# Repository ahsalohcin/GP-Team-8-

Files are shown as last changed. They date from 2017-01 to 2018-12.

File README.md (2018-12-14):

# Grand PrIEEE (senior year of undergrad, 2016-2017)

Led a team of 5 for IEEE-sponsored competition for designing a line-following RC car from scratch.

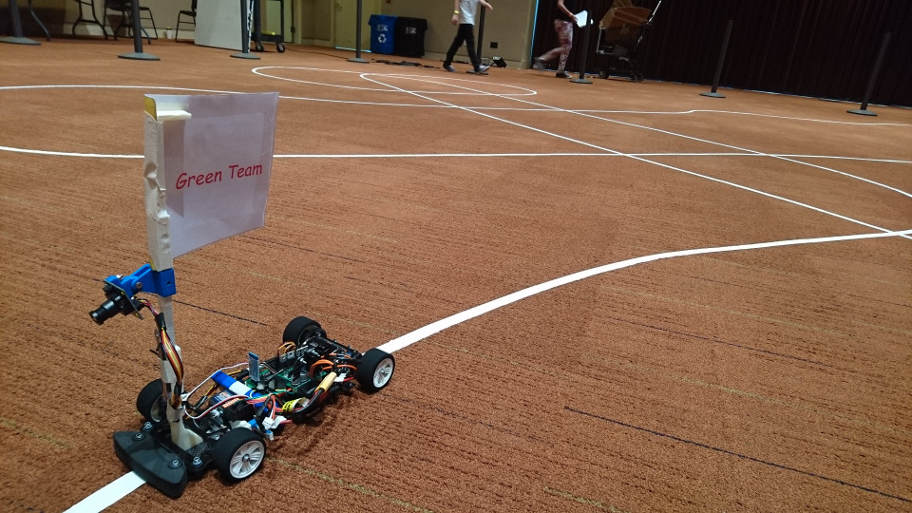
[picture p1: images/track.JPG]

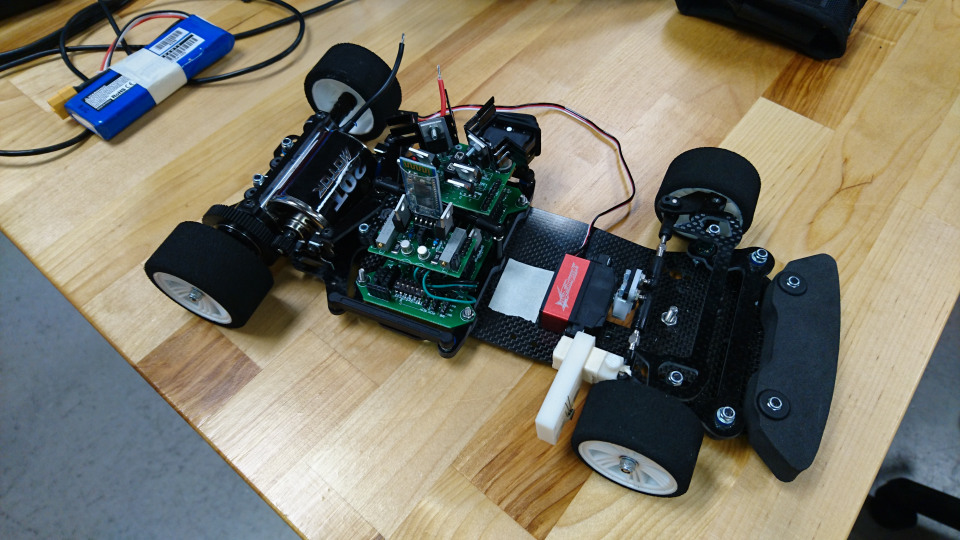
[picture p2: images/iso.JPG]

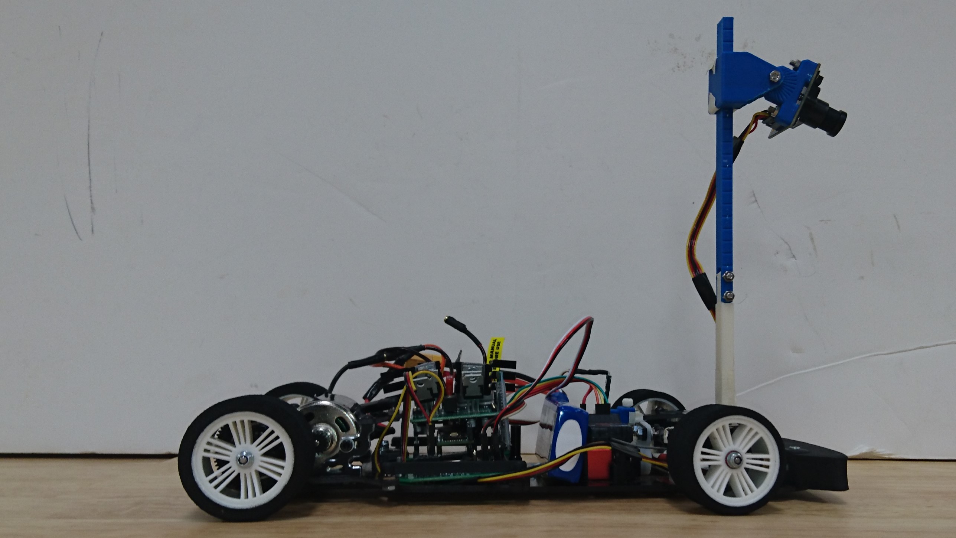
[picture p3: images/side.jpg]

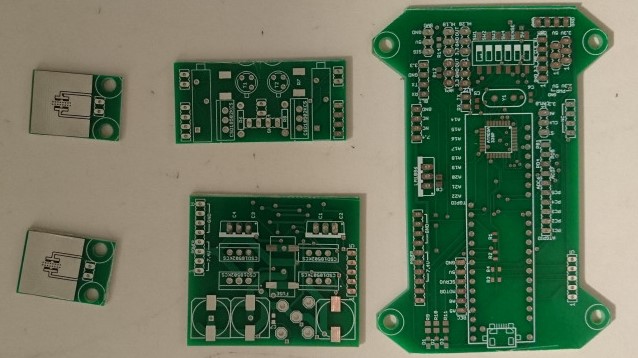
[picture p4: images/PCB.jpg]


## Competition videos: 
* UC San Diego (3rd place): https://www.youtube.com/watch?v=oybaJ443wYY 
* UC Davis (4th place):  https://www.youtube.com/watch?v=VBZ95nvLsOQ& 

## Overview: 
* 1/12 scale RC car + custom PCB
* __Microcontroller__: Teensy (Arduino based)
* __Sensors__: line camera and hall effect speed sensor
* __Actuators__: servo and brushed DC motor (with custom designed motor driver circuit)
* __Controllers__: PD for steering, PI for speed

## Skills learned: 
* Project management
* Design and integration (mechanical, electrical, and software)
* PCB layout
* Control design and tuning

## Main code: 
https://github.com/ahsalohcin/GP-Team-8-/blob/master/Code_5_7/GP_teensy/GP_teensy.ino

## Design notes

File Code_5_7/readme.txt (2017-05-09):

GrandPrIEEECode: the code used for Grand PrIEEE competition that got 36 sec and 3rd place.

vRef: 9.5 ft/sec. adding phone camera with same vRef got a 33 to 34 sec runtime. 

Batt voltage: ~ 8.1 V
Camera setting: 5th notch down
Looptime: 
Line detection: median filter using 5 elements. 
Line widths: 1 - 15 pixels.
Slightly faulty line loss handling. Always goes left. Not using time averaging. 

Steering Kp: 9.84 
Speed Kp: 3.0 Ki: .05
Slow down on turns: speed drop is proportional to curvature, with a slope of 2.5, and maximum drop of 2 ft/sec

Operation:

Turn on Teensy switch. Turn on transmitter. Right joystick max up. Turn on big switch. Expect slight rev, then pause. Release right joystick to start. Adjust vRef using Dip switches

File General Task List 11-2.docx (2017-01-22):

ems level diagram. Hardware showing voltages/currents/signals, and software showing communication General Task List

11/2

- Good, detailed syst and calculations/functions. As much detail as possible.
- Evaluate whether motor driver design is good enough.
  - Establish nominal and extreme load cases
    - Conduct simulation in SPICE
    - Hand calculations to prove that overcurrent, overheating, or other malfunctions won’t happen to FETs.
    - Prepare for motor driver circuit testing: test plan with objective, parts, tools, procedure.
      - Learn how to use gate drivers
      - Write code to control motor speed
      - Obtain test load that simulates motor ( R, L, V_induced (if possible))
      - Assemble circuit
      - Find breaking point
- Choose speed feedback method
  - Optical or magnetic encoder
  - Hall effect sensor
  - Back-EMF from motor
- Track down connector for camera
- Optimize code for light input for speed and robustness
  - Look at output from O-Scope
- Determine what/how to store line data
- Determine what/how to store track data
  - Goals:
    - Take very little time between memory and performance modes.
    - Remember track after power down.
    - Allow it to speed up coming out of turns and slow down before turns.
- Determine what raspberry pi zero accessories we need to use it. For testing (our own use) or for implementation on the actual car.
  - Adjust steering coefficients wirelessly from camera without needing to turn off code
    - Kp/ Ki/ Kd, for steering and speed.
  - Have a remote kill switch that
    - Cuts power to motor driver and remembers track
    - Cuts power to everything
  - Make sure it powers down safely
- Look for a better chassis: braking options, lower weight or lower center of gravity
- Find cheaper place to buy motor
- Find battery

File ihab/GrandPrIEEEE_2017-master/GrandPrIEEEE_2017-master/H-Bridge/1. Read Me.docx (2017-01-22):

Motor Driver:

- Switches:

The first step to designing the motor driver is selecting the type of switches to use. You should start online by looking up H-Bridge basics (try modularcircuits). You don’t have to dive too deep into MOSFETS. Get a solid understanding of the basic concepts that will allow you to look at a datasheet and have an idea of what the different parameters mean, and why you should select certain specs to improve the performance of your motor driver (H-Bridge).

When you are done reading about MOSFETS, you should know what PWM, VGS, VDS, ID, RDS-ON, input capacitance mean, and how they can influence the switching characteristics of the MOSFET. You should also get a basic understanding of the heat dissipation characteristics such as Thermal Resistance Junction to Case (RθJC) and Thermal Resistance Junction to Ambient (RθJA). This will help you select the proper heatsinks to make sure you don’t see magic smoke

You should also be familiar with BJTs but in a much more basic way. Just know how to bias them to turn on and off, for both NPNs and PNPs. You may need to bias your MOSFETS using BJTs if you decide to not go with a gate driver.

Moreover, read up a bit on Schottky diodes. In particular, their use in H-Bridges to prevent “fly-back” current. MOSFETS typically have built in diode-like behavior (see datasheets). However, depending on your design, it may be important to use external ones.

A quick google search can get you going. I have also included a summary of some useful info that I found online, but it is incomplete. You should not go over that until AFTER you have done your research.

I have included some datasheets for NMOS and PMOS by Fairchild, as well as other components for you to look at. Keep in mind, those might be good for testing but if you decide to make a PCB, you will need to spec out some surface mount ones. But at that point, you should know what you are doing.

Your next step will be to look into gate drivers (more to be added).

Grand PrIEEE 2017 Salameh UC San Diego Updated 10/26/2016

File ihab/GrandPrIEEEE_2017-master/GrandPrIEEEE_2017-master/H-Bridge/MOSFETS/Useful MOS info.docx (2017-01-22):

  - H-Bridge Components:
    - MOSFET:
      - Why choose NMOS?
        - NMOS has lower Rds-on than PMOS; therefore lower power dissipation
        - NMOS are faster than PMOS; because electrons travel faster than holes
        - PMOS are more immune to noise; but that is not an issue for this application
      - Which NMOS to choose?
        - Must handle enough current (conservative estimate Id>20A)
        - Must tolerate enough voltage (conservative estimate Vds>30V)
        - Heat dissipation & Switching Frequency:
        - Low Rds-on means lower power dissipation in form of heat
        - BUT, the lower rdson gets, the bigger the MOSFET becomes. The bigger the physical device is, the bigger it’s gate will be. The gate forms a capacitor towards the source and the drain. Since MOSFETs are voltage driven devices, their gate-source voltage has to be in a certain range (usually above 5-10V) to be fully turned on, and in another range (less than a volt or so) to be turned off. So, the on and off transient has to charge and discharge these parasitic capacitors. If you have only limited current available to drive the gate (and you always do), the higher the gate-capacitance is, the longer it takes to charge or discharge it
        - ALSO, MOSFETs have a low rdson when they are fully on, and they conduct almost no current when they’re are completely off. In both cases the dissipated power is relatively low. However when they transition between these two states, there will be a short period where rdson is relatively high, but not high enough to stop significant current from flowing through the device. In these transitional periods both the voltage drop on the device (due to rdson) and the current through it are significant, resulting in high power-dissipation. Naturally you would like to keep this transition time as low as possible from this perspective (we’ll talk later about reasons why you don’t want it to be too fast either), so a higher gate-capacitance will not be desirable. With a given gate-drive strength the gate capacitance limits the speed by which the element can be turned on and off, and thus poses an operating frequency limit

http://modularcircuits.tantosonline.com/blog/articles/h-bridge-secrets/mosfets-and-catch-diodes/

        - For an N-channel device however the picture is more complicated. If you connect the gate to ground or to source, the device is opened (gate-source voltage is below or equal to 0). But where to connect it to close the device? The power supply is not enough, since, when the device is closed (conducts current), it’s source and drain are roughly at the same potential. Since the drain is connected to power, the source will be at that potential as well, but than gate should be higher than that to keep the device closed. In fact at minimum 5V higher for so-called logic-level MOSFETs and 10-15V higher for normal MOSFETs. This is a significant problem, that voltage somehow has to be generated. In most cases some kind of a charge-pump is used for that, either in a stand-alone or a boot-strapped configuration. The latter however is only useful if the bridge is driven in the ‘locked anti-phase’ mode (see later). In any case, these high-side drivers usually cannot deliver as much current as a regular low-side driver can, which means longer turn-on and -off times for the high-side (lower current takes longer to charge-discharge the gate-capacitance). In high-frequency operation, where switching loss is a significant factor, a P-channel MOSFET might be a better solution because of this. In low-frequency, high-current operation, where switching loss is not a problem, but channel-resistance is, N-channel transistors are usually a better compromise.
          - http://modularcircuits.tantosonline.com/blog/articles/old-h-bridge-secrets/part-1/
        - The junction-to-ambient thermal resistance, that tells you how much hotter the chip is than the air that surrounds the package
        - The junction-to-case thermal resistance, that tells you how much hotter the chip inside the package is than the outside of the case at a certain power dissipation
        - the maximum allowed junction temperature
        - When working with surface-mount packages, it is important to note that thermal characteristics are highly dependent on the actual PCB layout. Take the traditional SO-8 package as an example (one typical FET datasheet is here for the FDS8447 (http://www.fairchildsemi.com/ds/FD/FDS8447.pdf)) You’ll see that with just the minimum amount of copper on the board the package has ~125oC/W thermal resistance. With a 6.5cm² (1in²) copper area, the same number is less then half of this, ~50oC/W. Let’s say now that the device itself can operate up to 150oC (this is called the maximum allowed junction temperature). If you can keep the surrounding temperature (called ambient temperature) below 50oC, you can can dissipate somewhere between 0.8W ((150-50)/125) and 2W ((150-50)/50) of power on the FET depending on your PCB layout.

Power MOSFET Basics: Understanding Gate Charge and Using it to Assess Switching Performance

Application note 608 – Vishay Siliconix

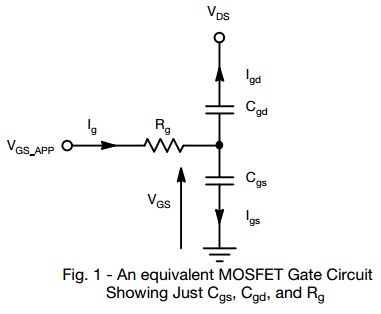
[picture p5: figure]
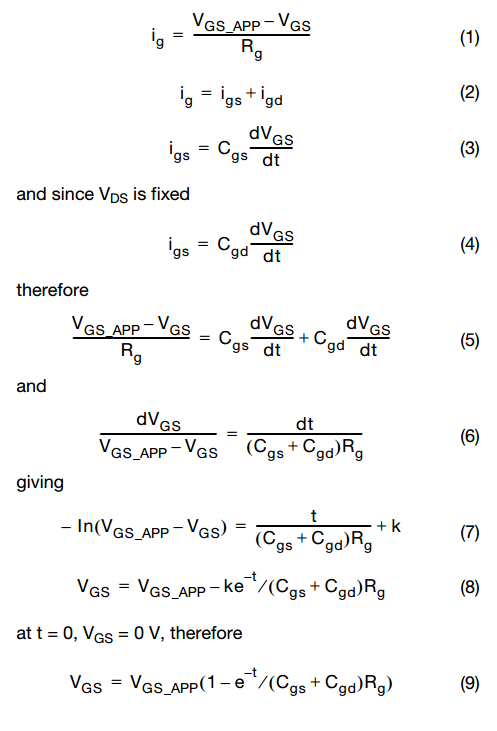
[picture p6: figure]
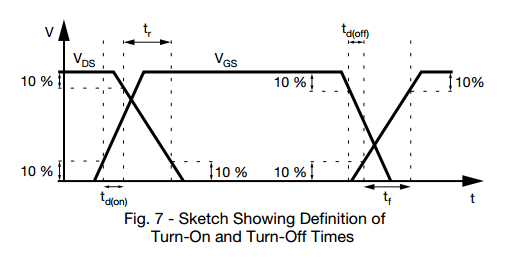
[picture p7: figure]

the switching times of the MOSFET are affected not only by the parasitic elements, but also by the driving circuit.

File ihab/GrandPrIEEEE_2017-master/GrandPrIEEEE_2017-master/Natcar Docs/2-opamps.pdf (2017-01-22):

### NATCAR – Background Information Lecture #1 – Operational Amplifiers

Prof. Richard Spencer

### Op Amp Circuits

- Review of basic op amp operation
- Negative feedback & virtual short circuit
- Gain circuits
- Frequency-dependent circuits
- Offsets
- Slew rate and full-power bandwidth

### Basic Op Amp Review

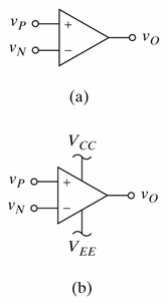
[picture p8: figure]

The power supply connections are not usually shown (but should be when you build and debug your circuits).

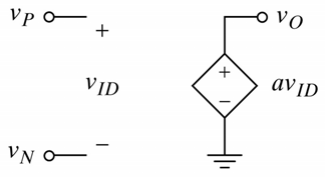
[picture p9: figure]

O | P | N ( | )
O | ID
v | av | v
v | av
= | −
=

The simplest circuit model is shown above and the output voltage is given by:

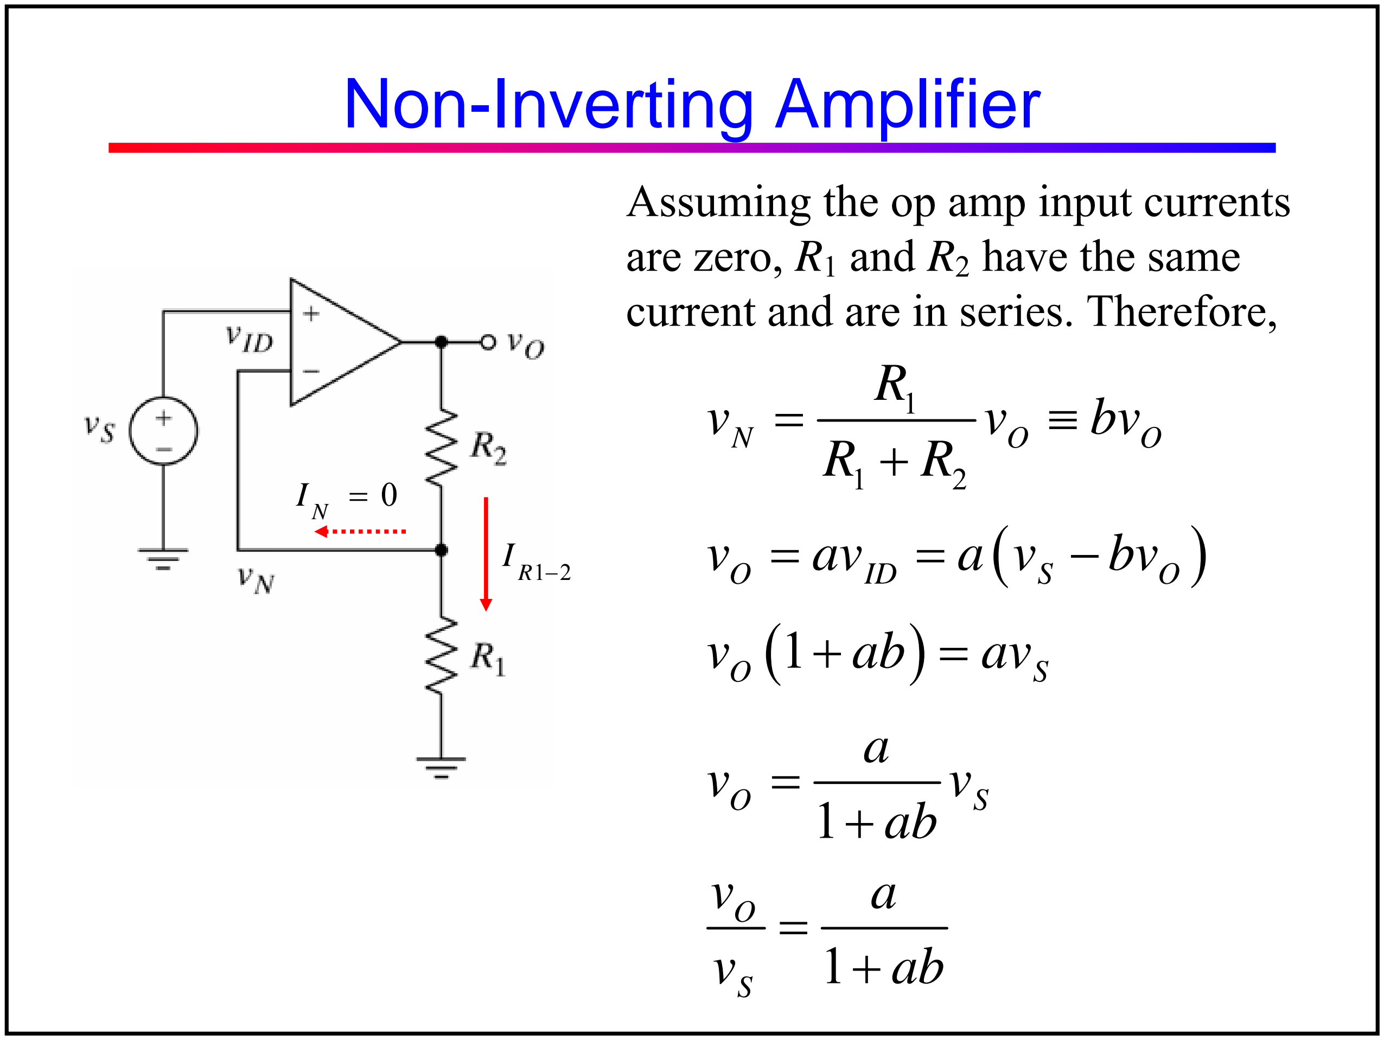
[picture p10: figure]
Non-Inverting Amplifier; Assuming the op amp input currents are zero, R1 and R2 have the same current and are in series. Therefore,

### Non-Inverting Amplifier

1

O

S

v | a
v | ab = +
1 | 2 | 2
1 | 1
1 lim | 1
a | 1
a | RR | R
→∞ | ab | b | R | R
⎛ | ⎞ | + ⎜ | ⎟ = = | =+ ⎝ | ⎠ +

Note negative feedback - key element

1

1 | 2
N | O | O
R v | v | bv
RR
= | ≡
+
v | a v | bv O | S | O = ( − | )

Assuming the op amp input currents are zero;

feedback factor

closed-loop gain

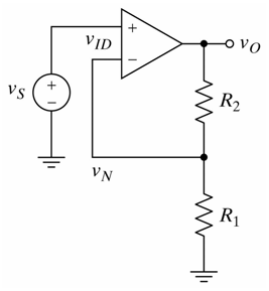
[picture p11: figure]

With an ideal op amp, the
gain is infinite, so

ab = loop gain

### Virtual Short Circuit

1

1 | 2
1) N | O | O
R v | v | bv
RR
= | ≡
+
2) v | av | a v | bv O | ID | S | O = | = | − ( | )
3) | 1 O | S

a
v | | v | | ab = +

We had;

Therefore;
1 1
1 | 1 ID | S | N | S | O | S | S
ab v | v | v | v | bv | v | v
ab | ab
⎛ | ⎞ | ⎛ | ⎞ =− =− | = | − | = ⎜ | ⎟ | ⎜ | ⎟ ⎝ | ⎠ | ⎝ + | + ⎠ NOTE:
as | , | 0 | VIRTUAL SHORT CIRCUIT ID a | v →∞ | → | ⇒

A virtual short requires negative feedback and large loop gain.

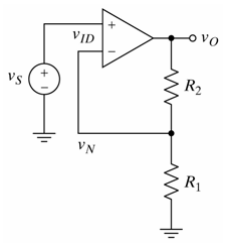
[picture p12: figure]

It is a “virtual” short because no current can flow through it.

### Virtual Short Circuit

We had;

Therefore;
1 1
1 | 1 ID | S | N | S | O | S | S
ab v | v | v | v | bv | v | v
ab | ab
⎛ | ⎞ | ⎛ | ⎞ =− =− | = | − | = ⎜ | ⎟ | ⎜ | ⎟ ⎝ | ⎠ | ⎝ + | + ⎠ NOTE:
as | , | 0 | VIRTUAL SHORT CIRCUIT ID a | v →∞ | → | ⇒

1

1 | 2
1) N | O | O
R v | v | bv
RR
= | ≡
+
2) v | av | a v | bv O | ID | S | O = | = | − ( | )
3) | 1 O | S

a
v | | v | | ab = +

### Virtual Short Circuit

The justification often given for the virtual short circuit (or virtual ground) is:
1) | O | ID v | av =
2) a →∞
3) must be finite Ov
4) | , | 0 ID ∴ v →

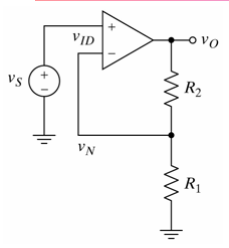
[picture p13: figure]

This syllogism is not valid! Note that reversing the signs on the opamp inputs would not affect the syllogism, but the result is clearly wrong in that case.
The problem is equivocation; | | | assumes that the opamp
operates in its normal region, while saying vo is finite requires that the output be saturated, and a approaches zero there!
| a →∞

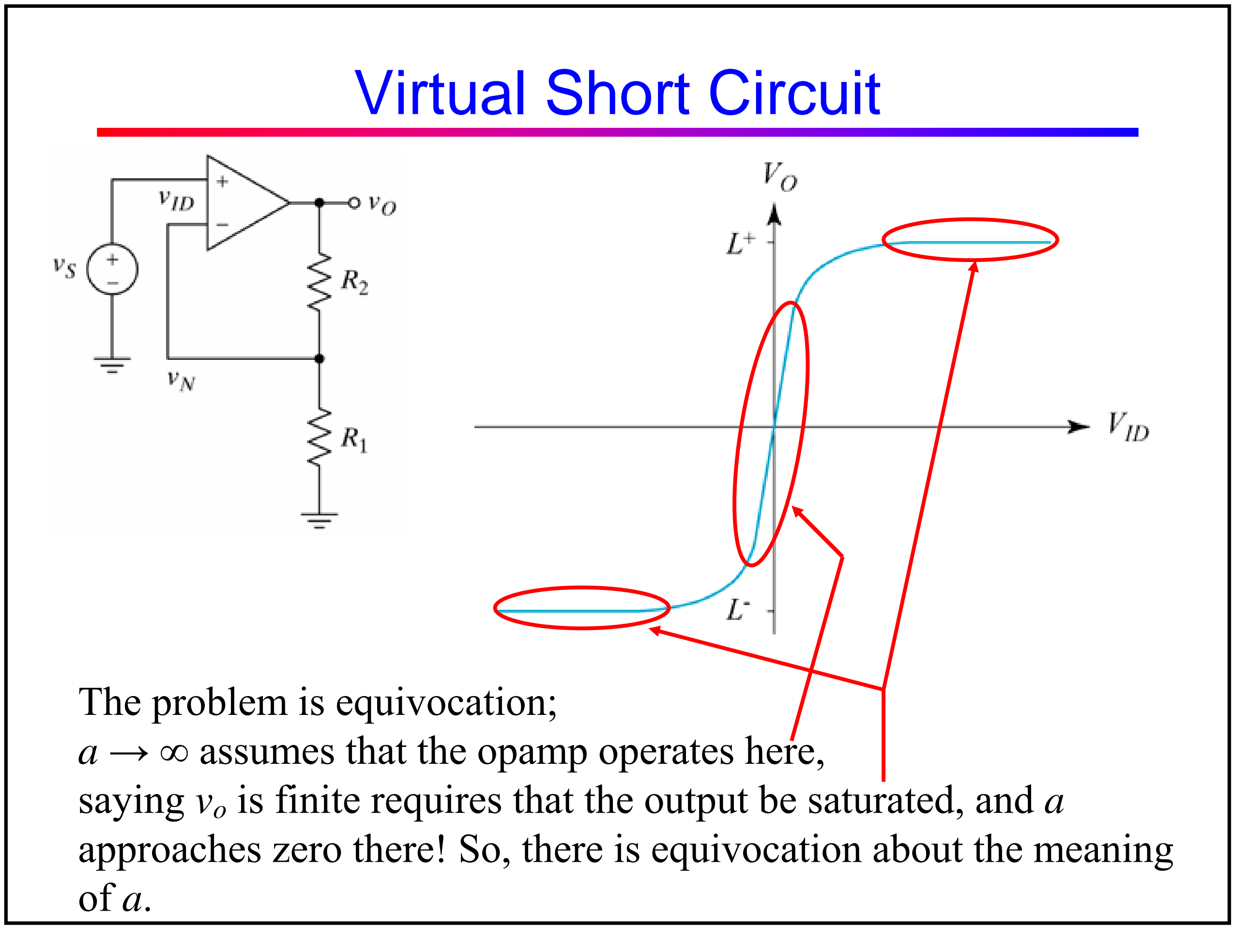
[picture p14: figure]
Virtual Short Circuit; The problem is equivocation;

a →∞ assumes that the opamp operates here,
saying vo is finite requires that the output be saturated, and a approaches zero there! So, there is equivocation about the meaning

### Inverting Amplifier

Negative feedback and large loop gain imply a virtual short (or virtual ground here), so

1
1
0 and | S
N | P | R
v v | v | i
R = = | =

No input current implies that

R1 | 2 R i | i =

so we obtain,

2

2
2
1
O | N | R | S
R v | v | iR | v
R

− =− =

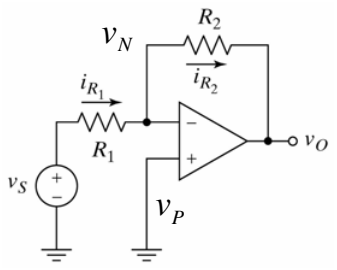
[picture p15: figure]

Note that the virtual ground allows us to think of the
operation as a V-to-I
conversion followed by an
I-to-V conversion.

### A Summing Amplifier

- Using this alternate view of the operation allows us to see how to make summing amplifiers:

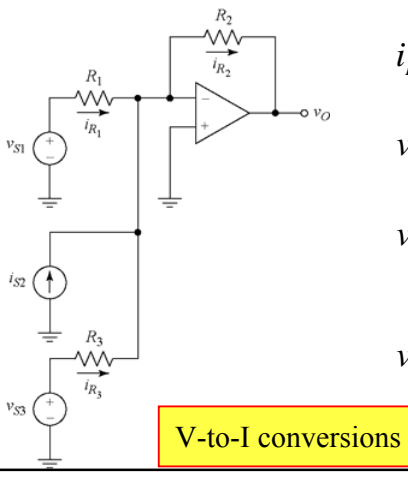
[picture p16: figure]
V-to-I conversions

R2 | 1 | 2 | 3 R | S | R i | i | i | i = ++
O | R22 v | iR = −
( | ) O | R | S | R 1 | 2 | 3 | 2 v | i | i | iR = − | ++
1 | 3
2 | 2
1 | 3
S | S
O | S
v | v v | i | R
R | R
⎛ | ⎞
=− | + + ⎜ | ⎟ ⎝ | ⎠
- I-to-V conversion

### A Low-Pass Filter (Integrator)

- The alternate view of the operation also allows us to see how to make low-pass filters (integrators):
O | FF | F 1 v | i Z | iZ = − | =−

1
1

S v i
R =

Therefore,

1

F
O | S

Z
v | v
R

− =

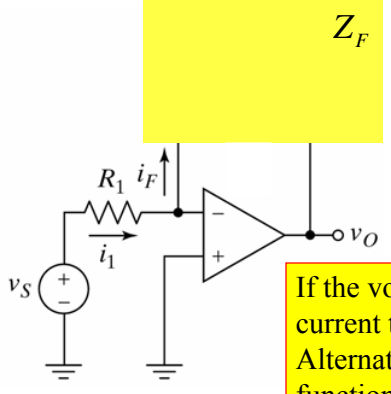
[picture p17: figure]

If the voltage across Zf is the integral of the current through it, we get an integrator. Alternatively, if we make Zf have a LP xfer function, we get a LPF. So, what do we use?

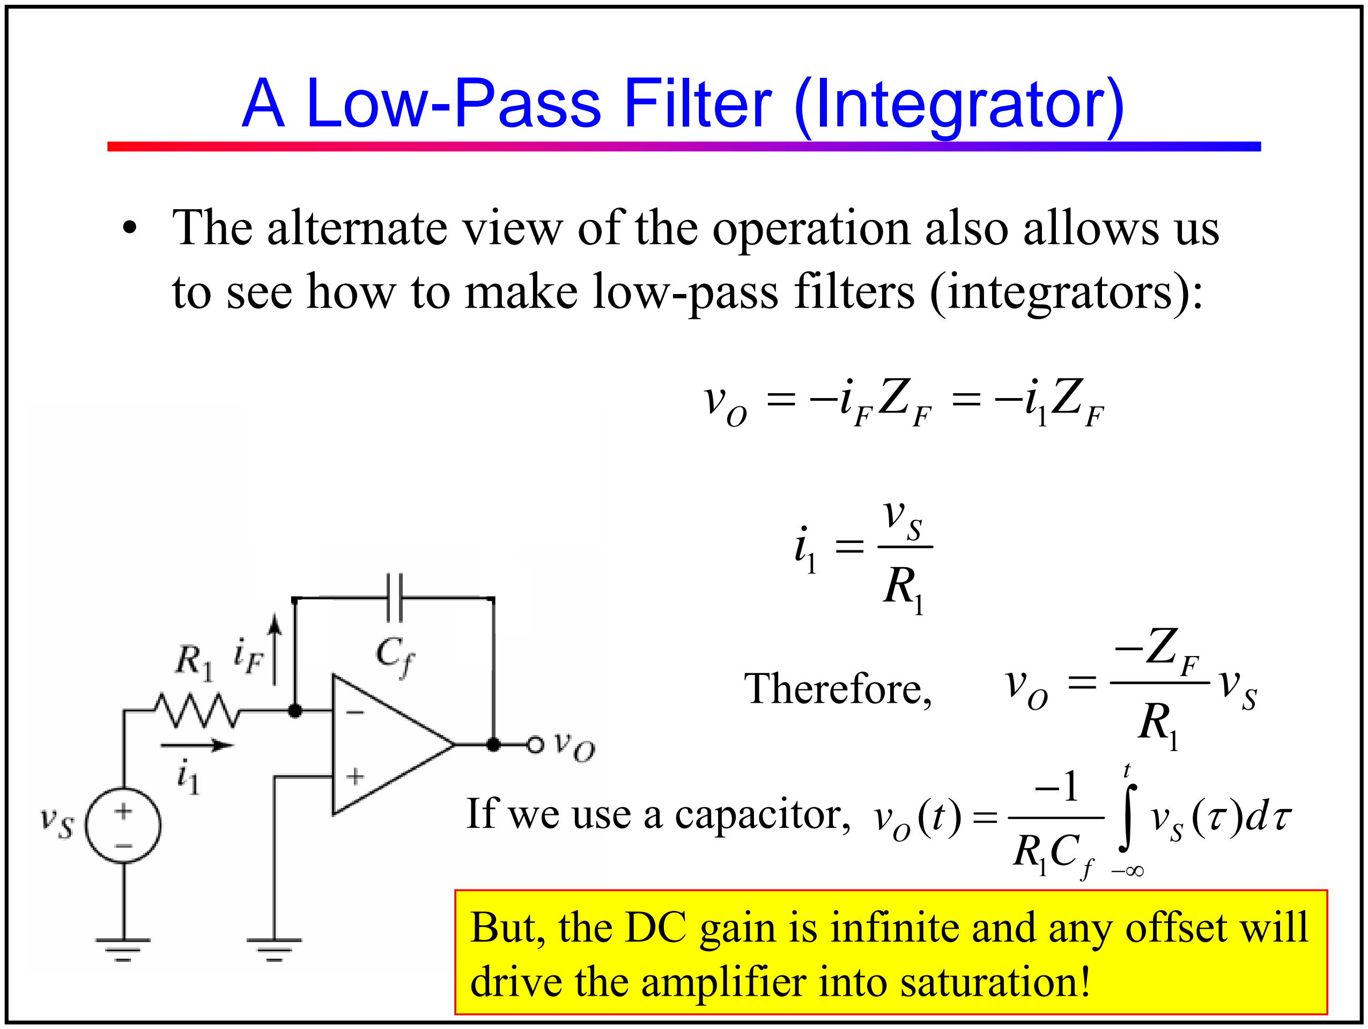
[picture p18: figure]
A Low-Pass Filter (Integrator); Therefore,; If we use a capacitor,; drive the amplifier into saturation!

- The alternate view of the operation also allows us to see how to make low-pass filters (integrators):

But, the DC gain is infinite and any offset will

### A Low-Pass Filter (Integrator)

- Therefore, we use a resistor in parallel with the capacitor to bring the DC gain down:
( | )
( | )
1 | 1
1 | 0

1

1 | 1
O | F | f
S | ff

f

ff
p
v | Z | | R
v | R | R | j RC
| | RR | A
| | j RC | j ω
| | ω | ω
ω
− | − = | = | +
− = | = + | +

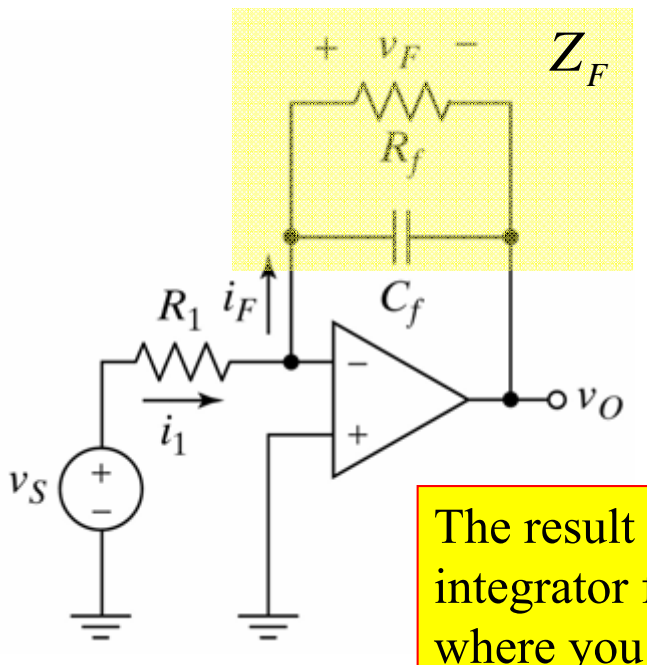
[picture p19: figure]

The result is a LPF, but a LPF looks like an integrator for frequencies well above the pole where you can ignore the ‘1’ in the denominator.

0
1
1 where | and f

p
f f
R A | R | R C =− | = ω

### A High-Pass Filter (Differentiator)

- Similarly, we see how to make high-pass filters (differentiators):
O | Ff | f 1 v | i R | iR = − | =−

1
1

1

1

S | S

S

v | v i
Z | R
jωC

= =
+

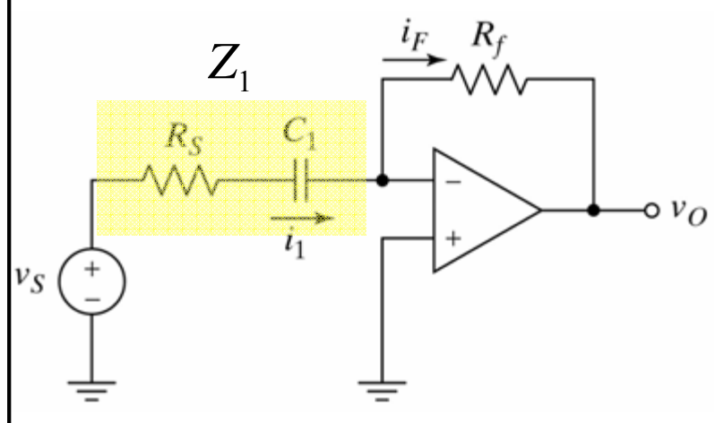
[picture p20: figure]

Therefore,
1
1 1
O | f
S | S
v | j RC
v | j RC ω
| ω

− = +

1
1
1 1 | S
S
j C i | v
j RC

ω
ω = +

### The HPF as a Differentiator

- We can see how this circuit functions as a differentiator (approximately) by assuming that RS is negligible (i.e., we can ignore the voltage drop across it):
Then | 1 | 1

S dv iC
dt

≈

and

1 | 1

S
O | f | f
dv v | iR | R C
dt

=− ≈−

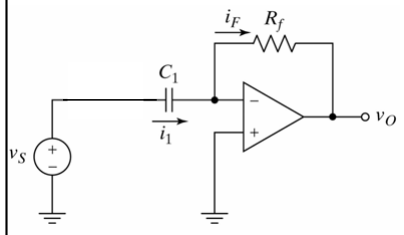
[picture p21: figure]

Note that a perfect differentiator does not have any poles, but we can’t avoid having one since RS = 0 is impossible.

### The HPF as a Differentiator

- We can see how this circuit functions as a differentiator (approximately) by assuming that RS is negligible (i.e., we can ignore the voltage drop across it):
Then | 1 | 1

S dv iC
dt

≈

and

1 | 1

S
O | f | f
dv v | iR | R C
dt

=− ≈−

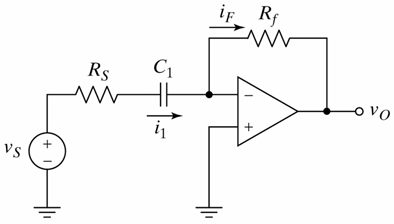
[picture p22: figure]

In addition, we want the pole to be there – increasing gain at high frequencies without limit is not desirable; we would just be amplifying noise.

### The HPF as a Differentiator

- We can see how this circuit functions as a differentiator (approximately) by assuming that RS is negligible (i.e., we can ignore the voltage drop across it):
Then | 1 | 1

S dv iC
dt

≈

and

1 | 1

S
O | f | f
dv v | iR | R C
dt

=− ≈−

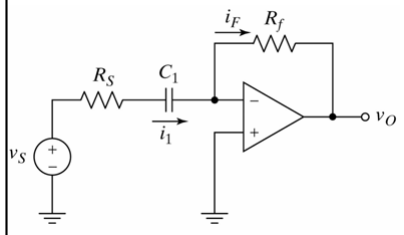
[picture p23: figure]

With the pole, the gain of this circuit asymptotically approaches –Rf /RS as the frequency approaches infinity. With small RS, you probably want to roll that off again at higher frequencies!

### Real Integrators & Differentiators

- To summarize about integrators & differentiators:
- We cannot build a real integrator, it would have infinite DC gain and would saturate. But, a single-pole low-pass filter (LPF) is indistinguishable from an integrator when used at frequencies well above the pole.
- Similarly, a single-pole high-pass filter (HPF) is indistinguishable from a differentiator when used at frequencies well below the pole frequency. Real differentiation is undesirable because the continually increasing gain at high frequencies amplifies noise.

### Input Bias Currents

- All real op amps have non-zero input bias currents
- We model these as current sources as shown in part (b) of the figure below

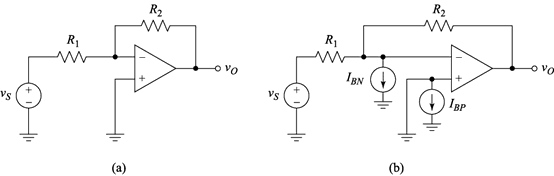
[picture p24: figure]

- Note that if vS = vO = 0, IBN “sees” R1 in parallel with R2 to ground. Therefore, the bias currents will generate an input offset voltage.

### Input Bias Current Correction

- We can cancel the offset voltage produced by the input bias currents by adding a resistor, R3, set equal to R1 in parallel with R2 as shown below.
- In practice, the two bias
currents will not be equal,
nor will vS = vO = 0,
so there will still be
some error (this is the
input offset current),
but we can only correct

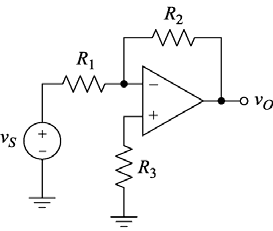
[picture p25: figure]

for the random difference in
the bias currents by individually trimming our circuits.

### Finite Bandwidth

All real op amps have a finite bandwidth. This limitation is a small-signal, linear phenomenon and is not at all likely to affect the operation of any circuits you build for this project.

### Finite Bandwidth

A simple way to model this limitation is to let the controlled source in the op amp circuit model have a single-pole low-pass transfer function. Note that all op amps have low-pass transfer functions and internally compensated op amps can be well modeled by single-pole low-pass transfer functions:

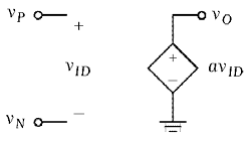
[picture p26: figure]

0

0

() 1

a aj | j
ω

ω ω = +

### Slew Rate & Full-Power Bandwidth

All real op amps also have a large-signal, nonlinear, limitation on how fast the output voltage can change. This is called the slew rate.

### Slew Rate & Full-Power Bandwidth

The slew rate is the maximum rate of change of the output voltage and is caused by having a limited amount of current available to charge some capacitor inside the op amp. When the output is too large at a given frequency, the desired output slope exceeds the slew rate and causes distortion. The frequency can be well below the small-signal bandwidth. If the output signal is a sine wave with the maximum possible peak-to-peak value, the frequency at which the slew rate limit first causes distortion is called the full-power bandwidth.

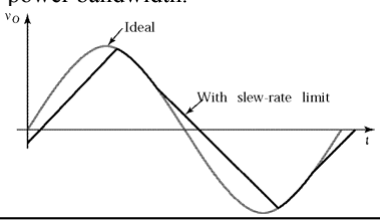
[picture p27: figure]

### When is Slew Rate Important?

- Whenever you require the output of an op amp to swing over a large range quickly you should check the slew rate – it is common to have a slew rate limitation affect the operation of a circuit at frequencies well below the small-signal bandwidth if the circuit has large signals.

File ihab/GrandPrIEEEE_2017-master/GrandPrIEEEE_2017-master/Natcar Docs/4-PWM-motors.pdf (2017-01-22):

### NATCAR – Background Information

### Pulsewidth Modulation (PWM) and DC Motors

Prof. Richard Spencer

### Outline

- Pulse-Width Modulation (PWM)
- Comparator with Hysteresis
- Relaxation Oscillator
- The 555 Timer
- Review of basic electromagnetics
- DC motor operation & modeling

### Pulsewidth Modulation (PWM)

- A PWM signal is frequently used for transmitting information and for motor speed control.
- PWM signals are characterized by their period, T, which may or may not vary, their pulsewidth, PW, which does vary, and their voltage levels.

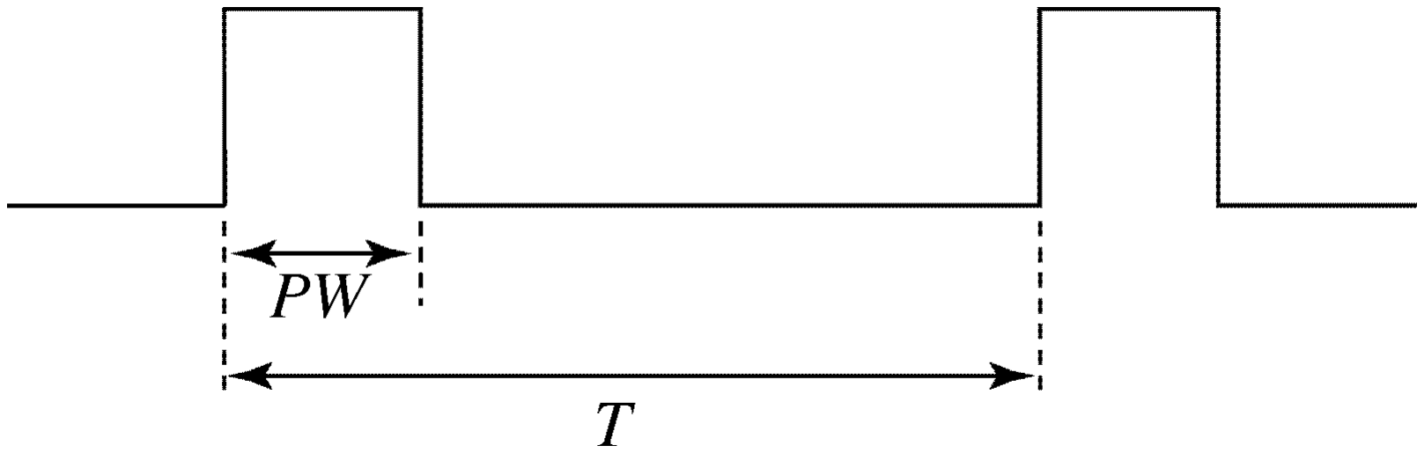
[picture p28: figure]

### Comparator with Hysteresis - Circuit

To make a relaxation oscillator we need a comparator with hysteresis, as shown below. This circuit can be made with an opamp:


Comparator with hysteresis | Positive feedback produces hysteresis

2

1 | 2
P | O

O

R
v | v
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
P | N
Vv | v
v
Vv v

+

−

⎧⎪ | > = ⎨
⎪⎩ | <

Comparator with Hysteresis - Operation; To see the hysteresis in this circuit, start with vO high (so VP = bvO=VTH) and vI low, then increase vI. When vI reaches VTH, the output goes low and VP changes to VTL. Further increasing vI doesn’t change vO. Now reduce vI; this time, the threshold is at VTL, and vO goes

high when vI drops below VTL. Comparator with hysteresis

Relaxation Oscillator; Comparator with hysteresis; Relaxation oscillator; discharged between two levels. Start at t = 0- with vO low:

The basic principle of a relaxation oscillator is shown here. A capacitor is alternately charged and

### The 555 Timer

The 555 IC can be used to make an astable multivibrator (oscillator), a monostable (one-shot), a PW modulator and many other useful circuits.


### Astable Oscillator with a 555

2VCC/3; VCC/3

### Astable Oscillator with a 555

starts at t = 0, you get:

( | )
( | )

2

1 | 2
1 | 2

0.7
0.7
1 | 1
0.7 | 2

L

H

t | RC
t | R RC
f T | R | RC

=
= | +
== | +

2

2

2

2
3 | 3
1 ln
2
| 0.7

Lt
CC | CC RC

L

L

V | V
e
t | RC
t | RC

−
=

=−
=

Assuming discharge

You find tH in the
same way, so we get:

### One-Shot with 555

You can use a 555 astable to trigger the one shot.

### PWM with 555 Timer

- You can use the 555 one-shot circuit and vary the control voltage, the resistor, or the capacitor to change the pulse width.
- You can also build your own PWM circuit with a linear ramp and a variable threshold comparator. Custom PWM circuits may be more linear and have larger ranges.

### PWM for the Steering Servo

- Standard radio-control (RC) car servos use a
PWM control signal.
- You can drive them with a fixed or variable period PWM signal, all that matters is the pulse width and the voltage levels.
- Your servos can be supplied by a 5 or 6 volt supply (6 volts makes the servo faster, but > 6 volts will damage it).
- The PWM input signal is 0 to 5 volts. Typically, varying the PW from 0.5 ms to 2.5 ms causes the servo to turn lock-to-lock.

### Basic Electromagnetics

- We will be dealing with motors and magnetic sensing. Therefore, we need to go over very basic electromagnetics.
- An electric current, I, produces a circular magnetic field with a magnetic field intensity, H, given by the law of Biot-Savart and the right-hand rule:


2 4

## R IdL a dH

π R

×
=

## G G G

### Electromagnetics Continued

- The magnetic field intensity is analogous to the electric field intensity, E. The magnetic flux, Φ, is analogous to the electric current, I, and the flux density, B, is analogous to current density, J. The flux density is B = μH, where μ is the permeability (similar to conductivity). The flux is Φ = B·area
- The electromotive force, emf, is given by Faraday’s law and opposes the change that produced it: emf = − dΦ/dt
- The Lorentz force on a charge is
F qE v B = ( +× ) G | G | G G

### DC Motor Operation

F qv B = × G G G

- DC motors use the Lorentz force on a moving charge in a magnetic field. Assume no electric field.


- Multiple wires mounted on a rotor will produce torque.


### DC Motor Construction

- The magnetic field can be produced by an electromagnet called the field winding, or by a permanent magnet. Our motors are permanent-magnet DC motors.
- Brushes are used to switch the current direction in the armature windings (see picture on next slide). This operation is called commutation.
- The torque produced is proportional to the current in the armature windings, , and the magnetic flux, Φ:

IA
T | kI m | A = Φ

### DC Motor Construction Continued


The brushes make contact with the slip ring and change the current direction as needed

### Permanent Magnet DC Motor

- As the armature rotates, a back emf is produced that is proportional to the flux and the angular velocity.
- The armature winding has resistance, inductance and the back emf, which leads to the electrical model shown:
B | m v | k = ′Φω


A
A | B | A | AA
di v | v | L | iR
dt

=+ +

Permanent Magnet DC Motor Continued

- Newton’s second law in rotational form says that the product of the moment of inertia, Jm, and the rotational acceleration, equals the net torque;

where Tm is the motor torque, TL is the load torque and b is the equivalent damping constant.
- In steady-state operation, the time derivatives are zero and we get

and

m
m | m | L | m
d J | TTb
dt
ω⋅ | = −− ω
V V | IR A =+ B | AA | T | Tb m | L | m = + ω
Remember we had: T | kI m | A = Φ | B | m and v | k = ′Φω

Substitute for the current from the torque equation and use the equation we have for the back emf to get

which can be rewritten as

where the no load speed is

and the stall torque is

Permanent Magnet DC Motor Continued

A
O

V
k

Ω= ′Φ

1 M | M
O | S

T
T

Ω
+ = Ω

A
S
A

Vk T
R

Φ =

A m
A | B | AA | M
R T V V | IR | k
k
= + | = ΦΩ + ′ | Φ

### Motor Torque versus Speed

Note:
– That the current is largest when the speed and, therefore, the back emf are zero.
– That large stall torque is achieved with small armature resistance ⇒ high stall current.
– That both ΩO and TS are proportional to VA.


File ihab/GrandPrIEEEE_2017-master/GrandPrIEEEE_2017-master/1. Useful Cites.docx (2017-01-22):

UC Berkeley EE192 – one of the most useful!

http://www-inst.eecs.berkeley.edu/~ee192/sp14/schedule.html

FEEL FREE TO ADD MORE!

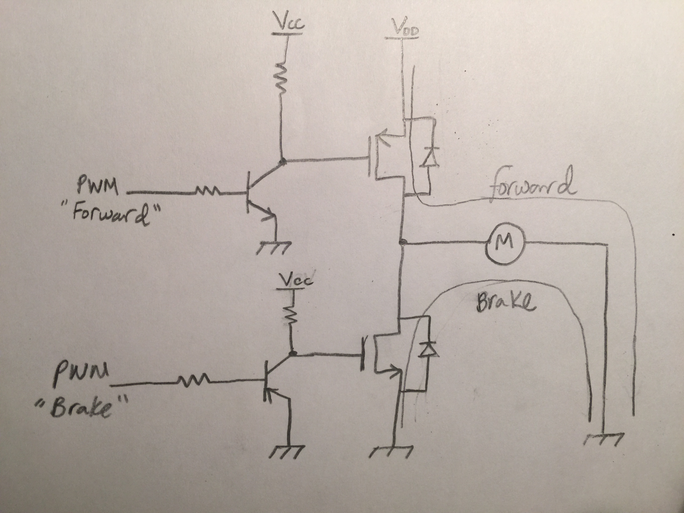
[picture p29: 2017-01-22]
ihab/GrandPrIEEEE_2017-master/GrandPrIEEEE_2017-master/H-Bridge/Half-Bridge.JPG

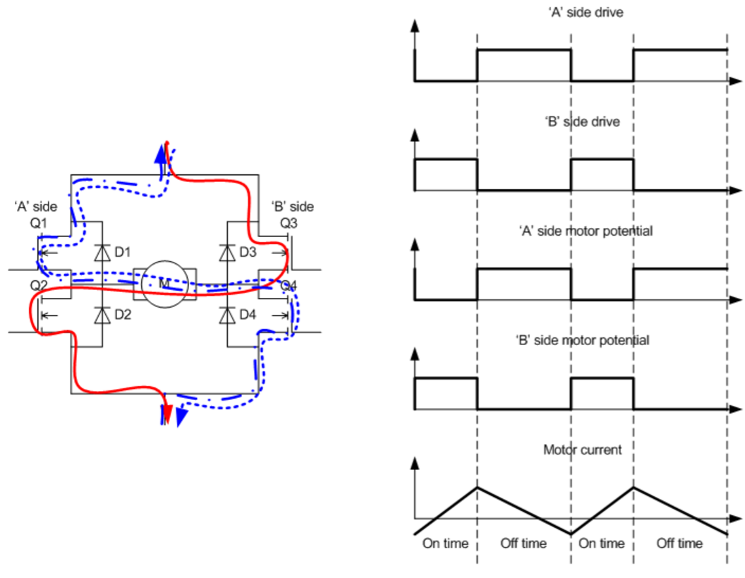
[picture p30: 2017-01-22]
ihab/GrandPrIEEEE_2017-master/GrandPrIEEEE_2017-master/H-Bridge/Drive Modes/Lock Anti-Phase.PNG

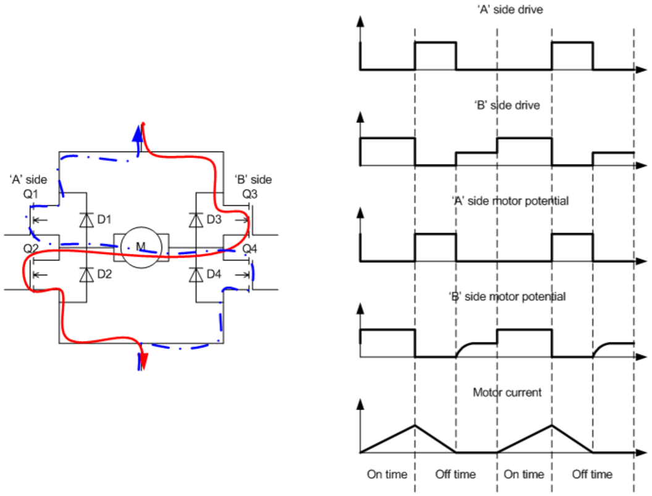
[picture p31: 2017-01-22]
ihab/GrandPrIEEEE_2017-master/GrandPrIEEEE_2017-master/H-Bridge/Drive Modes/Synchron Collapse.PNG

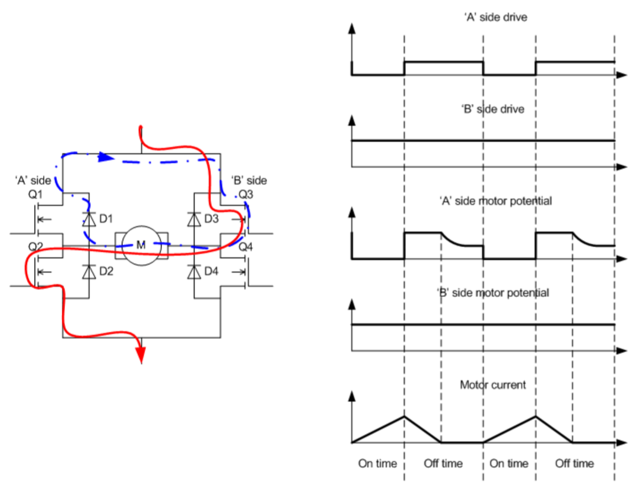
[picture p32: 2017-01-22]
ihab/GrandPrIEEEE_2017-master/GrandPrIEEEE_2017-master/H-Bridge/Drive Modes/Sign-Magnitude High-side.jpg

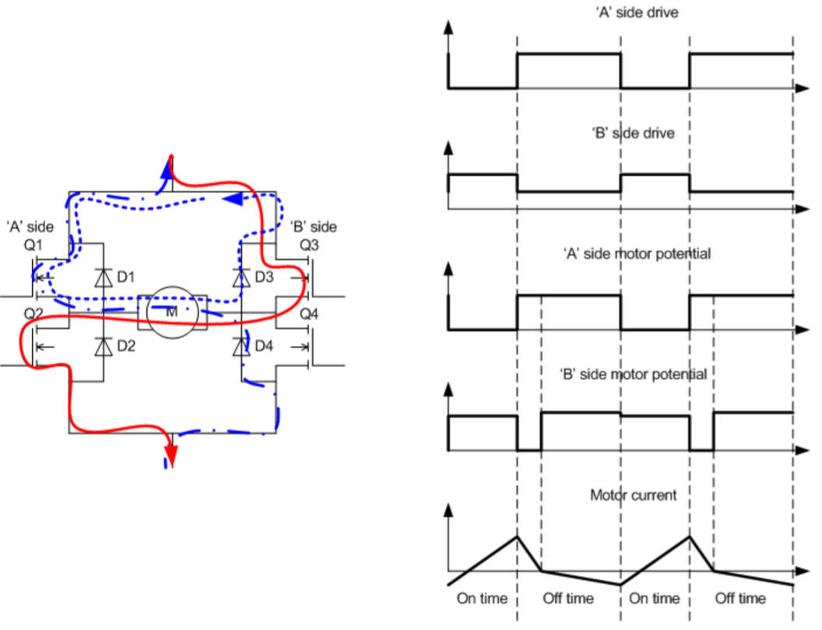
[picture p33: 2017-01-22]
ihab/GrandPrIEEEE_2017-master/GrandPrIEEEE_2017-master/H-Bridge/Drive Modes/Active Field-Collapse.PNG

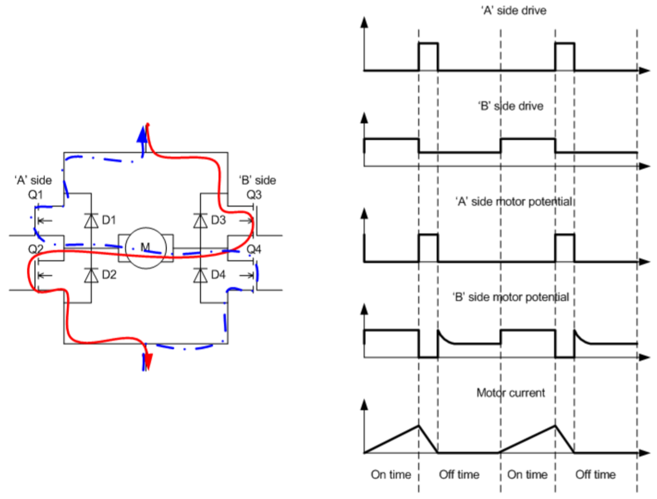
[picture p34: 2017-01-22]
ihab/GrandPrIEEEE_2017-master/GrandPrIEEEE_2017-master/H-Bridge/Drive Modes/Modified Active Field-Collapse.PNG

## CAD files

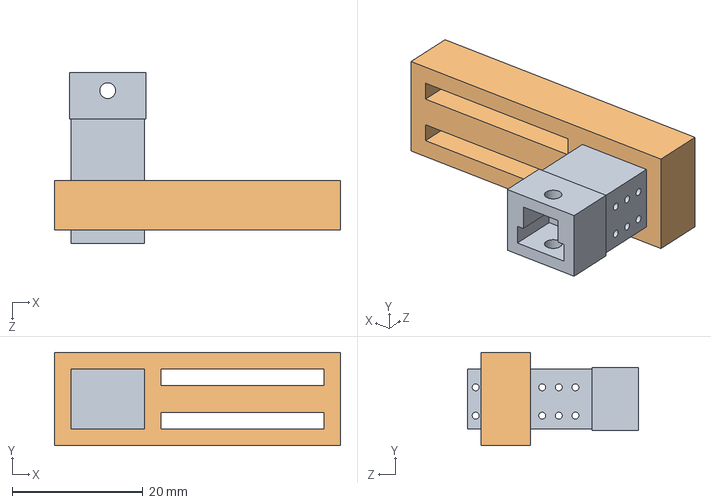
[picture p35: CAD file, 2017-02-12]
speedometer/hall effect mount nominal.SLDASM
43.7 x 14.2 x 26.2 mm
mount nominal
stick nominal

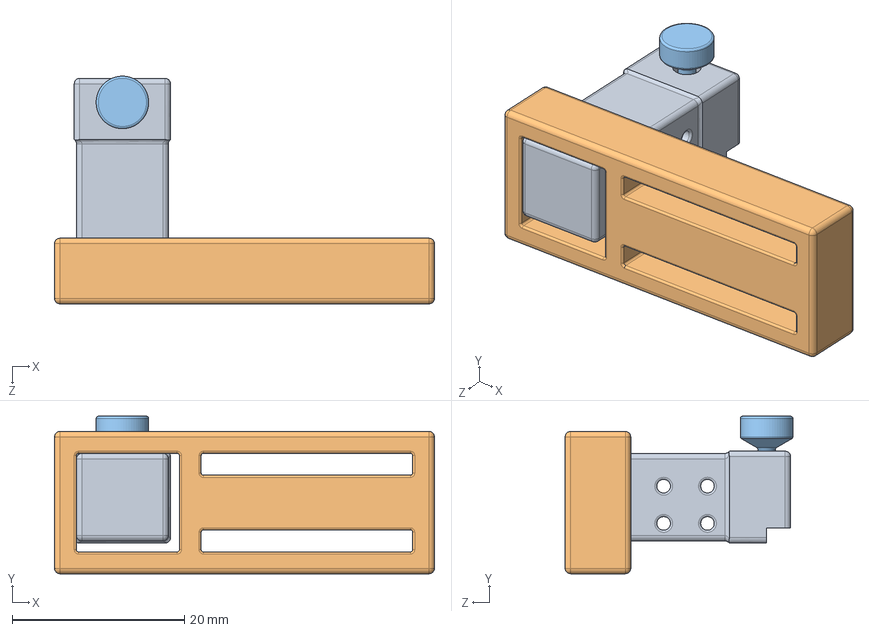
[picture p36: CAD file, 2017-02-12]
speedometer/print 2-4/pack and go 2-4/4 mil attempt 2-4.SLDASM
44.1 x 18.3 x 26.4 mm
mount 4 mil error
stick 4 mill error
pin 4 mill error

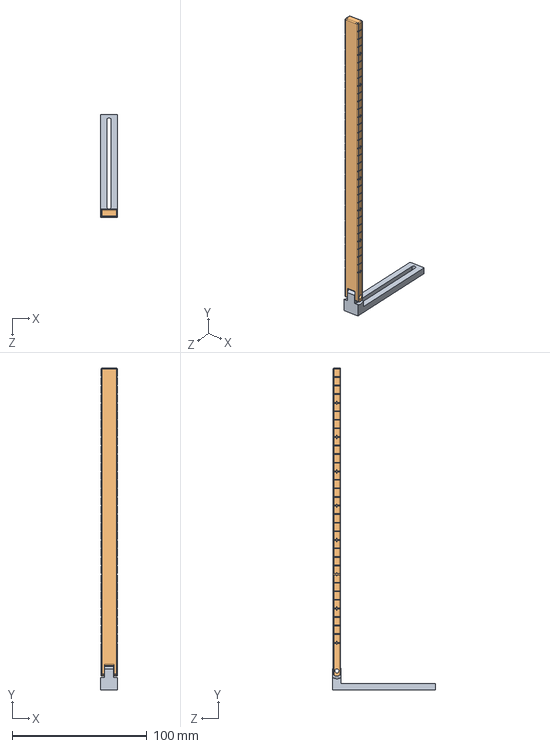
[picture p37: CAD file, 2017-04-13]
camera_mount_2016/tower.SLDASM
12.7 x 238.5 x 76.2 mm
camera mount tower base
camera mount tower

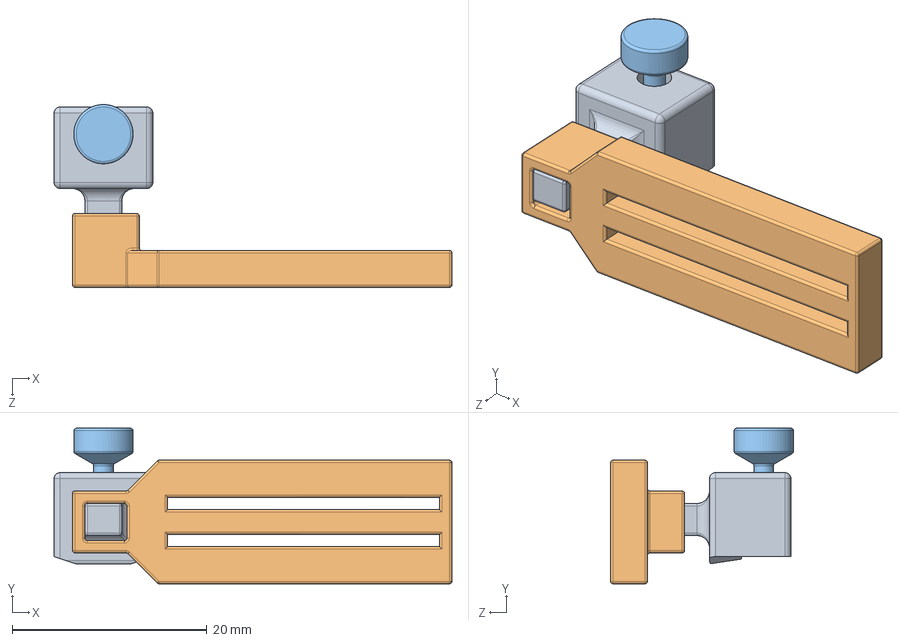
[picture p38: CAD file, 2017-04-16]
speedometer/2_mill_errorv3/assem 2 mill.SLDASM
40.9 x 16.0 x 18.8 mm
mount shorter 2 mill
stick 2 mill
pin 4 mill

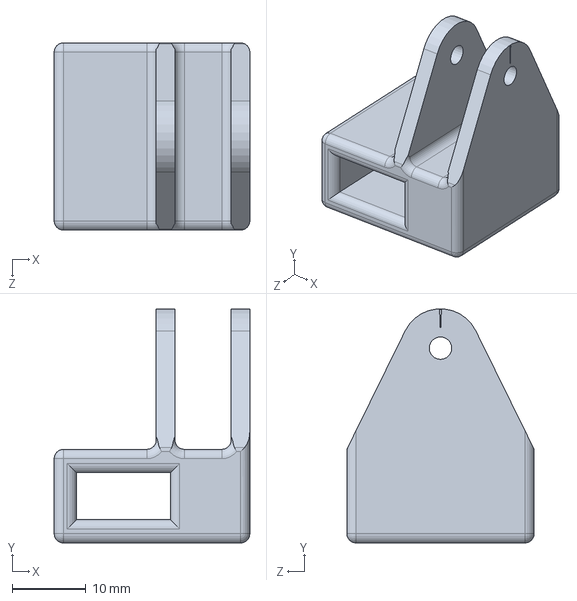
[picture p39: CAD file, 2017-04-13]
camera_mount_2016/part 2.SLDPRT
26.5 x 31.7 x 25.4 mm

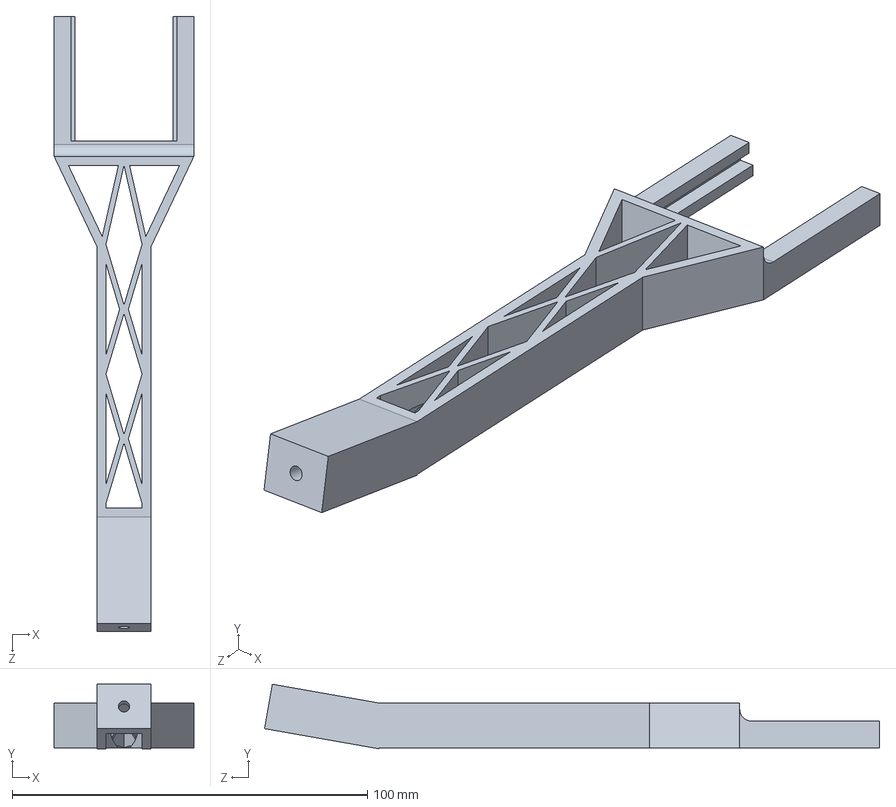
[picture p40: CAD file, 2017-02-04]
hardware/camMount/camMount20170203.SLDPRT
39.4 x 18.2 x 173.2 mm

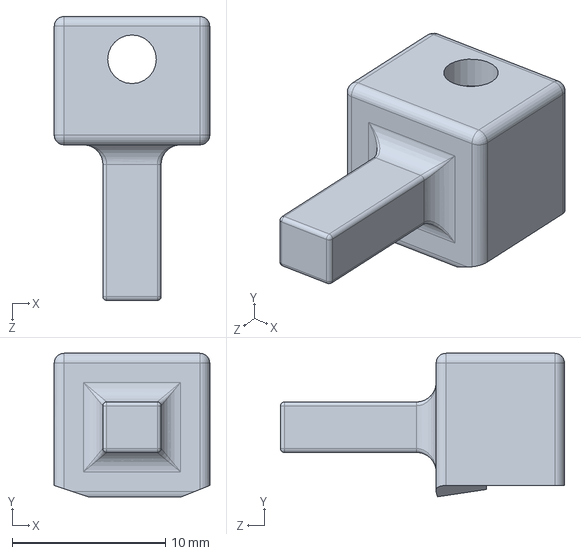
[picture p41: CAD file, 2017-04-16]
speedometer/2_mill_errorv3/mount shorter 3 mill.SLDPRT
10.2 x 9.37 x 18.5 mm

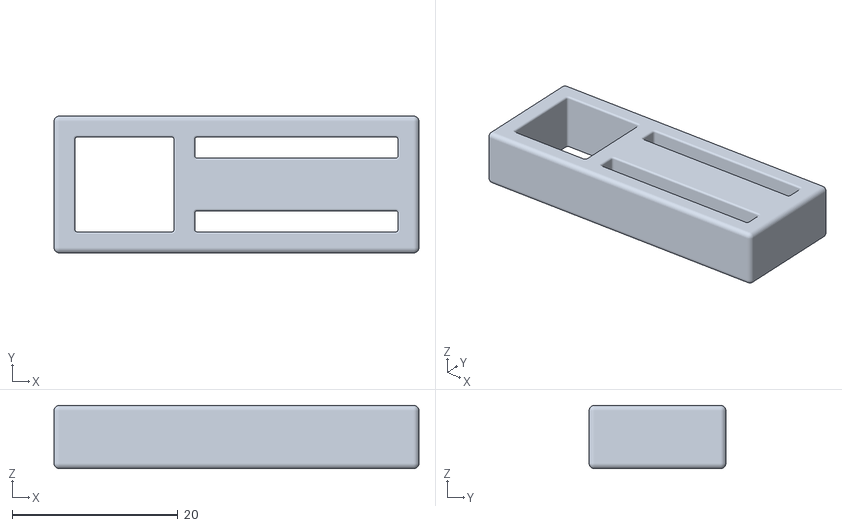
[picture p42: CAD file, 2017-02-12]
speedometer/print 2-4/pack and go 2-4/4 mil attempt 2-4 - stick 4 mill error-1.STL
44.1 x 16.5 x 7.62

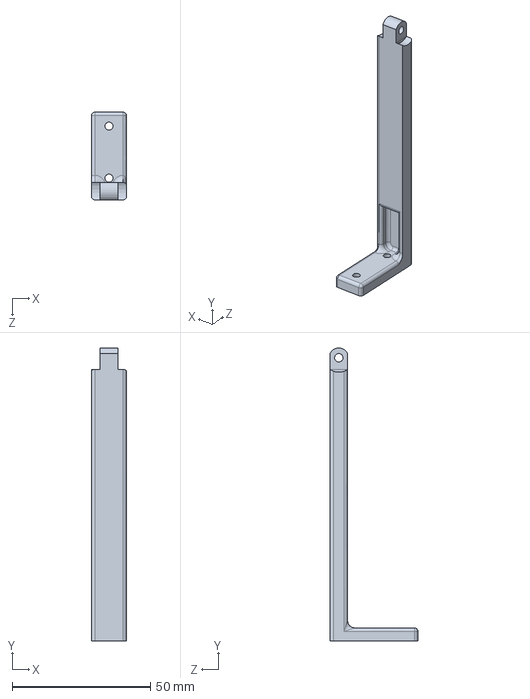
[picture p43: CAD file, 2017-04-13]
camera_mount_2016/taller base.SLDPRT
12.7 x 105.8 x 31.8 mm

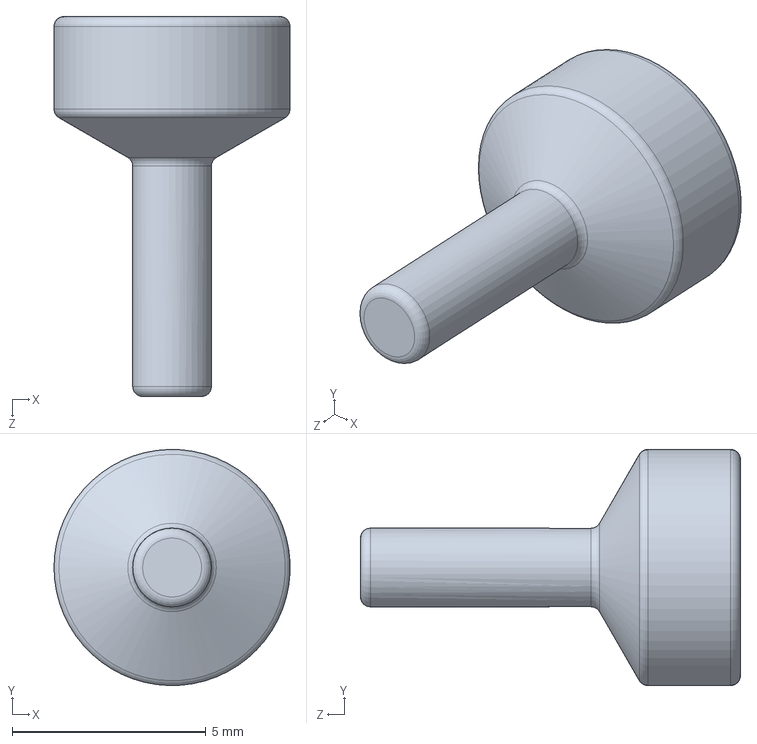
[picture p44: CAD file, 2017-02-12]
speedometer/pin 4 mill error.SLDPRT
6.09 x 6.09 x 9.81 mm

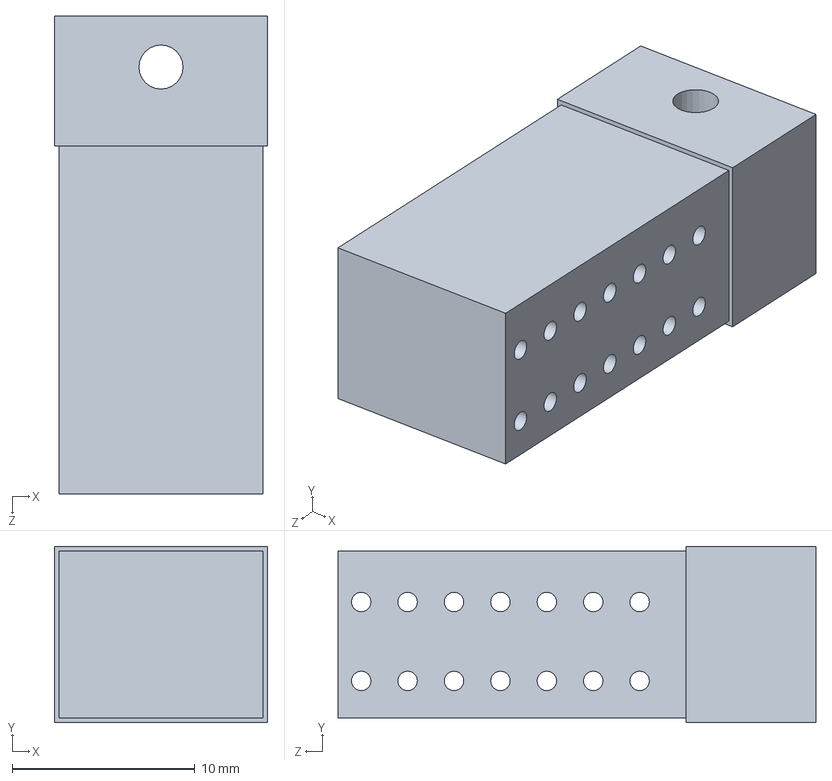
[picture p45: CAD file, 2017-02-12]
speedometer/mount nominal.SLDPRT
11.7 x 9.65 x 26.2 mm

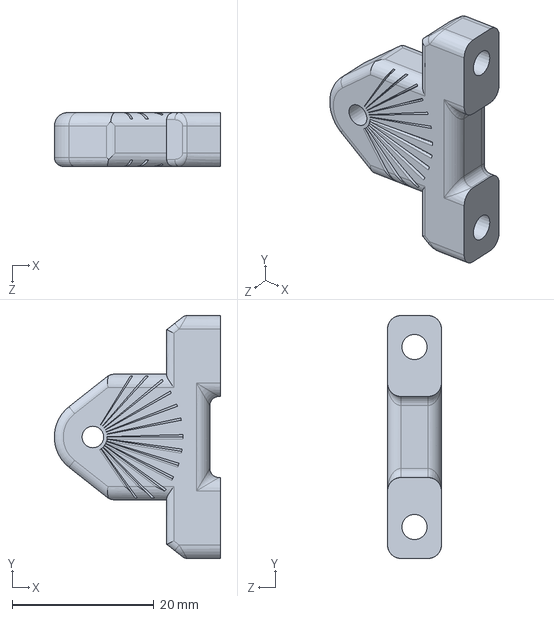
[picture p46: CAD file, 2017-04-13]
camera_mount_2016/triangle.SLDPRT
23.5 x 34.3 x 7.62 mm

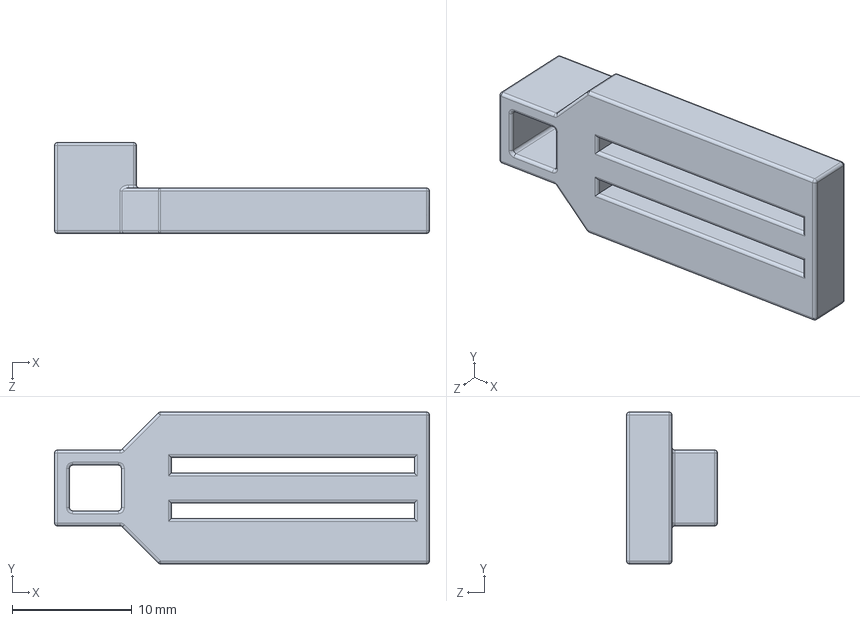
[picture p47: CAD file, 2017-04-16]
speedometer/2_mill_errorv3/stick 2 mill.SLDPRT
31.4 x 12.7 x 7.62 mm

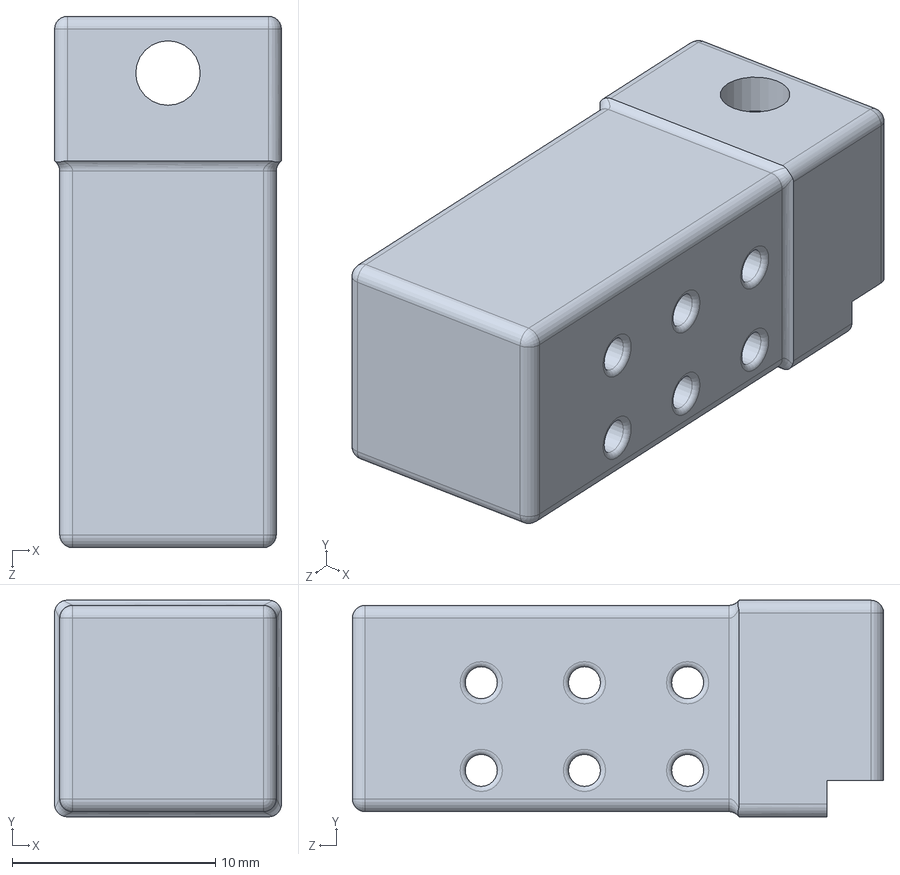
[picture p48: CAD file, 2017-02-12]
speedometer/print 2-4/pack and go 2-4/mount 4 mil error.SLDPRT
11.2 x 10.7 x 26.2 mm

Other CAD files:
speedometer/4 mil attempt 2-4.SLDASM
speedometer/2_mill_errorv3/mount shorter 2 mill.SLDPRT
speedometer/print 2-4/pack and go 2-4/stick 4 mill error.SLDPRT
camera_mount_2016/base.SLDPRT
camera_mount_2016/base.STL
camera_mount_2016/taller base.STL
camera_mount_2016/tower.SLDPRT
camera_mount_2016/tower.STL
camera_mount_2016/triangle.STL
hardware/camMount/camMount20170203.STL
speedometer/2_mill_errorv3/assem 2 mill (1).SLDASM
speedometer/2_mill_errorv3/mount 2 mill.SLDPRT
speedometer/2_mill_errorv3/mount 2 mill.STL
speedometer/2_mill_errorv3/mount shorter 2 mill.STL
speedometer/2_mill_errorv3/mount shorter 3 mill.STL
speedometer/2_mill_errorv3/pin 4 mill.SLDPRT
speedometer/2_mill_errorv3/pin 4 mill.STL
speedometer/2_mill_errorv3/stick 2 mill.STL
speedometer/2_mill_errorv3/stick left 2 mill.SLDPRT
speedometer/2_mill_errorv3/stick left 2 mill.STL
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

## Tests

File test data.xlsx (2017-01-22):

2017-01-15 |  | o-scope as input
 |  | ammeter in series with motor
 | wrong pp | 3.5 A turning on to 20% duty cycle
 |  | takes around 10% to begin turning
 | pp 3.3V | load | duty cycle | Amps | battery voltage 7.65 (turnigy) | V RMS
 | pp 3.3V | no load | 100% | 1.4 | 7.65 | 7.4
 |  |  | 20-30% | 7 | 7.61

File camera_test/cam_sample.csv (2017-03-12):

line_num: | 2851; | 94, | 94, | 94, | 95, | 95, | 95, | 97, | 97, | 97, | 99, | 101, | 102, | 104, | 106, | 106, | 107, | 108, | 109, | 109, | 110, | 109, | 110, | 111, | 112, | 113, | 114, | 114, | 116, | 116, | 118, | 118, | 121, | 123, | 122, | 125, | 126, | 128, | 130, | 132, | 137, | 137, | 137, | 140, | 143, | 144, | 148, | 150, | 153, | 155, | 158, | 161, | 163, | 166, | 169, | 172, | 176, | 179, | 182,
line_num: | 2852; | 93, | 94, | 94, | 95, | 95, | 95, | 97, | 97, | 98, | 99, | 100, | 102, | 104, | 106, | 106, | 108, | 108, | 109, | 110, | 110, | 109, | 110, | 111, | 112, | 112, | 114, | 114, | 116, | 116, | 117, | 118, | 120, | 124, | 125, | 125, | 126, | 127, | 129, | 132, | 136, | 136, | 138, | 140, | 144, | 144, | 146, | 150, | 153, | 156, | 159, | 161, | 165, | 166, | 169, | 172, | 175, | 178, | 182,
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

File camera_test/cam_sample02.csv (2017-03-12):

line_num: | 1; | 97, | 100, | 103, | 107, | 107, | 107, | 109, | 105, | 97, | 87, | 80, | 80, | 89, | 104, | 117, | 125, | 130, | 137, | 142, | 144, | 144, | 146, | 149, | 153, | 158, | 165, | 171, | 175, | 172, | 167, | 164, | 168, | 173, | 181, | 188, | 194, | 197, | 196, | 186, | 176, | 159, | 149, | 143, | 141, | 138, | 136, | 136, | 135, | 137, | 139, | 143, | 155, | 196, | 283, | 419, | 568, | 682, | 745,
line_num: | 2; | 101, | 101, | 96, | 89, | 80, | 76, | 79, | 89, | 102, | 113, | 121, | 127, | 132, | 135, | 139, | 142, | 143, | 145, | 145, | 146, | 146, | 149, | 153, | 158, | 166, | 177, | 188, | 201, | 208, | 216, | 214, | 203, | 183, | 162, | 148, | 144, | 141, | 141, | 141, | 141, | 139, | 140, | 143, | 151, | 175, | 259, | 400, | 562, | 693, | 750, | 757, | 761, | 759, | 762, | 767, | 766, | 757, | 712,
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

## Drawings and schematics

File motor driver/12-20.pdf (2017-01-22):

## MIC4604YM

## CSD18502KCS_KCS_3

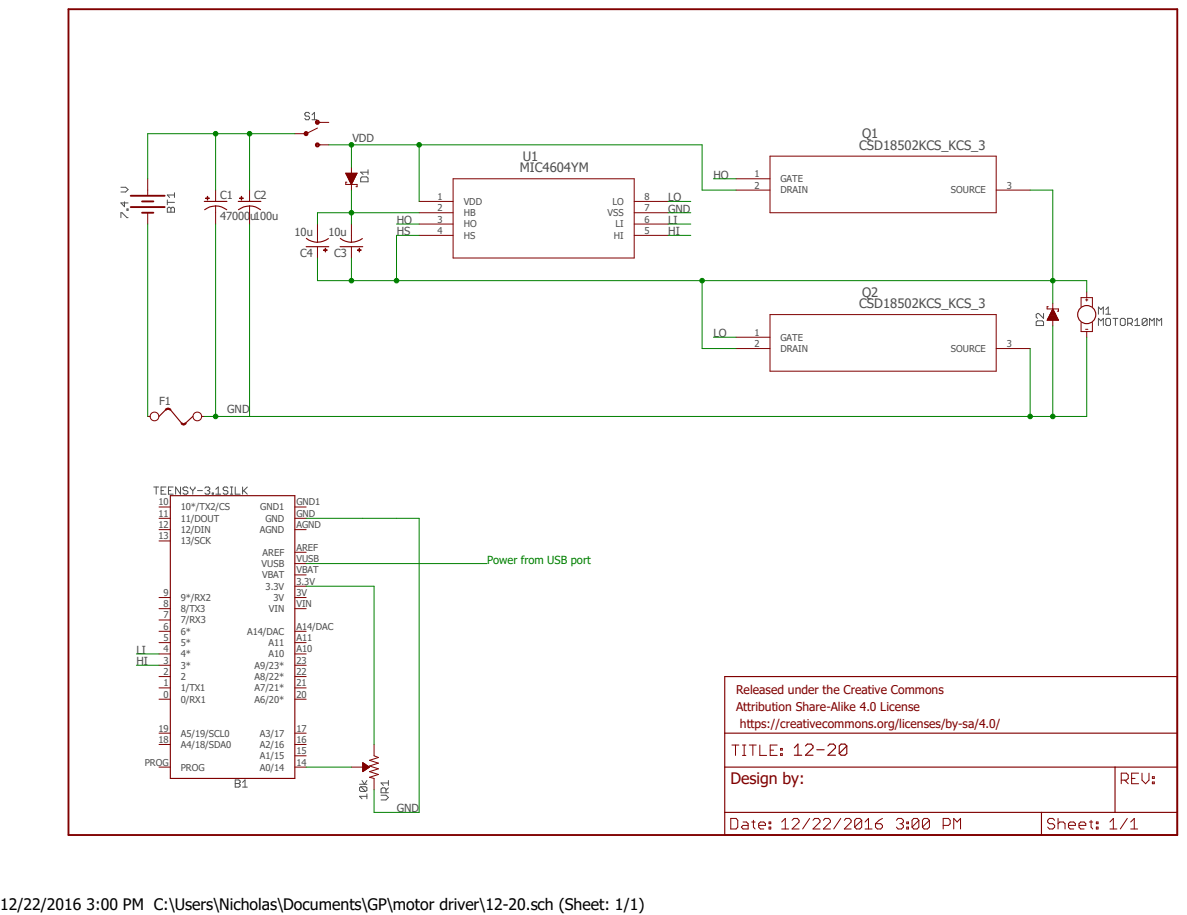
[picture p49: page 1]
CSD18502KCS_KCS_3; VDD 1; 6 VSS; GATE 1; DRAIN 2; SOURCE; GND1; GND; VBAT; VIN; AGND; 17 A4/18/SDA0 18; A5/19/SCL0 19; 10*/TX2/CS 10 11/DOUT 11 12/DIN 12 13/SCK 13; A11 A14/DAC; A14/DAC; AREF; AREF VUSB; VUSB; PROG PROG; VDD; Design by:

Power from USB port

Released under the Creative Commons
Attribution Share-Alike 4.0 License
https://creativecommons.org/licenses/by-sa/4.0/

12/22/2016 3:00 PM C:\Users\Nicholas\Documents\GP\motor driver\12-20.sch (Sheet: 1/1)

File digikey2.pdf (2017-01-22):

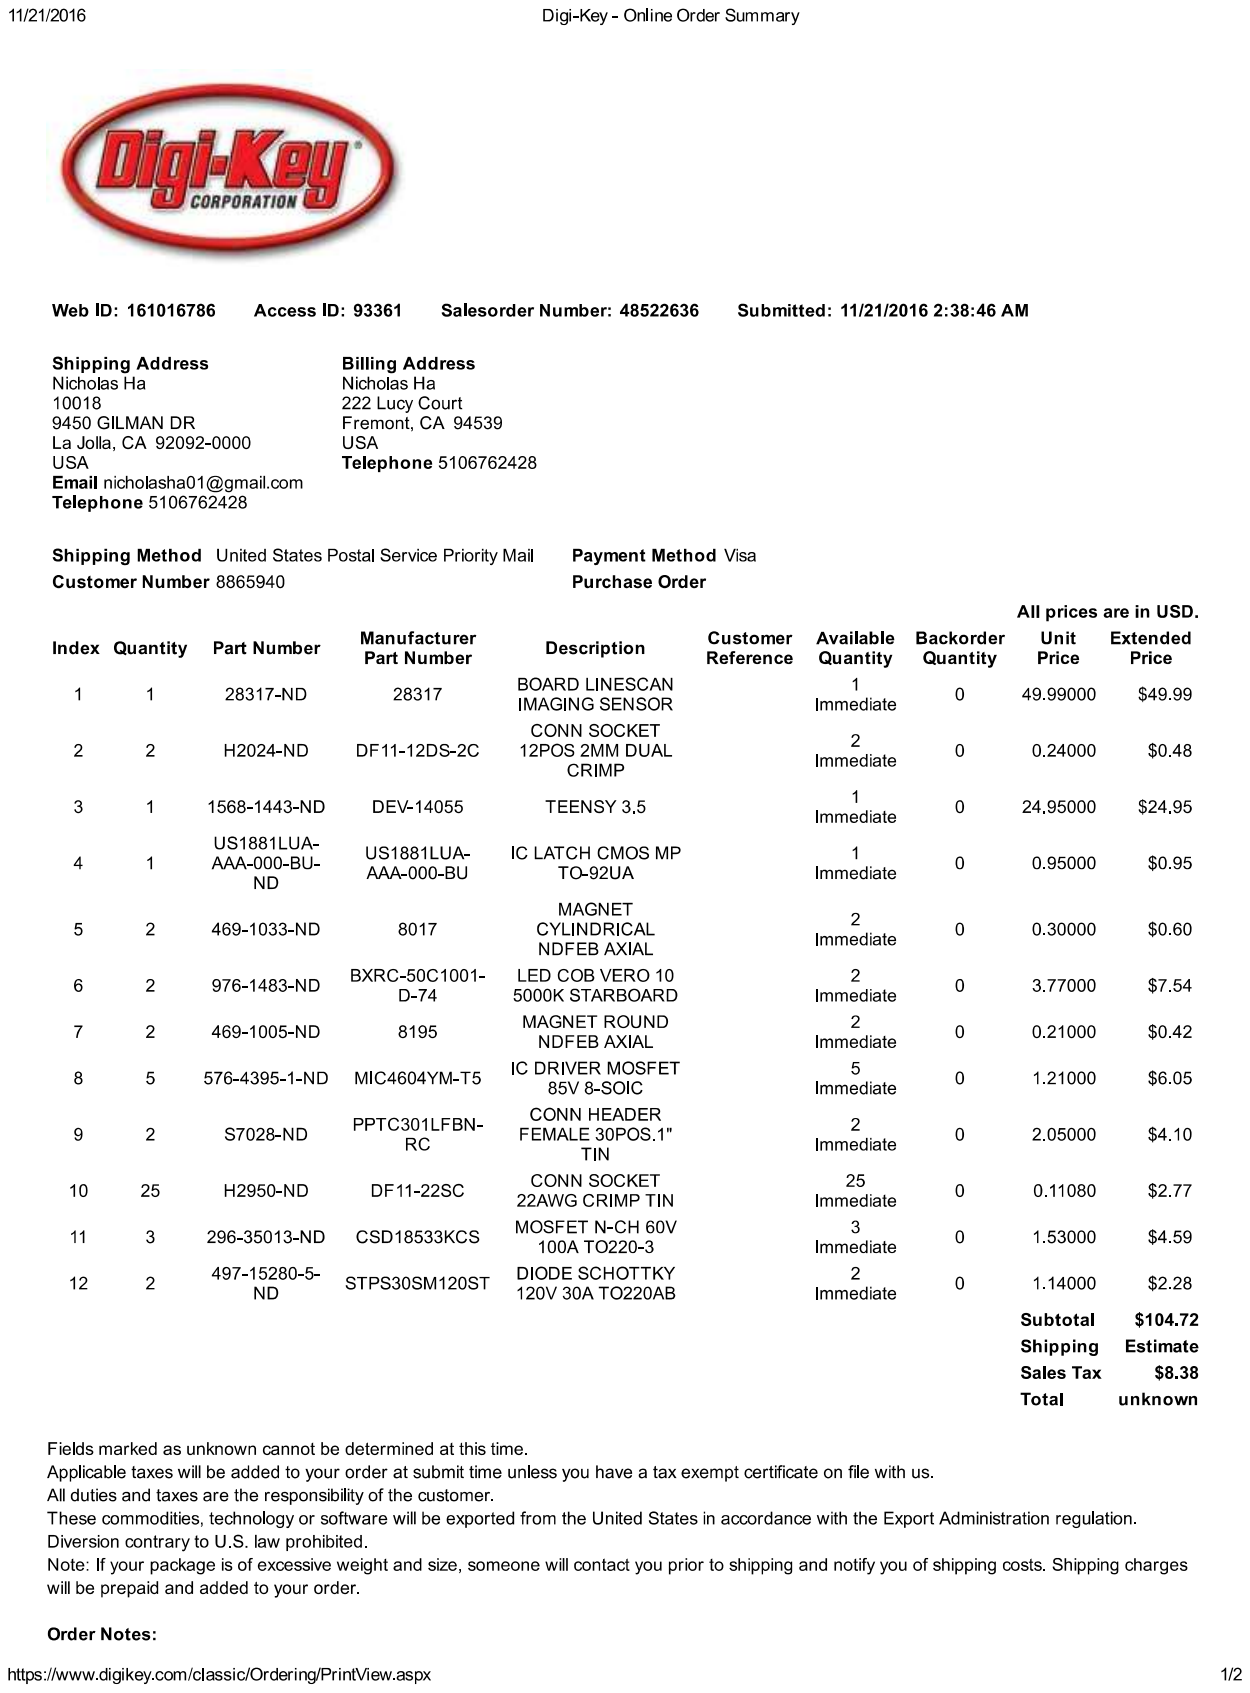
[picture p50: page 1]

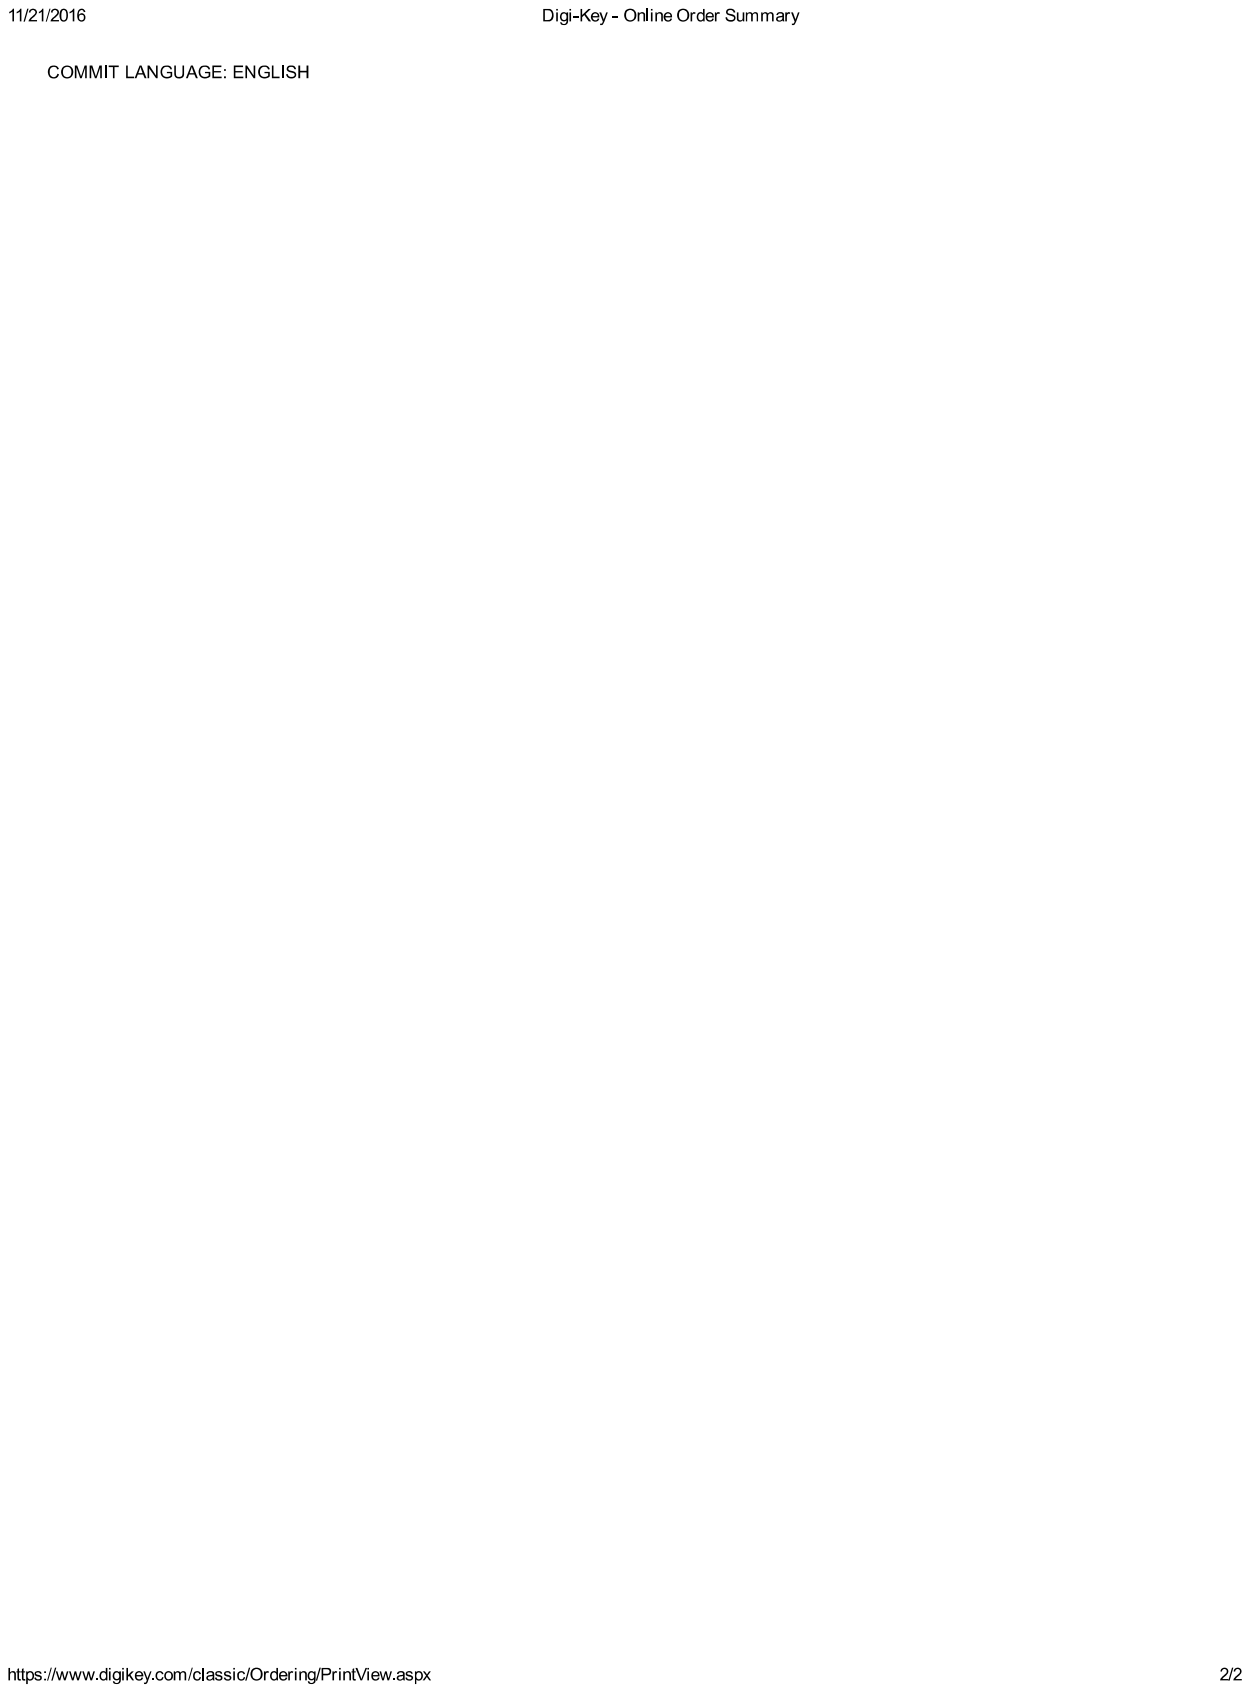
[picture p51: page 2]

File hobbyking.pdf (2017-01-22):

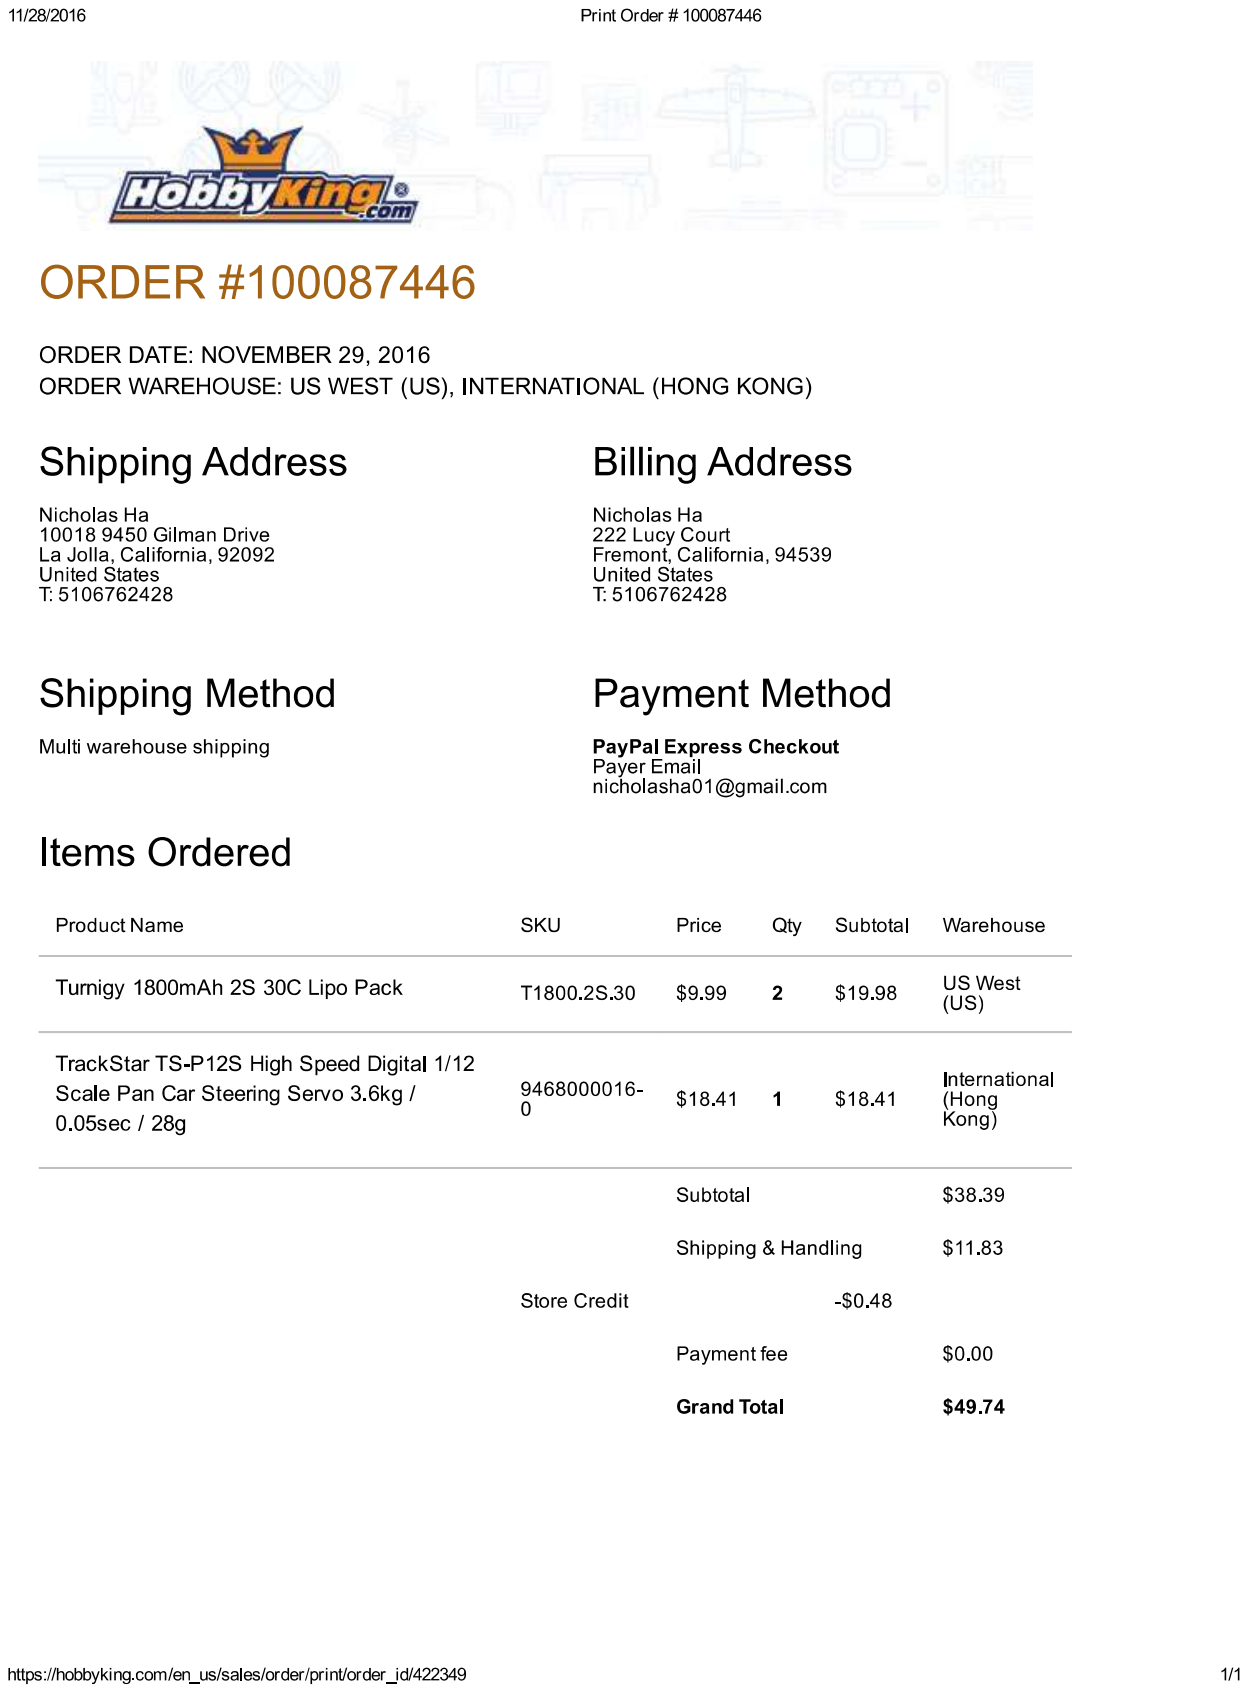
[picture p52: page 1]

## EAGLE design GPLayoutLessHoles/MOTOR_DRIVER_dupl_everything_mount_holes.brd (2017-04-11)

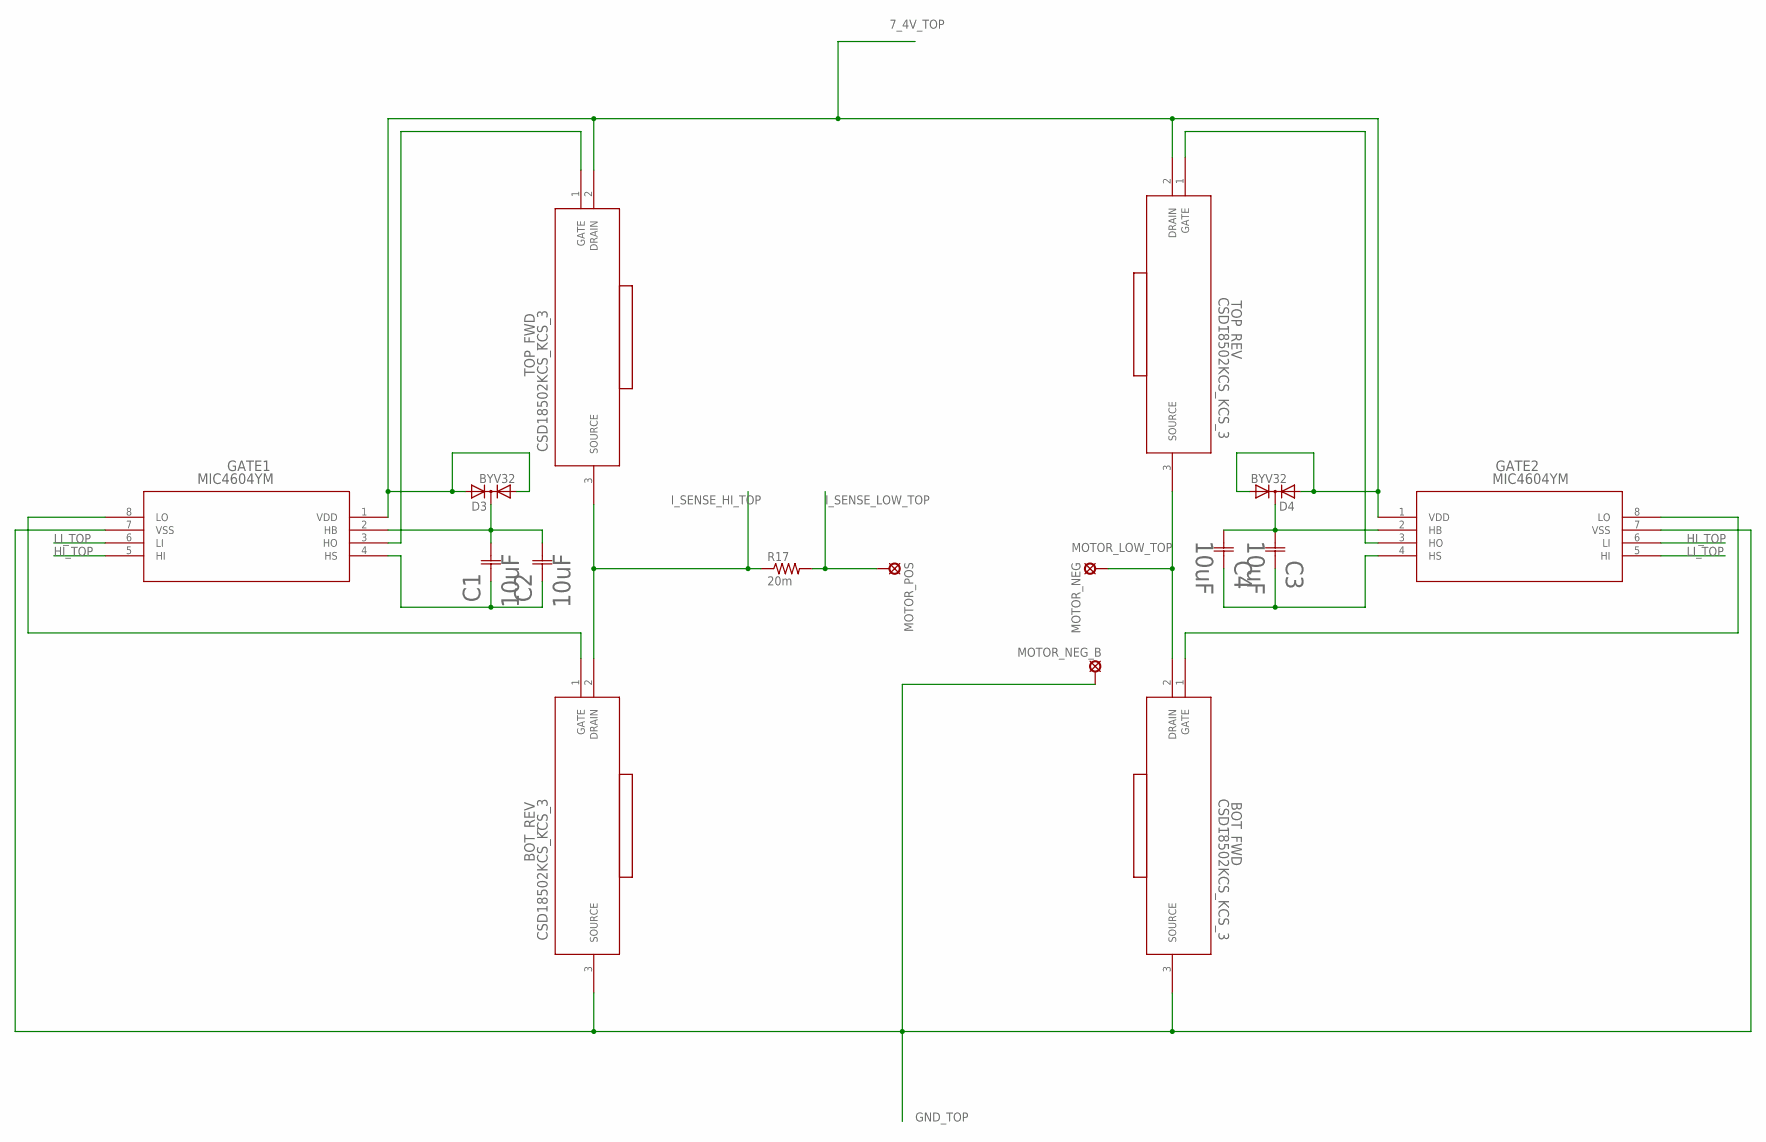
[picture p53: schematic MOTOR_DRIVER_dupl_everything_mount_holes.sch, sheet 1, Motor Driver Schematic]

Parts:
BOT_FWD: CSD18502KCS_KCS_3; KCS3
BOT_REV: CSD18502KCS_KCS_3; KCS3
C1, C2, C3, C4: 10uF; CAP_EEE_B
D3, D4: BYV32; TO220ABS
GATE1, GATE2: MIC4604YM; SOIC-8_M
MOTOR_NEG: SE14
MOTOR_NEG_B: SE14
MOTOR_POS: SE14
R17: 20m; R2512
TOP_FWD: CSD18502KCS_KCS_3; KCS3
TOP_REV: CSD18502KCS_KCS_3; KCS3
U$2, U$4, U$5, U$6: HEATSINK

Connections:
7_4V_TOP: D3.A1, D3.A2, D4.A1, D4.A2, GATE1.1 (VDD), GATE2.1 (VDD), TOP_FWD.2 (DRAIN), TOP_REV.2 (DRAIN); also elsewhere on the board
GND_TOP: BOT_FWD.3 (SOURCE), BOT_REV.3 (SOURCE), GATE1.7 (VSS), GATE2.7 (VSS), MOTOR_NEG_B.MP; also elsewhere on the board
HI_TOP: GATE1.5 (HI), GATE2.6 (LI); also elsewhere on the board
I_SENSE_HI_TOP: BOT_REV.2 (DRAIN), R17.1, TOP_FWD.3 (SOURCE); also elsewhere on the board
I_SENSE_LOW_TOP: MOTOR_POS.MP, R17.2; also elsewhere on the board
LI_TOP: GATE1.6 (LI), GATE2.5 (HI); also elsewhere on the board
MOTOR_LOW_TOP: BOT_FWD.2 (DRAIN), MOTOR_NEG.MP, TOP_REV.3 (SOURCE); also elsewhere on the board
unnamed: BOT_REV.1 (GATE), GATE1.8 (LO)
unnamed: GATE1.3 (HO), TOP_FWD.1 (GATE)
unnamed: C1.1, C2.1, GATE1.4 (HS)
unnamed: C1.2, C2.2, D3.C, GATE1.2 (HB)
unnamed: BOT_FWD.1 (GATE), GATE2.8 (LO)
unnamed: GATE2.3 (HO), TOP_REV.1 (GATE)
unnamed: C3.1, C4.1, GATE2.4 (HS)
unnamed: C3.2, C4.2, D4.C, GATE2.2 (HB)

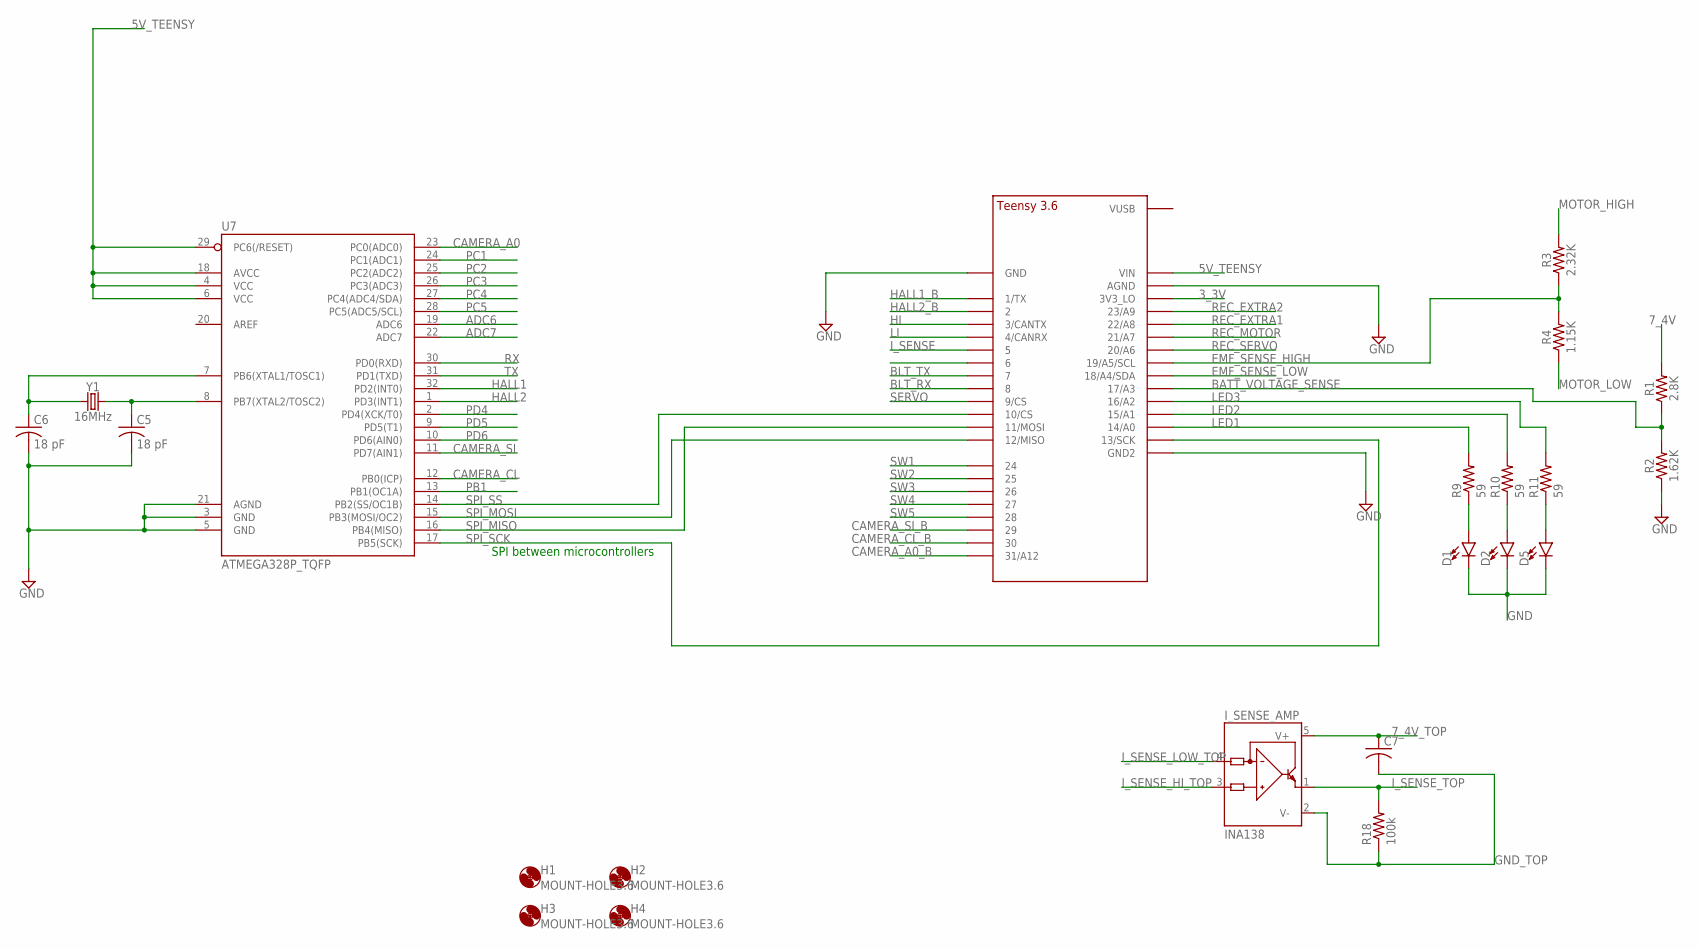
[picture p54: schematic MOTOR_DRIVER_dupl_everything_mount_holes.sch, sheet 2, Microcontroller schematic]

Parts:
C5, C6: 18 pF; C0603
C7: C-USC0603; C0603
D1, D2, D5: LED0603; LED-0603
H1, H2, H3, H4: MOUNT-HOLE3.6; 3,6
I_SENSE_AMP: INA138; SOT23-5
R1: 2.8K; 0805; MANUFACTURER_PART_NUMBER RC0805FR-072K8L; DIGIKEY_PART_NUMBER 311-2.80KCRCT-ND
R2: 1.62K; 0805; MANUFACTURER_PART_NUMBER RC0805FR-071K62L; DIGIKEY_PART_NUMBER 311-1.62KCRCT-ND
R3: 2.32K; 0805; MANUFACTURER_PART_NUMBER RC0805FR-072K32L; DIGIKEY_PART_NUMBER 311-2.32KCRCT-ND
R4: 1.15K; 0805; MANUFACTURER_PART_NUMBER RC0805FR-071K15L; DIGIKEY_PART_NUMBER 311-1.15KCRCT-ND
R9, R10, R11: 59; R0805
R18: 100k; R0603
U7: ATMEGA328P_TQFP; TQFP32-08; MANUFACTURER_PART_NUMBER ATMEGA328PB-AU; DIGIKEY_PART_NUMBER ATMEGA328PB-AU-ND
U$1: TEENSY_3.5/3.6_FEWER; TEENSY_3.5/3.6_BASIC_FEWER_PIN; MANUFACTURER_PART_NUMBER DEV-14055; DIGIKEY_PART_NUMBER 1568-1443-ND
Y1: 16MHz; HC49US; MANUFACTURER_PART_NUMBER 9C-16.000MBBK-T; DIGIKEY_PART_NUMBER 887-2425-1-ND

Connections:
3_3V: U$1.3V3_LO; also elsewhere on the board
5V_TEENSY: U7.4 (VCC), U7.6 (VCC), U7.18 (AVCC), U7.29 (PC6(/RESET)), U$1.VIN; also elsewhere on the board
7_4V: R1.2; also elsewhere on the board
7_4V_TOP: C7.1, I_SENSE_AMP.5 (V+); also elsewhere on the board
ADC6: U7.19 (ADC6); also elsewhere on the board
ADC7: U7.22 (ADC7); also elsewhere on the board
BATT_VOLTAGE_SENSE: R1.1, R2.2, U$1.17/A3
BLT_RX: U$1.8; also elsewhere on the board
BLT_TX: U$1.7; also elsewhere on the board
CAMERA_A0: U7.23 (PC0(ADC0)); also elsewhere on the board
CAMERA_A0_B: U$1.31/A12; also elsewhere on the board
CAMERA_CL: U7.12 (PB0(ICP)); also elsewhere on the board
CAMERA_CL_B: U$1.30; also elsewhere on the board
CAMERA_SI: U7.11 (PD7(AIN1)); also elsewhere on the board
CAMERA_SI_B: U$1.29; also elsewhere on the board
EMF_SENSE_HIGH: R3.1, R4.2, U$1.19/A5/SCL
EMF_SENSE_LOW: U$1.18/A4/SDA; also elsewhere on the board
GND: C5.2, C6.2, D1.C, D2.C, D5.C, R2.1, U7.3 (GND), U7.5 (GND), U7.21 (AGND), U$1.AGND, U$1.GND, U$1.GND2; also elsewhere on the board
GND_TOP: C7.2, I_SENSE_AMP.2 (V-), R18.1; also elsewhere on the board
HALL1: U7.32 (PD2(INT0)); also elsewhere on the board
HALL1_B: U$1.1/TX; also elsewhere on the board
HALL2: U7.1 (PD3(INT1)); also elsewhere on the board
HALL2_B: U$1.2; also elsewhere on the board
HI: U$1.3/CANTX; also elsewhere on the board
I_SENSE: U$1.5; also elsewhere on the board
I_SENSE_HI_TOP: I_SENSE_AMP.3 (IN+); also elsewhere on the board
I_SENSE_LOW_TOP: I_SENSE_AMP.4 (IN-); also elsewhere on the board
I_SENSE_TOP: I_SENSE_AMP.1 (OUT), R18.2; also elsewhere on the board
LED1: R9.2, U$1.14/A0
LED2: R10.2, U$1.15/A1
LED3: R11.2, U$1.16/A2
LI: U$1.4/CANRX; also elsewhere on the board
LI2: U$1.6
MOTOR_HIGH: R3.2; also elsewhere on the board
MOTOR_LOW: R4.1; also elsewhere on the board
unnamed: C6.1, U7.7 (PB6(XTAL1/TOSC1)), Y1.1
unnamed: C5.1, U7.8 (PB7(XTAL2/TOSC2)), Y1.2
unnamed: D1.A, R9.1
unnamed: D2.A, R10.1
unnamed: D5.A, R11.1
PB1: U7.13 (PB1(OC1A)); also elsewhere on the board
PC1: U7.24 (PC1(ADC1)); also elsewhere on the board
PC2: U7.25 (PC2(ADC2)); also elsewhere on the board
PC3: U7.26 (PC3(ADC3)); also elsewhere on the board
PC4: U7.27 (PC4(ADC4/SDA)); also elsewhere on the board
PC5: U7.28 (PC5(ADC5/SCL)); also elsewhere on the board
PD4: U7.2 (PD4(XCK/T0)); also elsewhere on the board
PD5: U7.9 (PD5(T1)); also elsewhere on the board
PD6: U7.10 (PD6(AIN0))
REC_EXTRA1: U$1.22/A8; also elsewhere on the board
REC_EXTRA2: U$1.23/A9; also elsewhere on the board
REC_MOTOR: U$1.21/A7; also elsewhere on the board
REC_SERVO: U$1.20/A6; also elsewhere on the board
RX: U7.30 (PD0(RXD)); also elsewhere on the board
SERVO: U$1.9/CS; also elsewhere on the board
SPI_MISO: U7.16 (PB4(MISO)), U$1.11/MOSI
SPI_MOSI: U7.15 (PB3(MOSI/OC2)), U$1.12/MISO
SPI_SCK: U7.17 (PB5(SCK)), U$1.13/SCK
SPI_SS: U7.14 (PB2(SS/OC1B)), U$1.10/CS
SW1: U$1.24; also elsewhere on the board
SW2: U$1.25; also elsewhere on the board
SW3: U$1.26; also elsewhere on the board
SW4: U$1.27; also elsewhere on the board
SW5: U$1.28
TX: U7.31 (PD1(TXD)); also elsewhere on the board

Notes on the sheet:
SPI between microcontrollers

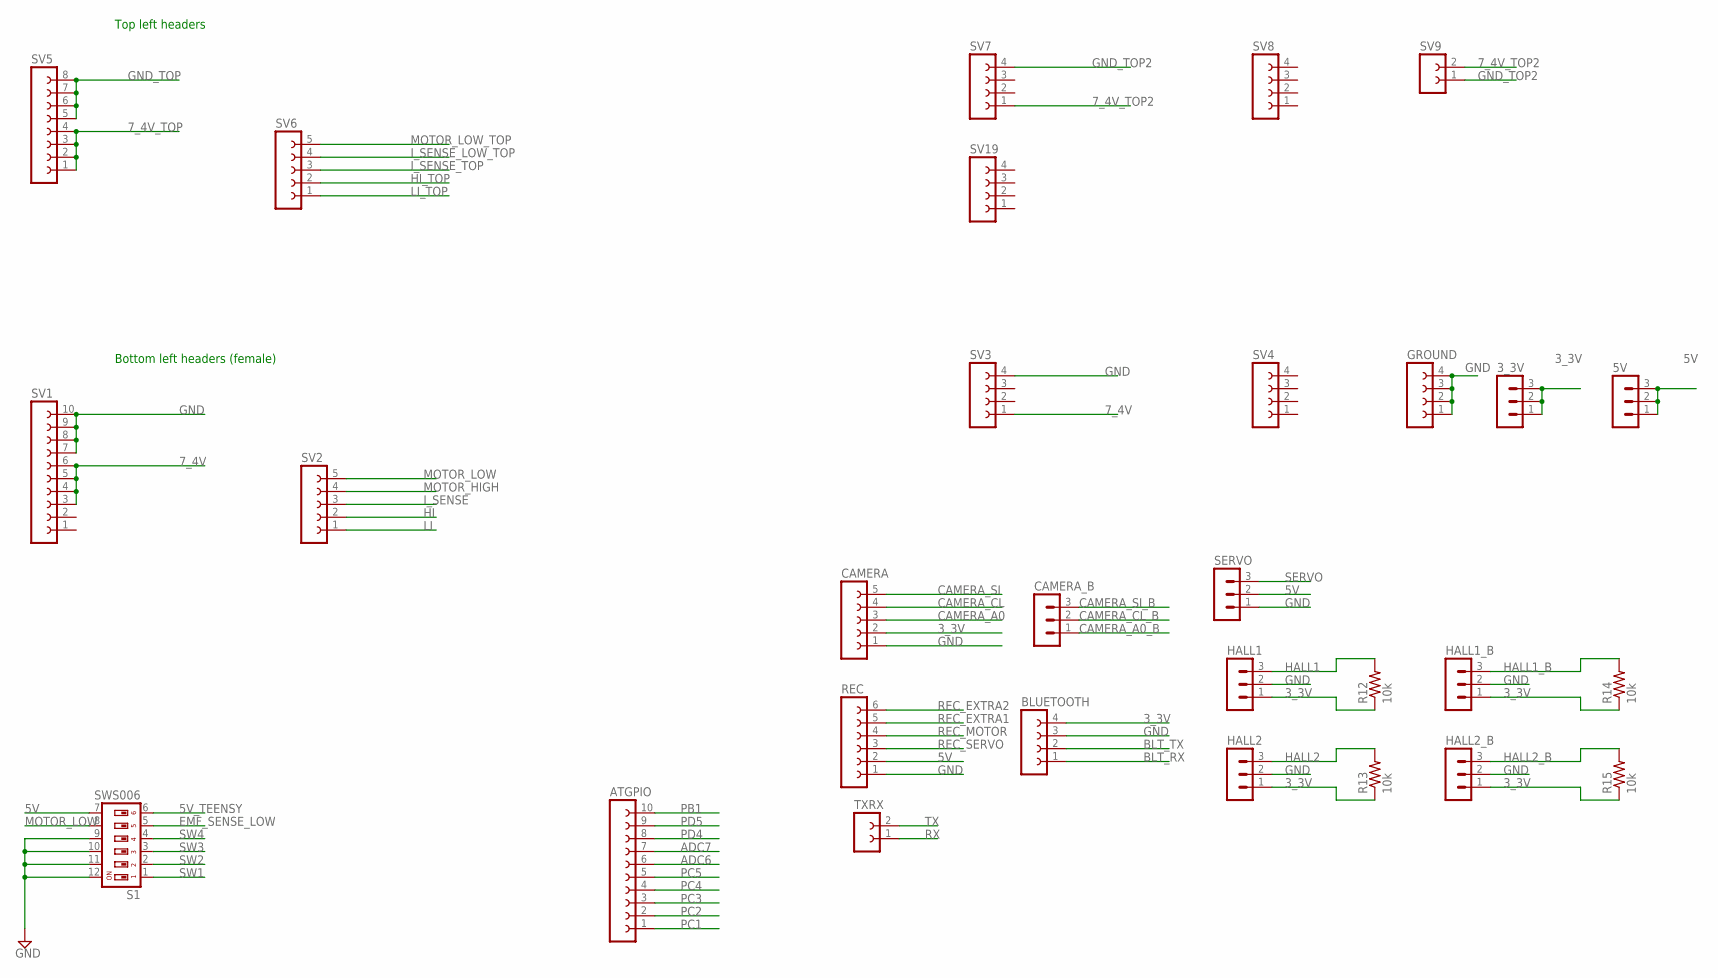
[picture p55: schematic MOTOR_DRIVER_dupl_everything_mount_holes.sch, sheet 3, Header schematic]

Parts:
3_3V, 5V: MA03-1
ATGPIO: FE10-1; FE10
BLUETOOTH: FE04-1; MANUFACTURER_PART_NUMBER HC-06
CAMERA: FE05-1; MANUFACTURER_PART_NUMBER 28317; DIGIKEY_PART_NUMBER 28317-ND
CAMERA_B: MA03-1; MANUFACTURER_PART_NUMBER 28317; DIGIKEY_PART_NUMBER 28317-ND
GROUND: FE04-1
HALL1, HALL1_B, HALL2, HALL2_B: MA03-1; MANUFACTURER_PART_NUMBER US1881LUA-AAA-000-BU; DIGIKEY_PART_NUMBER US1881LUA-AAA-000-BU-ND
R12, R13, R14, R15: 10k; R0603
REC: FE06-1; FE06
S1: SWS006; SMS-006; MANUFACTURER_PART_NUMBER 219-6MST; DIGIKEY_PART_NUMBER CT2196MST-ND
SERVO: MA03-1; MANUFACTURER_PART_NUMBER TS-P12S
SV1: FE10-1; FE10
SV2, SV6: FE05-1
SV3, SV4, SV7, SV8, SV19: FE04-1
SV5: FE08-1; FE08
SV9: FE02-1
TXRX: FE02-1

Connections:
3_3V: 3_3V.1, 3_3V.2, 3_3V.3, BLUETOOTH.4, CAMERA.2, HALL1.1, HALL1_B.1, HALL2.1, HALL2_B.1, R12.1, R13.1, R14.1, R15.1; also elsewhere on the board
5V: 5V.1, 5V.2, 5V.3, REC.2, S1.7, SERVO.2; also elsewhere on the board
5V_TEENSY: S1.6; also elsewhere on the board
7_4V: SV1.3, SV1.4, SV1.5, SV1.6, SV3.1; also elsewhere on the board
7_4V_TOP: SV5.1, SV5.2, SV5.3, SV5.4; also elsewhere on the board
7_4V_TOP2: SV7.1, SV9.2; also elsewhere on the board
ADC6: ATGPIO.6; also elsewhere on the board
ADC7: ATGPIO.7; also elsewhere on the board
BLT_RX: BLUETOOTH.1; also elsewhere on the board
BLT_TX: BLUETOOTH.2; also elsewhere on the board
CAMERA_A0: CAMERA.3; also elsewhere on the board
CAMERA_A0_B: CAMERA_B.1; also elsewhere on the board
CAMERA_CL: CAMERA.4; also elsewhere on the board
CAMERA_CL_B: CAMERA_B.2; also elsewhere on the board
CAMERA_SI: CAMERA.5; also elsewhere on the board
CAMERA_SI_B: CAMERA_B.3; also elsewhere on the board
EMF_SENSE_LOW: S1.5; also elsewhere on the board
GND: BLUETOOTH.3, CAMERA.1, GROUND.1, GROUND.2, GROUND.3, GROUND.4, HALL1.2, HALL1_B.2, HALL2.2, HALL2_B.2, REC.1, S1.9, S1.10, S1.11, S1.12, SERVO.1, SV1.7, SV1.8, SV1.9, SV1.10, SV3.4; also elsewhere on the board
GND_TOP: SV5.5, SV5.6, SV5.7, SV5.8; also elsewhere on the board
GND_TOP2: SV7.4, SV9.1; also elsewhere on the board
HALL1: HALL1.3, R12.2; also elsewhere on the board
HALL1_B: HALL1_B.3, R14.2; also elsewhere on the board
HALL2: HALL2.3, R13.2; also elsewhere on the board
HALL2_B: HALL2_B.3, R15.2; also elsewhere on the board
HI: SV2.2; also elsewhere on the board
HI_TOP: SV6.2; also elsewhere on the board
I_SENSE: SV2.3; also elsewhere on the board
I_SENSE_LOW_TOP: SV6.4; also elsewhere on the board
I_SENSE_TOP: SV6.3; also elsewhere on the board
LI: SV2.1; also elsewhere on the board
LI_TOP: SV6.1; also elsewhere on the board
MOTOR_HIGH: SV2.4; also elsewhere on the board
MOTOR_LOW: S1.8, SV2.5; also elsewhere on the board
MOTOR_LOW_TOP: SV6.5; also elsewhere on the board
PB1: ATGPIO.10; also elsewhere on the board
PC1: ATGPIO.1; also elsewhere on the board
PC2: ATGPIO.2; also elsewhere on the board
PC3: ATGPIO.3; also elsewhere on the board
PC4: ATGPIO.4; also elsewhere on the board
PC5: ATGPIO.5; also elsewhere on the board
PD4: ATGPIO.8; also elsewhere on the board
PD5: ATGPIO.9; also elsewhere on the board
REC_EXTRA1: REC.5; also elsewhere on the board
REC_EXTRA2: REC.6; also elsewhere on the board
REC_MOTOR: REC.4; also elsewhere on the board
REC_SERVO: REC.3; also elsewhere on the board
RX: TXRX.1; also elsewhere on the board
SERVO: SERVO.3; also elsewhere on the board
SW1: S1.1; also elsewhere on the board
SW2: S1.2; also elsewhere on the board
SW3: S1.3; also elsewhere on the board
SW4: S1.4; also elsewhere on the board
TX: TXRX.2; also elsewhere on the board

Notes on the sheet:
Bottom left headers (female)
Top left headers

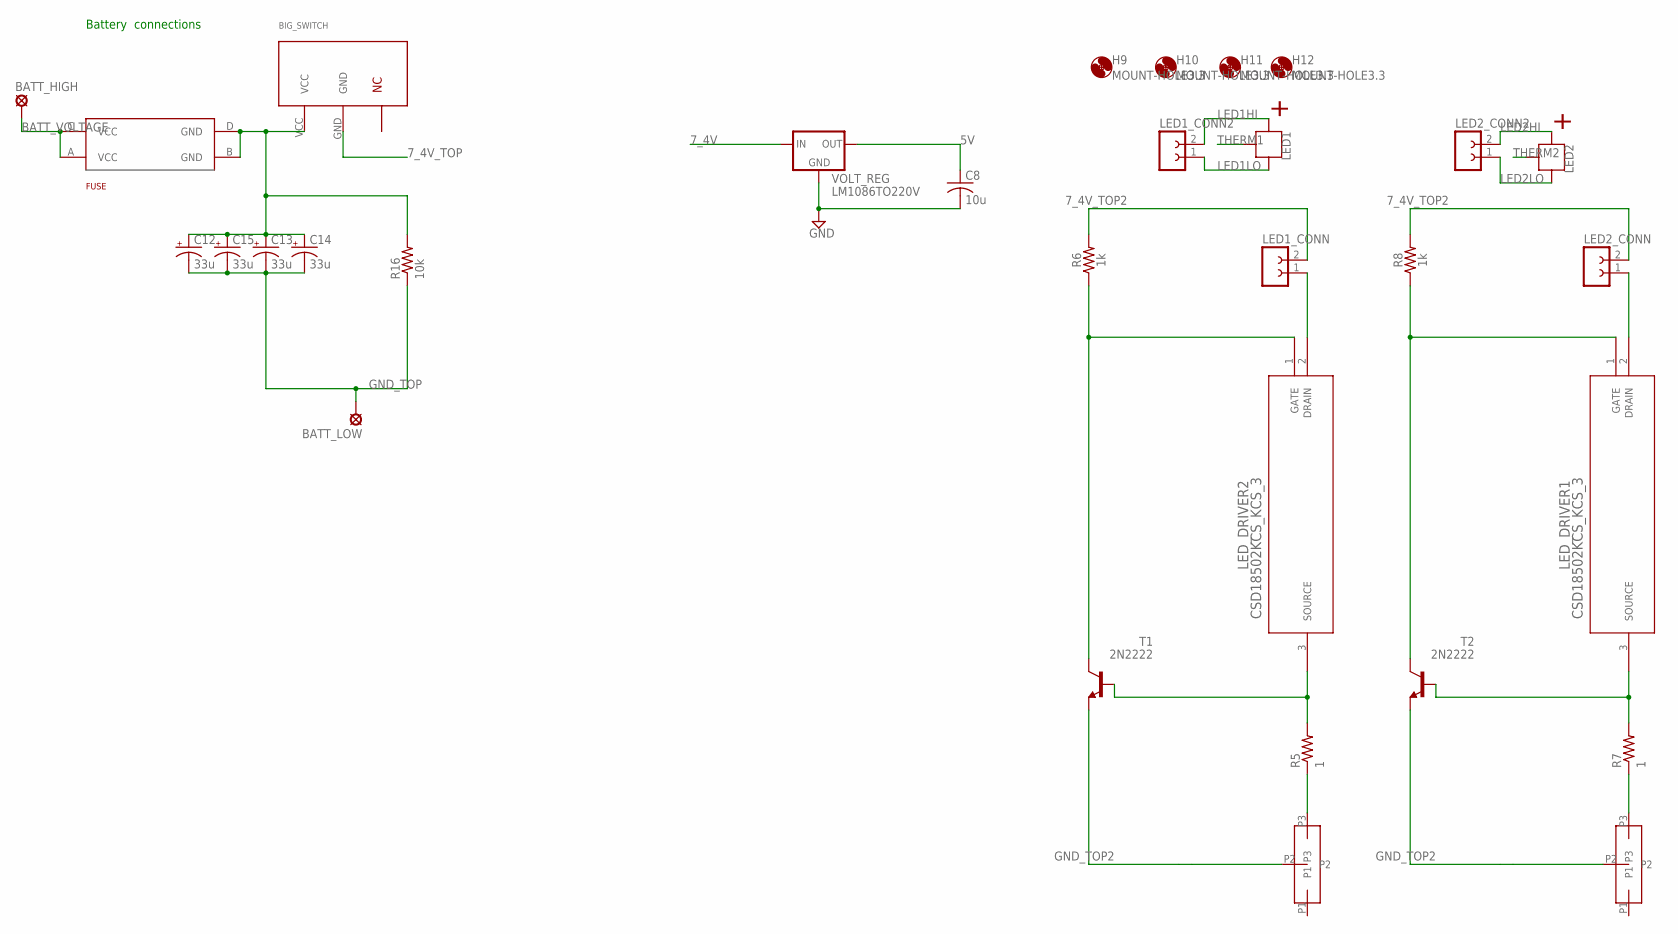
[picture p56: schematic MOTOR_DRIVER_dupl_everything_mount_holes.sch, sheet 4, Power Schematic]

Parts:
BATT_HIGH: SE14
BATT_LOW: SE14
BIG_SWITCH: BIGSWITCH; MANUFACTURER_PART_NUMBER GRB238B801BR1; DIGIKEY_PART_NUMBER CW106-ND
C8: 10u; C0805
C12, C13, C14, C15: 33u; 153CLV-1010
FUSE: FUSEHOLDER3588; MANUFACTURER_PART_NUMBER 0891010.NXS; DIGIKEY_PART_NUMBER F4989-ND
H9, H10, H11, H12: MOUNT-HOLE3.3; 3,3
LED1, LED2: CREE_XP; XP
LED1_CONN, LED1_CONN2, LED2_CONN, LED2_CONN2: FE02-1
LED_DRIVER1, LED_DRIVER2: CSD18502KCS_KCS_3; KCS3
R5, R7: 1; R2512
R6, R8: 1k; AXIAL-0.3
R16: 10k; R0603
T1, T2: 2N2222; TO18
U$3, U$7: POT
VOLT_REG: LM1086TO220V; TO220S; MANUFACTURER_PART_NUMBER LM1086IT-5.0/NOPB; DIGIKEY_PART_NUMBER LM1086IT-5.0/NOPB-ND

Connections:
5V: C8.1, VOLT_REG.2 (OUT); also elsewhere on the board
7_4V: VOLT_REG.3 (IN); also elsewhere on the board
7_4V_TOP: BIG_SWITCH.GND; also elsewhere on the board
7_4V_TOP2: LED1_CONN.2, LED2_CONN.2, R6.P$2 (2), R8.P$2 (2); also elsewhere on the board
BATT_VOLTAGE: BATT_HIGH.MP, FUSE.A (VCC), FUSE.C (VCC)
GND: C8.2, VOLT_REG.1 (GND); also elsewhere on the board
GND_TOP: BATT_LOW.MP, C12.-, C13.-, C14.-, C15.-, R16.1; also elsewhere on the board
GND_TOP2: T1.1 (E), T2.1 (E), U$3.P2, U$7.P2; also elsewhere on the board
LED1HI: LED1.POSITIVE, LED1.POSITIVE1 (POSITIVE), LED1_CONN2.2
LED1LO: LED1.NEGATIVE, LED1.NEGATIVE1 (NEGATIVE), LED1_CONN2.1
LED2HI: LED2.POSITIVE, LED2.POSITIVE1 (POSITIVE), LED2_CONN2.2
LED2LO: LED2.NEGATIVE, LED2.NEGATIVE1 (NEGATIVE), LED2_CONN2.1
unnamed: R5.1, U$7.P3
unnamed: LED_DRIVER2.3 (SOURCE), R5.2, T1.2 (B)
unnamed: R7.1, U$3.P3
unnamed: LED_DRIVER2.1 (GATE), R6.P$1 (1), T1.3 (C)
unnamed: LED1_CONN.1, LED_DRIVER2.2 (DRAIN)
unnamed: LED_DRIVER1.3 (SOURCE), R7.2, T2.2 (B)
unnamed: LED_DRIVER1.1 (GATE), R8.P$1 (1), T2.3 (C)
unnamed: LED2_CONN.1, LED_DRIVER1.2 (DRAIN)
unnamed: BIG_SWITCH.VCC, C12.+, C13.+, C14.+, C15.+, FUSE.B (GND), FUSE.D (GND), R16.2
THERM1: LED1.THERMAL
THERM2: LED2.THERMAL

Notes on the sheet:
Battery connections

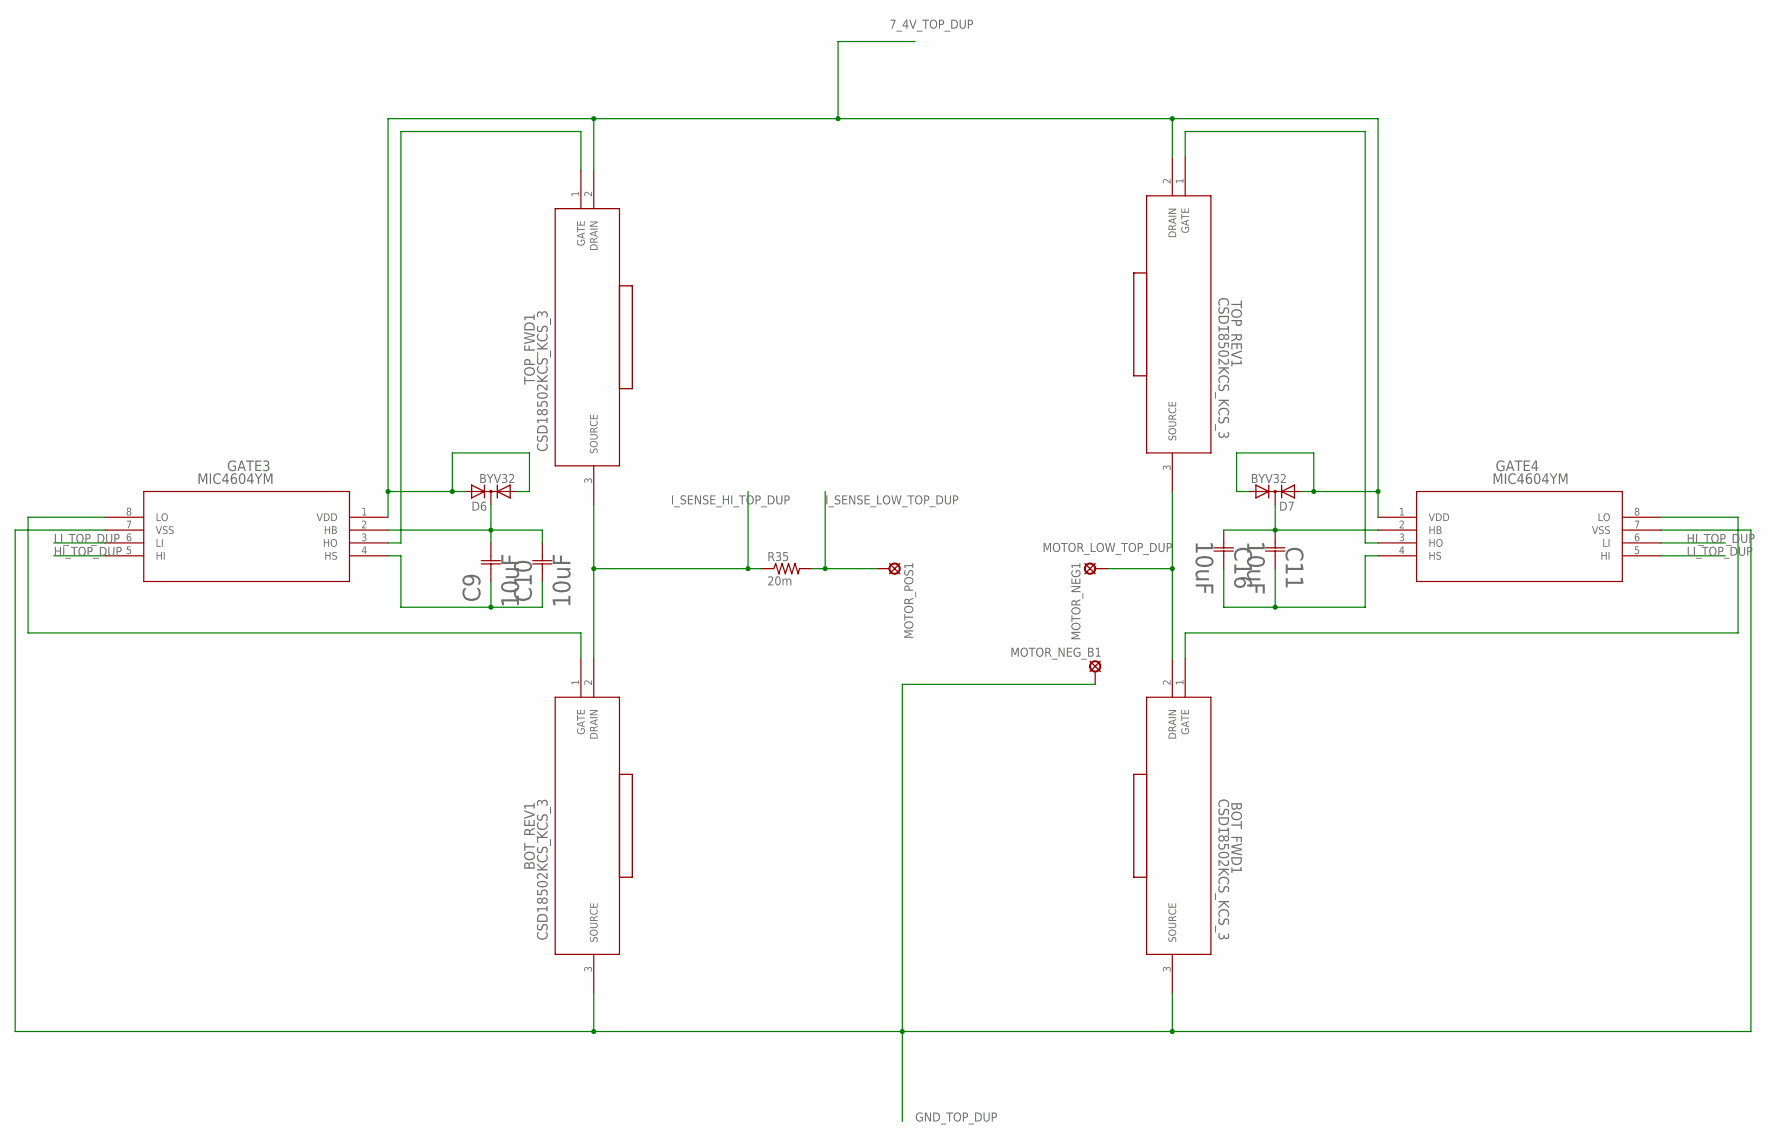
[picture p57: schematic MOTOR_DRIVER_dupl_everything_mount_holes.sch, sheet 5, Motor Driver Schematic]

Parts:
BOT_FWD1: CSD18502KCS_KCS_3; KCS3
BOT_REV1: CSD18502KCS_KCS_3; KCS3
C9, C10, C11, C16: 10uF; CAP_EEE_B
D6, D7: BYV32; TO220ABS
GATE3, GATE4: MIC4604YM; SOIC-8_M
MOTOR_NEG1: SE14
MOTOR_NEG_B1: SE14
MOTOR_POS1: SE14
R35: 20m; R2512
TOP_FWD1: CSD18502KCS_KCS_3; KCS3
TOP_REV1: CSD18502KCS_KCS_3; KCS3
U$10, U$11, U$12, U$13: HEATSINK

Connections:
7_4V_TOP_DUP: D6.A1, D6.A2, D7.A1, D7.A2, GATE3.1 (VDD), GATE4.1 (VDD), TOP_FWD1.2 (DRAIN), TOP_REV1.2 (DRAIN); also elsewhere on the board
GND_TOP_DUP: BOT_FWD1.3 (SOURCE), BOT_REV1.3 (SOURCE), GATE3.7 (VSS), GATE4.7 (VSS), MOTOR_NEG_B1.MP; also elsewhere on the board
HI_TOP_DUP: GATE3.5 (HI), GATE4.6 (LI); also elsewhere on the board
I_SENSE_HI_TOP_DUP: BOT_REV1.2 (DRAIN), R35.1, TOP_FWD1.3 (SOURCE); also elsewhere on the board
I_SENSE_LOW_TOP_DUP: MOTOR_POS1.MP, R35.2; also elsewhere on the board
LI_TOP_DUP: GATE3.6 (LI), GATE4.5 (HI); also elsewhere on the board
MOTOR_LOW_TOP_DUP: BOT_FWD1.2 (DRAIN), MOTOR_NEG1.MP, TOP_REV1.3 (SOURCE); also elsewhere on the board
unnamed: BOT_REV1.1 (GATE), GATE3.8 (LO)
unnamed: GATE3.3 (HO), TOP_FWD1.1 (GATE)
unnamed: C9.1, C10.1, GATE3.4 (HS)
unnamed: C9.2, C10.2, D6.C, GATE3.2 (HB)
unnamed: BOT_FWD1.1 (GATE), GATE4.8 (LO)
unnamed: GATE4.3 (HO), TOP_REV1.1 (GATE)
unnamed: C11.1, C16.1, GATE4.4 (HS)
unnamed: C11.2, C16.2, D7.C, GATE4.2 (HB)

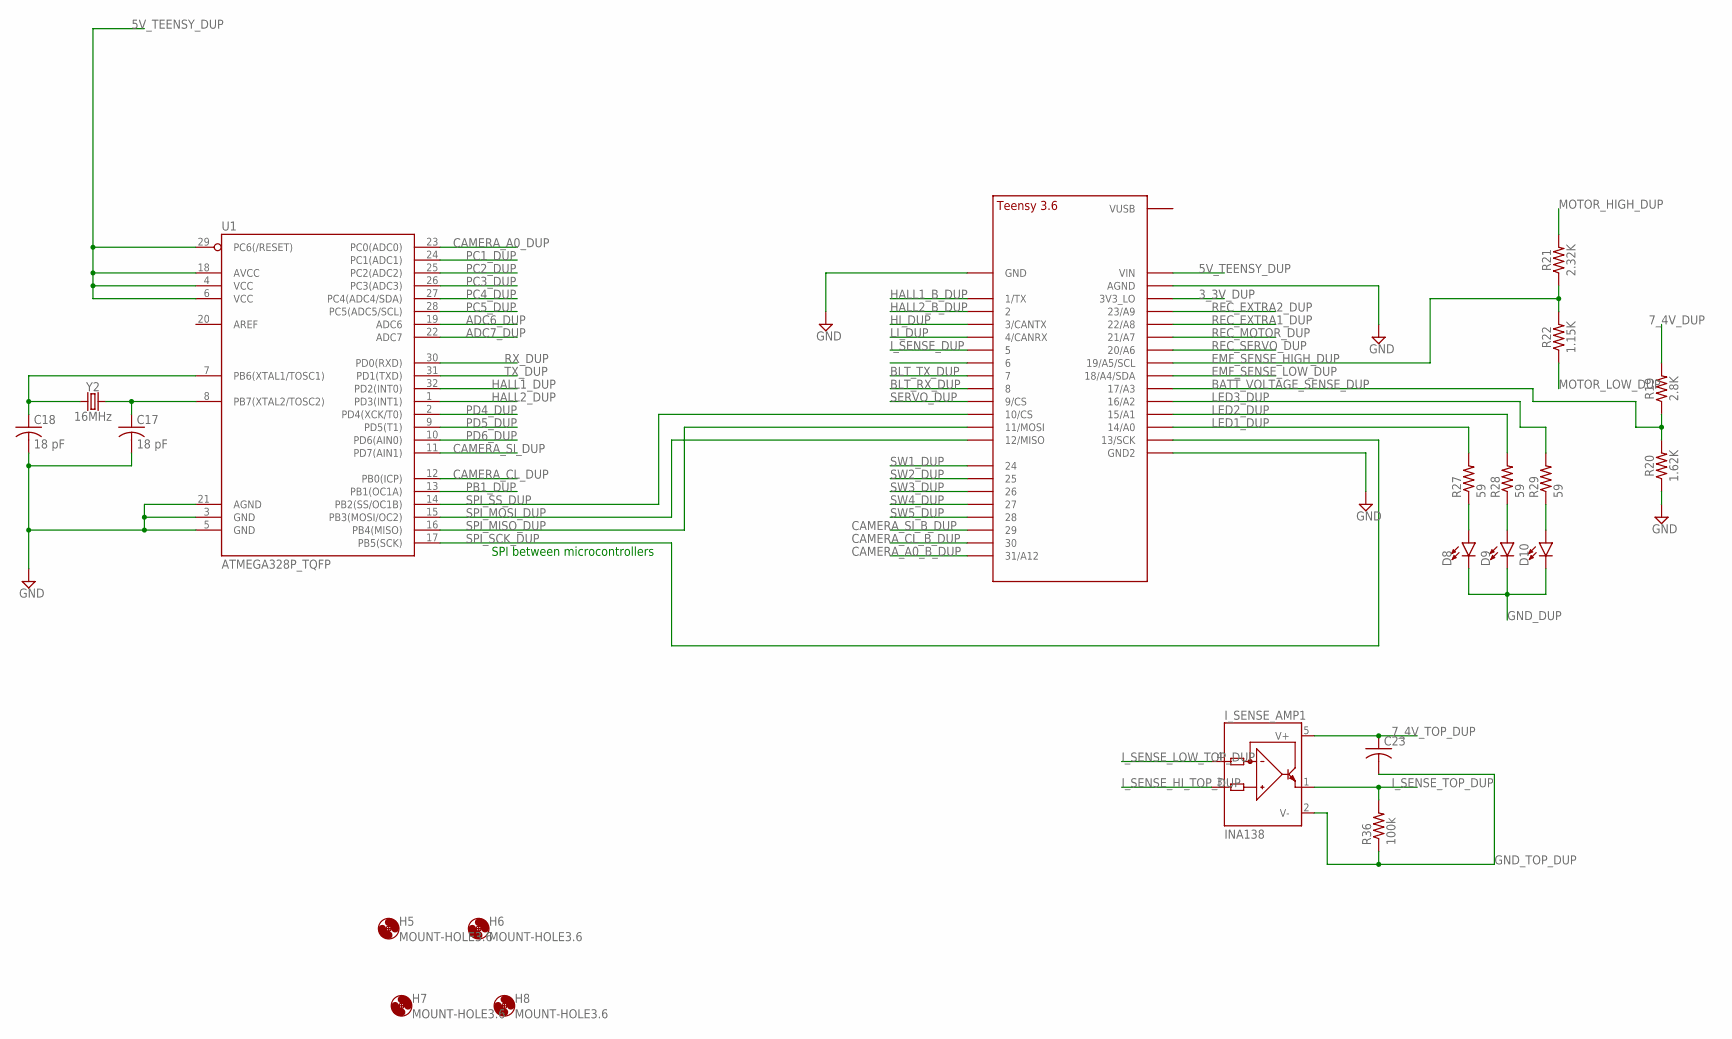
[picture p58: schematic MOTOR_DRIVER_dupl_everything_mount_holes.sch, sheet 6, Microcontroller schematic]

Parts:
C17, C18: 18 pF; C0603
C23: C-USC0603; C0603
D8, D9, D10: LED0603; LED-0603
H5, H6, H7, H8: MOUNT-HOLE3.6; 3,6
I_SENSE_AMP1: INA138; SOT23-5
R19: 2.8K; 0805; MANUFACTURER_PART_NUMBER RC0805FR-072K8L; DIGIKEY_PART_NUMBER 311-2.80KCRCT-ND
R20: 1.62K; 0805; MANUFACTURER_PART_NUMBER RC0805FR-071K62L; DIGIKEY_PART_NUMBER 311-1.62KCRCT-ND
R21: 2.32K; 0805; MANUFACTURER_PART_NUMBER RC0805FR-072K32L; DIGIKEY_PART_NUMBER 311-2.32KCRCT-ND
R22: 1.15K; 0805; MANUFACTURER_PART_NUMBER RC0805FR-071K15L; DIGIKEY_PART_NUMBER 311-1.15KCRCT-ND
R27, R28, R29: 59; R0805
R36: 100k; R0603
U1: ATMEGA328P_TQFP; TQFP32-08; MANUFACTURER_PART_NUMBER ATMEGA328PB-AU; DIGIKEY_PART_NUMBER ATMEGA328PB-AU-ND
U$9: TEENSY_3.5/3.6_FEWER; TEENSY_3.5/3.6_BASIC_FEWER_PIN; MANUFACTURER_PART_NUMBER DEV-14055; DIGIKEY_PART_NUMBER 1568-1443-ND
Y2: 16MHz; HC49US; MANUFACTURER_PART_NUMBER 9C-16.000MBBK-T; DIGIKEY_PART_NUMBER 887-2425-1-ND

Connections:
3_3V_DUP: U$9.3V3_LO; also elsewhere on the board
5V_TEENSY_DUP: U1.4 (VCC), U1.6 (VCC), U1.18 (AVCC), U1.29 (PC6(/RESET)), U$9.VIN; also elsewhere on the board
7_4V_DUP: R19.2; also elsewhere on the board
7_4V_TOP_DUP: C23.1, I_SENSE_AMP1.5 (V+); also elsewhere on the board
ADC6_DUP: U1.19 (ADC6); also elsewhere on the board
ADC7_DUP: U1.22 (ADC7); also elsewhere on the board
BATT_VOLTAGE_SENSE_DUP: R19.1, R20.2, U$9.17/A3
BLT_RX_DUP: U$9.8; also elsewhere on the board
BLT_TX_DUP: U$9.7; also elsewhere on the board
CAMERA_A0_B_DUP: U$9.31/A12; also elsewhere on the board
CAMERA_A0_DUP: U1.23 (PC0(ADC0)); also elsewhere on the board
CAMERA_CL_B_DUP: U$9.30; also elsewhere on the board
CAMERA_CL_DUP: U1.12 (PB0(ICP)); also elsewhere on the board
CAMERA_SI_B_DUP: U$9.29; also elsewhere on the board
CAMERA_SI_DUP: U1.11 (PD7(AIN1)); also elsewhere on the board
EMF_SENSE_HIGH_DUP: R21.1, R22.2, U$9.19/A5/SCL
EMF_SENSE_LOW_DUP: U$9.18/A4/SDA; also elsewhere on the board
GND_DUP: C17.2, C18.2, D8.C, D9.C, D10.C, R20.1, U1.3 (GND), U1.5 (GND), U1.21 (AGND), U$9.AGND, U$9.GND, U$9.GND2; also elsewhere on the board
GND_TOP_DUP: C23.2, I_SENSE_AMP1.2 (V-), R36.1; also elsewhere on the board
HALL1_B_DUP: U$9.1/TX; also elsewhere on the board
HALL1_DUP: U1.32 (PD2(INT0)); also elsewhere on the board
HALL2_B_DUP: U$9.2; also elsewhere on the board
HALL2_DUP: U1.1 (PD3(INT1)); also elsewhere on the board
HI_DUP: U$9.3/CANTX; also elsewhere on the board
I_SENSE_DUP: U$9.5; also elsewhere on the board
I_SENSE_HI_TOP_DUP: I_SENSE_AMP1.3 (IN+); also elsewhere on the board
I_SENSE_LOW_TOP_DUP: I_SENSE_AMP1.4 (IN-); also elsewhere on the board
I_SENSE_TOP_DUP: I_SENSE_AMP1.1 (OUT), R36.2; also elsewhere on the board
LED1_DUP: R27.2, U$9.14/A0
LED2_DUP: R28.2, U$9.15/A1
LED3_DUP: R29.2, U$9.16/A2
LI2_DUP: U$9.6
LI_DUP: U$9.4/CANRX; also elsewhere on the board
MOTOR_HIGH_DUP: R21.2; also elsewhere on the board
MOTOR_LOW_DUP: R22.1; also elsewhere on the board
unnamed: C18.1, U1.7 (PB6(XTAL1/TOSC1)), Y2.1
unnamed: C17.1, U1.8 (PB7(XTAL2/TOSC2)), Y2.2
unnamed: D8.A, R27.1
unnamed: D9.A, R28.1
unnamed: D10.A, R29.1
PB1_DUP: U1.13 (PB1(OC1A)); also elsewhere on the board
PC1_DUP: U1.24 (PC1(ADC1)); also elsewhere on the board
PC2_DUP: U1.25 (PC2(ADC2)); also elsewhere on the board
PC3_DUP: U1.26 (PC3(ADC3)); also elsewhere on the board
PC4_DUP: U1.27 (PC4(ADC4/SDA)); also elsewhere on the board
PC5_DUP: U1.28 (PC5(ADC5/SCL)); also elsewhere on the board
PD4_DUP: U1.2 (PD4(XCK/T0)); also elsewhere on the board
PD5_DUP: U1.9 (PD5(T1)); also elsewhere on the board
PD6_DUP: U1.10 (PD6(AIN0))
REC_EXTRA1_DUP: U$9.22/A8; also elsewhere on the board
REC_EXTRA2_DUP: U$9.23/A9; also elsewhere on the board
REC_MOTOR_DUP: U$9.21/A7; also elsewhere on the board
REC_SERVO_DUP: U$9.20/A6; also elsewhere on the board
RX_DUP: U1.30 (PD0(RXD)); also elsewhere on the board
SERVO_DUP: U$9.9/CS; also elsewhere on the board
SPI_MISO_DUP: U1.16 (PB4(MISO)), U$9.11/MOSI
SPI_MOSI_DUP: U1.15 (PB3(MOSI/OC2)), U$9.12/MISO
SPI_SCK_DUP: U1.17 (PB5(SCK)), U$9.13/SCK
SPI_SS_DUP: U1.14 (PB2(SS/OC1B)), U$9.10/CS
SW1_DUP: U$9.24; also elsewhere on the board
SW2_DUP: U$9.25; also elsewhere on the board
SW3_DUP: U$9.26; also elsewhere on the board
SW4_DUP: U$9.27; also elsewhere on the board
SW5_DUP: U$9.28
TX_DUP: U1.31 (PD1(TXD)); also elsewhere on the board

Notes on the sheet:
SPI between microcontrollers

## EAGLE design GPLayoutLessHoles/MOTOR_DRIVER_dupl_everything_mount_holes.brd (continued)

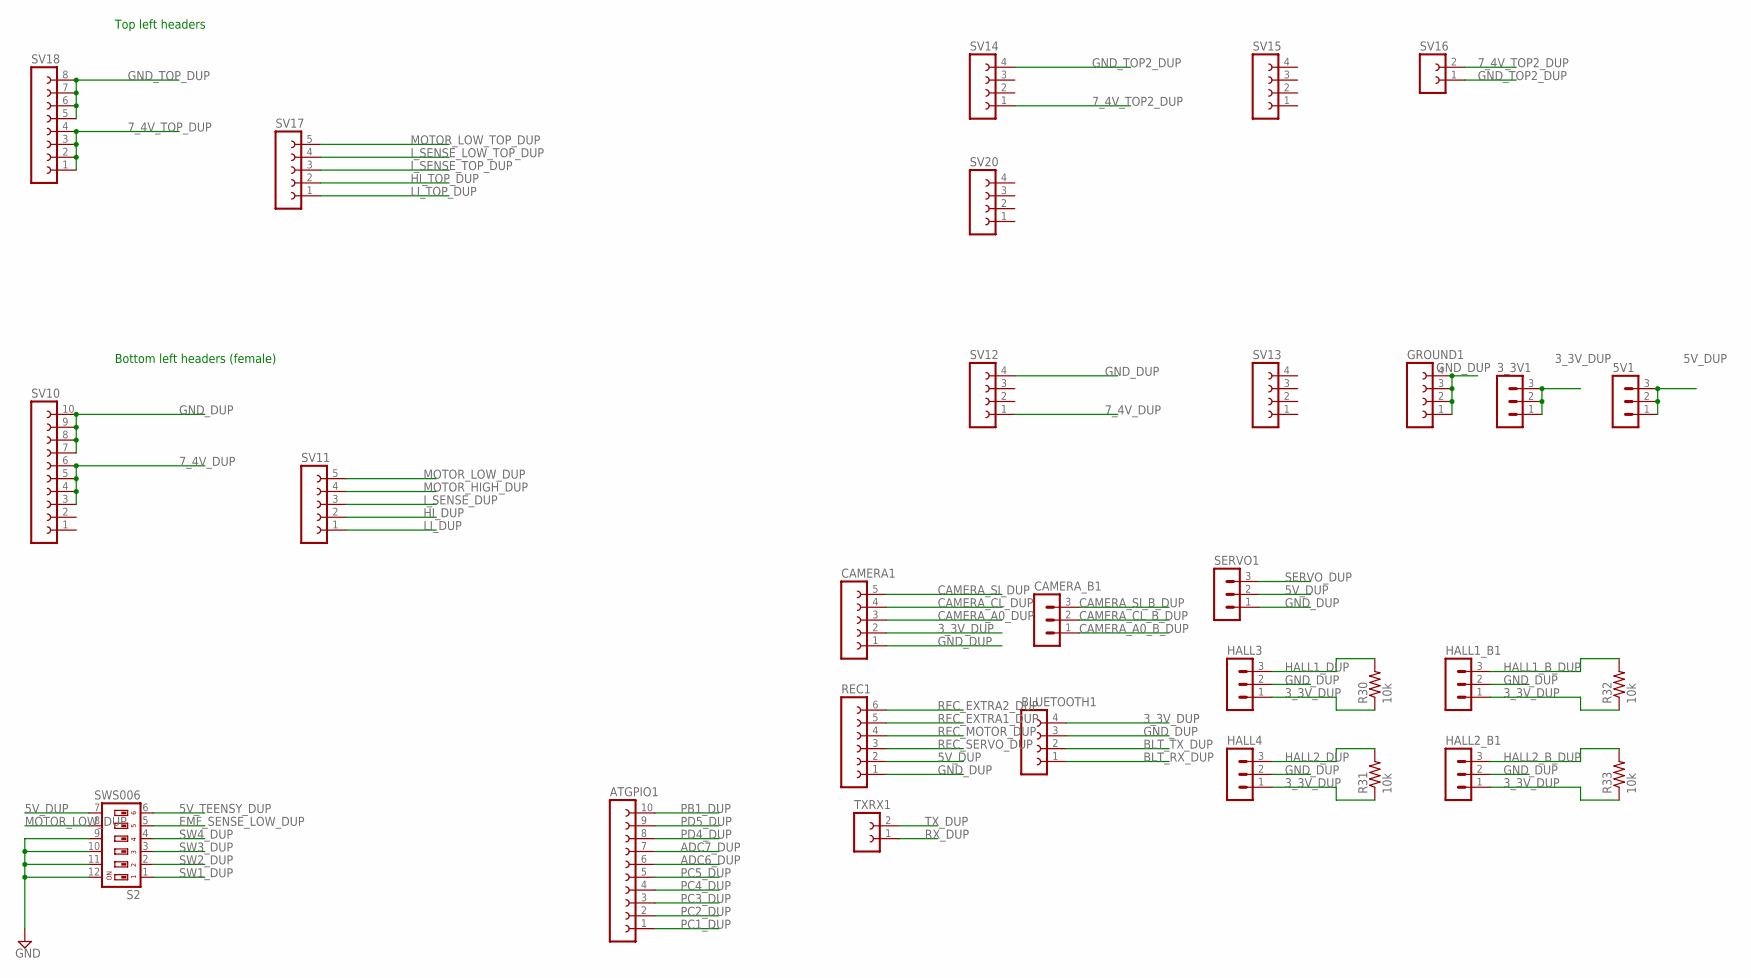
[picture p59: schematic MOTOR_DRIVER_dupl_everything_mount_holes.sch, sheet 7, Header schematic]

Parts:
3_3V1, 5V1: MA03-1
ATGPIO1: FE10-1; FE10
BLUETOOTH1: FE04-1; MANUFACTURER_PART_NUMBER HC-06
CAMERA1: FE05-1; MANUFACTURER_PART_NUMBER 28317; DIGIKEY_PART_NUMBER 28317-ND
CAMERA_B1: MA03-1; MANUFACTURER_PART_NUMBER 28317; DIGIKEY_PART_NUMBER 28317-ND
GROUND1: FE04-1
HALL1_B1, HALL2_B1, HALL3, HALL4: MA03-1; MANUFACTURER_PART_NUMBER US1881LUA-AAA-000-BU; DIGIKEY_PART_NUMBER US1881LUA-AAA-000-BU-ND
R30, R31, R32, R33: 10k; R0603
REC1: FE06-1; FE06
S2: SWS006; SMS-006; MANUFACTURER_PART_NUMBER 219-6MST; DIGIKEY_PART_NUMBER CT2196MST-ND
SERVO1: MA03-1; MANUFACTURER_PART_NUMBER TS-P12S
SV10: FE10-1; FE10
SV11, SV17: FE05-1
SV12, SV13, SV14, SV15, SV20: FE04-1
SV16: FE02-1
SV18: FE08-1; FE08
TXRX1: FE02-1

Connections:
3_3V_DUP: 3_3V1.1, 3_3V1.2, 3_3V1.3, BLUETOOTH1.4, CAMERA1.2, HALL1_B1.1, HALL2_B1.1, HALL3.1, HALL4.1, R30.1, R31.1, R32.1, R33.1; also elsewhere on the board
5V_DUP: 5V1.1, 5V1.2, 5V1.3, REC1.2, S2.7, SERVO1.2; also elsewhere on the board
5V_TEENSY_DUP: S2.6; also elsewhere on the board
7_4V_DUP: SV10.3, SV10.4, SV10.5, SV10.6, SV12.1; also elsewhere on the board
7_4V_TOP2_DUP: SV14.1, SV16.2; also elsewhere on the board
7_4V_TOP_DUP: SV18.1, SV18.2, SV18.3, SV18.4; also elsewhere on the board
ADC6_DUP: ATGPIO1.6; also elsewhere on the board
ADC7_DUP: ATGPIO1.7; also elsewhere on the board
BLT_RX_DUP: BLUETOOTH1.1; also elsewhere on the board
BLT_TX_DUP: BLUETOOTH1.2; also elsewhere on the board
CAMERA_A0_B_DUP: CAMERA_B1.1; also elsewhere on the board
CAMERA_A0_DUP: CAMERA1.3; also elsewhere on the board
CAMERA_CL_B_DUP: CAMERA_B1.2; also elsewhere on the board
CAMERA_CL_DUP: CAMERA1.4; also elsewhere on the board
CAMERA_SI_B_DUP: CAMERA_B1.3; also elsewhere on the board
CAMERA_SI_DUP: CAMERA1.5; also elsewhere on the board
EMF_SENSE_LOW_DUP: S2.5; also elsewhere on the board
GND_DUP: BLUETOOTH1.3, CAMERA1.1, GROUND1.1, GROUND1.2, GROUND1.3, GROUND1.4, HALL1_B1.2, HALL2_B1.2, HALL3.2, HALL4.2, REC1.1, S2.9, S2.10, S2.11, S2.12, SERVO1.1, SV10.7, SV10.8, SV10.9, SV10.10, SV12.4; also elsewhere on the board
GND_TOP2_DUP: SV14.4, SV16.1; also elsewhere on the board
GND_TOP_DUP: SV18.5, SV18.6, SV18.7, SV18.8; also elsewhere on the board
HALL1_B_DUP: HALL1_B1.3, R32.2; also elsewhere on the board
HALL1_DUP: HALL3.3, R30.2; also elsewhere on the board
HALL2_B_DUP: HALL2_B1.3, R33.2; also elsewhere on the board
HALL2_DUP: HALL4.3, R31.2; also elsewhere on the board
HI_DUP: SV11.2; also elsewhere on the board
HI_TOP_DUP: SV17.2; also elsewhere on the board
I_SENSE_DUP: SV11.3; also elsewhere on the board
I_SENSE_LOW_TOP_DUP: SV17.4; also elsewhere on the board
I_SENSE_TOP_DUP: SV17.3; also elsewhere on the board
LI_DUP: SV11.1; also elsewhere on the board
LI_TOP_DUP: SV17.1; also elsewhere on the board
MOTOR_HIGH_DUP: SV11.4; also elsewhere on the board
MOTOR_LOW_DUP: S2.8, SV11.5; also elsewhere on the board
MOTOR_LOW_TOP_DUP: SV17.5; also elsewhere on the board
PB1_DUP: ATGPIO1.10; also elsewhere on the board
PC1_DUP: ATGPIO1.1; also elsewhere on the board
PC2_DUP: ATGPIO1.2; also elsewhere on the board
PC3_DUP: ATGPIO1.3; also elsewhere on the board
PC4_DUP: ATGPIO1.4; also elsewhere on the board
PC5_DUP: ATGPIO1.5; also elsewhere on the board
PD4_DUP: ATGPIO1.8; also elsewhere on the board
PD5_DUP: ATGPIO1.9; also elsewhere on the board
REC_EXTRA1_DUP: REC1.5; also elsewhere on the board
REC_EXTRA2_DUP: REC1.6; also elsewhere on the board
REC_MOTOR_DUP: REC1.4; also elsewhere on the board
REC_SERVO_DUP: REC1.3; also elsewhere on the board
RX_DUP: TXRX1.1; also elsewhere on the board
SERVO_DUP: SERVO1.3; also elsewhere on the board
SW1_DUP: S2.1; also elsewhere on the board
SW2_DUP: S2.2; also elsewhere on the board
SW3_DUP: S2.3; also elsewhere on the board
SW4_DUP: S2.4; also elsewhere on the board
TX_DUP: TXRX1.2; also elsewhere on the board

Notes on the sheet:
Bottom left headers (female)
Top left headers

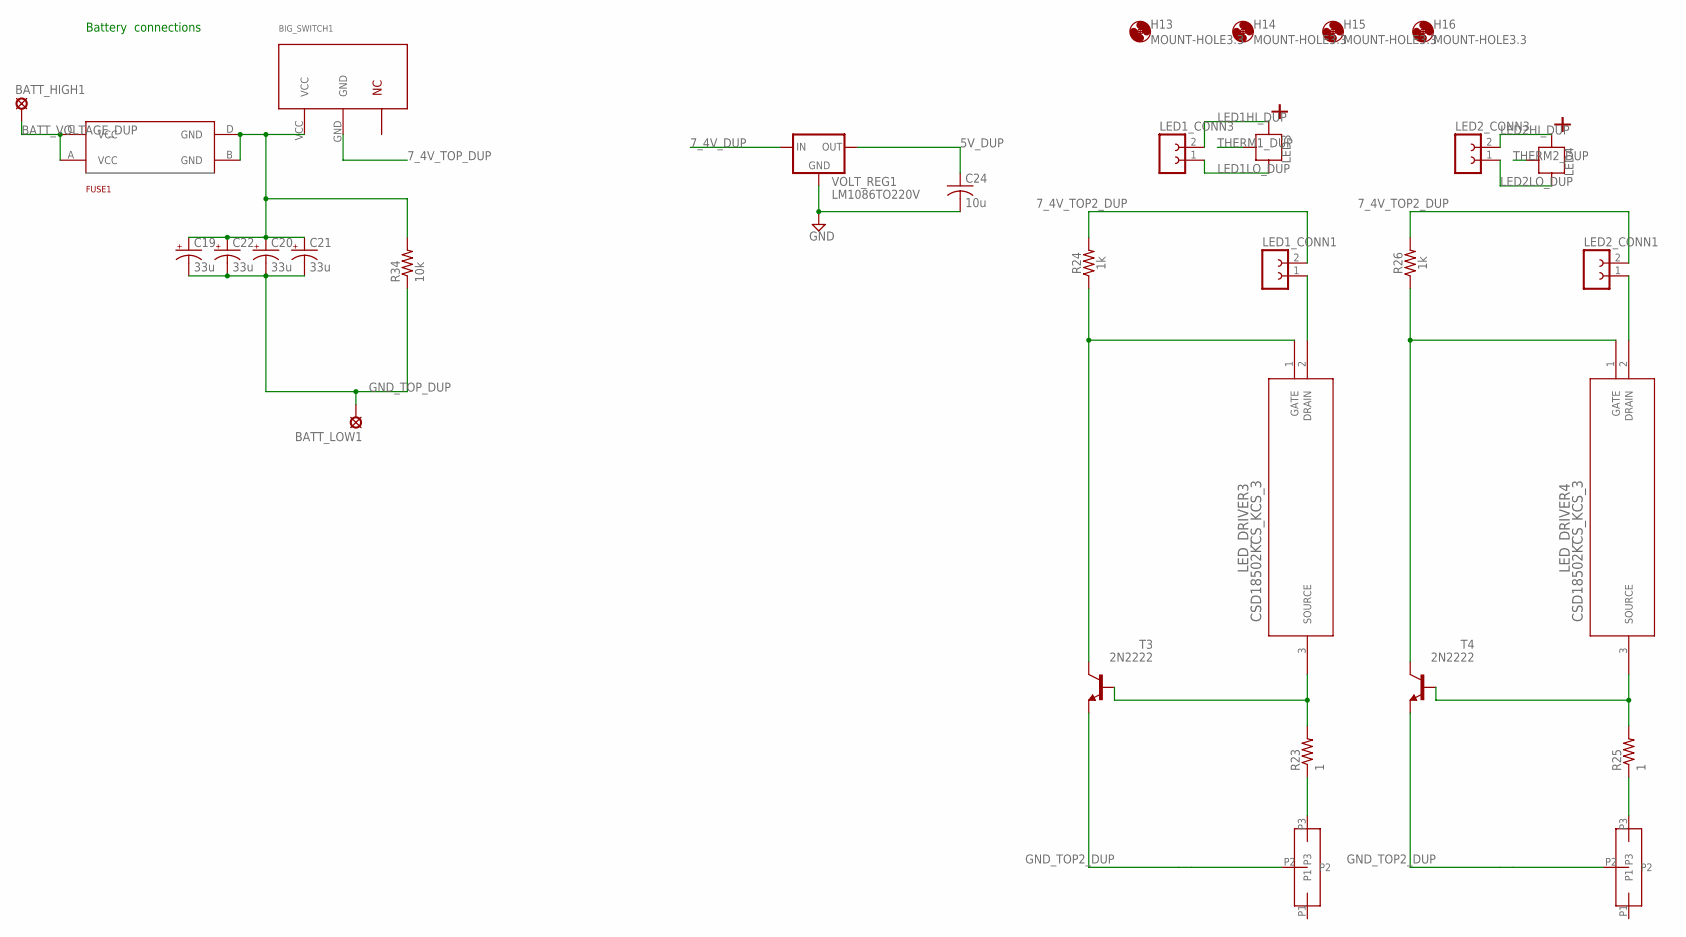
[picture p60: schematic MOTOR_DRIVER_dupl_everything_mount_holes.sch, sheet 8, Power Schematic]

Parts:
BATT_HIGH1: SE14
BATT_LOW1: SE14
BIG_SWITCH1: BIGSWITCH; MANUFACTURER_PART_NUMBER GRB238B801BR1; DIGIKEY_PART_NUMBER CW106-ND
C19, C20, C21, C22: 33u; 153CLV-1010
C24: 10u; C0805
FUSE1: FUSEHOLDER3588; MANUFACTURER_PART_NUMBER 0891010.NXS; DIGIKEY_PART_NUMBER F4989-ND
H13, H14, H15, H16: MOUNT-HOLE3.3; 3,3
LED1_CONN1, LED1_CONN3, LED2_CONN1, LED2_CONN3: FE02-1
LED3, LED4: CREE_XP; XP
LED_DRIVER3, LED_DRIVER4: CSD18502KCS_KCS_3; KCS3
R23, R25: 1; R2512
R24, R26: 1k; AXIAL-0.3
R34: 10k; R0603
T3, T4: 2N2222; TO18
U$14, U$15: POT
VOLT_REG1: LM1086TO220V; TO220S; MANUFACTURER_PART_NUMBER LM1086IT-5.0/NOPB; DIGIKEY_PART_NUMBER LM1086IT-5.0/NOPB-ND

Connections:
5V_DUP: C24.1, VOLT_REG1.2 (OUT); also elsewhere on the board
7_4V_DUP: VOLT_REG1.3 (IN); also elsewhere on the board
7_4V_TOP2_DUP: LED1_CONN1.2, LED2_CONN1.2, R24.P$2 (2), R26.P$2 (2); also elsewhere on the board
7_4V_TOP_DUP: BIG_SWITCH1.GND; also elsewhere on the board
BATT_VOLTAGE_DUP: BATT_HIGH1.MP, FUSE1.A (VCC), FUSE1.C (VCC)
GND_DUP: C24.2, VOLT_REG1.1 (GND); also elsewhere on the board
GND_TOP2_DUP: T3.1 (E), T4.1 (E), U$14.P2, U$15.P2; also elsewhere on the board
GND_TOP_DUP: BATT_LOW1.MP, C19.-, C20.-, C21.-, C22.-, R34.1; also elsewhere on the board
LED1HI_DUP: LED1_CONN3.2, LED3.POSITIVE, LED3.POSITIVE1 (POSITIVE)
LED1LO_DUP: LED1_CONN3.1, LED3.NEGATIVE, LED3.NEGATIVE1 (NEGATIVE)
LED2HI_DUP: LED2_CONN3.2, LED4.POSITIVE, LED4.POSITIVE1 (POSITIVE)
LED2LO_DUP: LED2_CONN3.1, LED4.NEGATIVE, LED4.NEGATIVE1 (NEGATIVE)
unnamed: BIG_SWITCH1.VCC, C19.+, C20.+, C21.+, C22.+, FUSE1.B (GND), FUSE1.D (GND), R34.2
unnamed: R23.1, U$14.P3
unnamed: LED_DRIVER3.3 (SOURCE), R23.2, T3.2 (B)
unnamed: LED_DRIVER3.1 (GATE), R24.P$1 (1), T3.3 (C)
unnamed: LED1_CONN1.1, LED_DRIVER3.2 (DRAIN)
unnamed: R25.1, U$15.P3
unnamed: LED_DRIVER4.3 (SOURCE), R25.2, T4.2 (B)
unnamed: LED_DRIVER4.1 (GATE), R26.P$1 (1), T4.3 (C)
unnamed: LED2_CONN1.1, LED_DRIVER4.2 (DRAIN)
THERM1_DUP: LED3.THERMAL
THERM2_DUP: LED4.THERMAL

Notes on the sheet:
Battery connections

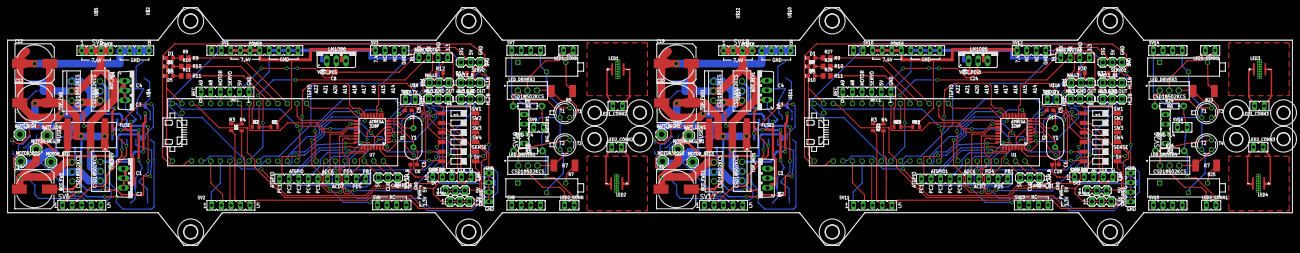
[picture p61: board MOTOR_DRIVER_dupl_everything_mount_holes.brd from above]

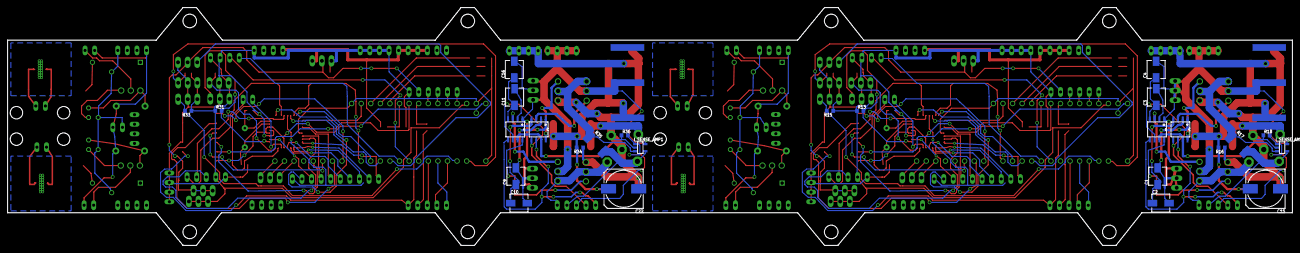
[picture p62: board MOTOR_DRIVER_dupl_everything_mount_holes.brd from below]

Board: 2 copper layers, 340.4 x 63.0 mm, 206 parts (26 on the bottom side), 180 nets.

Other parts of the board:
U$8, U$16: HEATSINK

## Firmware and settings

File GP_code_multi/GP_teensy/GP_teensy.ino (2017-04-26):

// copied from feb5_motors_tx_camera_servo_halleffect on 4/8. Goal was to drive with Tx running single threaded on PCB
// change pin numbers/names

// 4/24  significant changes to state flow and modes and changed topspeed pause condition:
// use enum types for state and modes. stateCheck() is modified to return "state" type, and it has multiple return statements.any paused condition will return pause. 
// topspeed pause condition is now same as topspeed for Tx throttle control. Maybe set it to something else? Probably limited our performance on saturday 4/22. 
// added throttle mode using bluetooth. 


// currently OL Tx throttle is linear + deadzone in input, linear in output 
// CL is Tx throttle input linear with no deadzone, but with deadzone in output. 
// CL preferred: Tx throttle input linear with deadzone. very little deadzone in output.

#include <Servo.h>
#include <SoftwareSerial.h>

unsigned long int prevLoop; // to track loop time

// useful function
double mapdouble(double x, double in_min, double in_max, double out_min, double out_max)
{
 return (double)(x - in_min) * (out_max - out_min) / (double)(in_max - in_min) + out_min;
}

// BLUETOOTH MODULE COMMUNICATION
//***********************************************************************
#define BTSERIAL Serial3
#define MESSAGE_BEGIN 29
#define MESSAGE_END 30
#define MAX_MESSAGE_SIZE 100

char messageBuffer[MAX_MESSAGE_SIZE]; // bluetooth message content
int bufferPos = 0; //keeps track of last char in messageBuffer

//Check if complete bluetooth packet was received
bool packetAvailable();

//Parse bt packet into name and value
void packetParse();

// Executes bluetooth command 
void exec_packet_cmd(char *cmd_name, char* cmd_value);

// Sends telemetry data through bluetooth back to computer monitoring
void telemetry();

// STATE FLOW
//************************************************************************
typedef enum {
  PLAY,
  PAUSE  
} state;
state myState = PLAY;

// for RC controlled state. pause when right stick all the way up
int stateValue;
int REC_STATE = 22;

int SW1 = 24; 
int SW2 = 25;
int SW3 = 26;
int SW4 = 27;

state stateCheck();

// DRIVE MODES
//************************************************************************
typedef enum {
  RC_TH,
  BT_TH,
  AUTO_TH,
} throttleMode;

throttleMode myThrottleMode = RC_TH;

typedef enum {
  RC_ST,
  AUTO_ST,
} steerMode;

steerMode mySteerMode = RC_ST;

// MOTORS
//************************************************************************
  int HI = 3; //pin numbers
  int LI = 4;
  
  int motorValue = 0;
  int brakeValue = 0;

  // allow Tx input fomr channel 3 (left stick vertical)
  int REC_MOTOR = 21; // pin to read signals from reciever
  int throttleValue;
  int topDutyCycleOL = 256*.5; //max speed
  int buffTx = 10; // buffer for tx input . full range of tx input is 1160 to 1830
  int throttleMid = 1500;
  void getSpeedOL(); //gets input from tx, assigns it to a desired speed, determines what to give HI and LI. 

  // closed loop speed control
  double vRef;
  double vMeas;
  double vError;
  double topSpeed = 10; // in ft/sec
  int topDutyCycleCL = 256*.5; // max speed 
  double kpSpeed = .5;
  double kiSpeed = 0.5;
  double vErrorTotal = 0.0;
  void getSpeedCL();

// CAMERA AND PROCESSING
//************************************************************************
  int pinSI = 29;
  int pinCL = 30;
  int pinAO = 31;
  
  int out[128]; //straight from camera;
  double averaged[128]; //after moving average filter
  double differences[127];//after taking differences
  
  int threshhold = 350; // for threshholding technique
  unsigned int integrationPeriod = 50;
  unsigned int prevCameraTime = 0;
  
  //gets one line of camera data
  void getline(int lineBuffer[]);
  
  //Calculates average of numsToAverage points around all elements in input
  // and stores each averaged point in result
  // input and result should be the same size.
  // input[]: Data to manipulate
  // arraySize: Size of input array
  // numsToAverage: Number of elements around point p to use to calculate the average
  // result[]: Array to return the results
  void averageElements(int input[], int arraySize, int numsToAverage, double result[]);
  
  //Calcualtes difference between adjencents elements of input and stores in result
  //result's size will be arraySize-1
  void diff(double input[], int arraySize, int result);
  
  //Finds max and min of input data, calculates center point bewtween max and min,
  //and returns the index of the calculated center point
  double center(double input[], int arraySize);

// SERVO
//************************************************************************
  int REC_SERVO = 20;
  int SERVO = 9;
  
  int servoValueMicro; //1000-2000 for full range. is actually less because of the physical stops 
  int servoMidMicro = 1455; // 2/18 test: min 1140, max 1770 before running into mechanical stops
  int servoRangeMicro = 315;
  
  Servo myServo;

// STEERING
//************************************************************************
  // for camera steering
  double xError; // xRef - xMeasured (from camera);
  double xRef = 64.0; // center is 64;
  double xMeasured;  
  double kSteering = .546875; // 35/64 = .546875 for full range. will be adjusted later.
  double kSteeringMicro =  (double)(servoRangeMicro)/64.00;
     
  void steerCamera(double xRef, double xMeasured); // steers using camera input 
  
  // for Tx steering
  void steerTx(); // steers using Tx input

// SPEED SENSING
//************************************************************************

  unsigned int hallTimeout = 500; // in millisec
  int speedLimit = topSpeed; //higher than this will pause it. 
  double wheelDiameter = 1.8; //inches
  
  int hallPin_L = 1;//left
  int hallValue_L;
  double wheelSpeed_L;
  double wheelSpeed_L_Copy = 0; //copy to prevent memory issues
  volatile unsigned long int prevHallTime_L; // volatile to prevent memory issues
  void magnet_detect_L();
  
  int hallPin_R = 2;//right
  int hallValue_R;
  double wheelSpeed_R;
  double wheelSpeed_R_Copy=0; //copy to prevent memory issues
  volatile unsigned long int prevHallTime_R; // volatile to prevent memory issues
  void magnet_detect_R();
  
// DIAGNOSTICS
//************************************************************************
  double BATT_VOLTAGE_SENSE = 17; //pin number;
  double battVoltSenseVal;
  double battVoltVal;
  double battConst = 2.728*.992; // (R2+R1)/R1; R1 = 2.8k, R2 = 1.62k, also a fudge factor 
  double battPeriod = 1000; 
  double battPrevTime = 0;
  double lowBattWarning = 6.7;
  double getBattVoltVal();

  double EMF_SENSE_HIGH = 19;
  double emfSenseHigh = 0;
  double EMF_SENSE_LOW = 18;
  double emfSenseLow = 0;
  double emfConst = 3.0174; // (R3+R4)/R4; R3 = 2.32k, R4 = 1.15k
  double emfHigh; // emfHighV = (emfSenseHighVal - emfSenseLowVal)*emfConst;
  double emf; //emf = emfHigh-emfSenseLow

  double I_SENSE = 5;
  double iSenseV;
  double iCalc;
  double iConst = 2.5; // 5k /(RS*RL) RS = .02 RL = 100k. unreliable with RL = 100k? RL = 10k better for ADC
  
// MAIN CODE
//************************************************************************
void setup() {
  Serial.begin(9600); //setting speed of communication in bits/second

  //bluetooth serial
  BTSERIAL.begin(9600);

  //state flow
    pinMode(REC_STATE,INPUT);
    pinMode(SW1,INPUT_PULLUP);
  //Motor things  
    pinMode(HI,OUTPUT);
    pinMode(LI,OUTPUT);

  //for transmitter throttle
    pinMode(REC_MOTOR,INPUT);
  
  //camera stuff
    pinMode(pinSI,OUTPUT);
    pinMode(pinCL,OUTPUT);
    pinMode(pinAO, INPUT);
  
  //from transmitter to control the servo
    pinMode(REC_SERVO,INPUT);
    myServo.attach(SERVO);

  //speed sensing
    pinMode(hallPin_L,INPUT);
    attachInterrupt(digitalPinToInterrupt(hallPin_L), magnet_detect_L, RISING); //set up interrupt function. should work on any teensy pin.

    pinMode(hallPin_R,INPUT);
    attachInterrupt(digitalPinToInterrupt(hallPin_R), magnet_detect_R, RISING); //set up interrupt function. should work on any teensy pin.

  // diagnostics
    pinMode(BATT_VOLTAGE_SENSE,INPUT);
    
    pinMode(EMF_SENSE_HIGH, INPUT);
    pinMode(EMF_SENSE_LOW,INPUT);

    pinMode(I_SENSE, INPUT);
    
  //indicator LED that program is running
    pinMode(14, OUTPUT);
    digitalWrite(14,HIGH);

    pinMode(15, OUTPUT);
    digitalWrite(15,HIGH);

    pinMode(16, OUTPUT);
    digitalWrite(16,HIGH);

    Serial.println("Setup Successful");
}

void loop() {

  //if (stateCheck()) // 1 if everything is fine
  if(stateCheck() == PLAY)
  {
    //openloop
    //getSpeedOL();
    //closedloop
    getSpeedCL();
  
  //Write to motor
     analogWrite(HI, motorValue); //HI denotes the pin on which the motor is in; motorValue represents the duty cycle of the PWM
     analogWrite(LI, brakeValue);
     Serial.print(" motor = ");
     Serial.print(motorValue); //corresponding value of the motor that runs at the value of PotValue
     Serial.print(" brake = ");
     Serial.print(brakeValue); 
  
  //Get a line of camera data
    while(millis()- prevCameraTime < integrationPeriod) {}
    getline(out);
    //print it
    /*
    Serial.print("camera raw: ");
    
    for(int i=0; i<128; i++)  {
      
      Serial.print(out[i]);
      Serial.print(",");
      
      }
    */
     
  //Determine the center
    averageElements(out,128,3,averaged);   
    diff(averaged,128,differences);
    xMeasured = center(differences,127);
    Serial.print(" xMeasured: ");
    Serial.print(xMeasured);
    
  if (mySteerMode == RC_ST)  
    {//Get Tx steering input and writes to servo
    steerTx();
    }
  else 
    {//Camera feedback to write to servo instead
    steerCamera(xRef,xMeasured);
    }
    
  //Speed Sensing
    Serial.print(" Speed data: ");
    /*
    Serial.print(prevHallTime_R);
    Serial.print(" ");
    Serial.print(millis());
    Serial.print(" ");
    */
    if ( (millis()-prevHallTime_R) > hallTimeout )
    wheelSpeed_R = 0;
    
    noInterrupts(); // to prevent memory issues
    wheelSpeed_R_Copy = wheelSpeed_R;
    interrupts();
    
    hallValue_R = analogRead(hallPin_R);
    //Serial.print(" hallPin_R: ");
    //Serial.print(hallValue_R);
    //Serial.print(" ");
    Serial.print(" wheelSpeed_R: ");
    Serial.print(wheelSpeed_R_Copy);
  //Diagnostics
    //batt voltage runs once in a while
    if ( millis() - battPrevTime > battPeriod)
    {
      getBattVoltVal();
    }

    Serial.print(" Batt: ");
    Serial.print(battVoltVal);
    /*
    //reading emf 
    emfSenseHigh = mapdouble(analogRead(EMF_SENSE_HIGH),0,1023,0,3.3);
    emfSenseLow = mapdouble(analogRead(EMF_SENSE_LOW),0,1023,0,3.3);
    emfHigh = (emfSenseHigh - emfSenseLow)*emfConst;
    emf = emfHigh-emfSenseLow;
    Serial.print(" emfSenseLow(V): ");
    Serial.print(emfSenseLow);
    Serial.print(" emfSenseHigh(V): ");
    Serial.print(emfSenseHigh);
    Serial.print(" emf(V): ");
    Serial.print(emf);
*/
    //reading motor current
    iSenseV = mapdouble(analogRead(I_SENSE),0,1023,0,3.3);
    iCalc = iConst * iSenseV;
    Serial.print(" iSenseV: ");
    Serial.print(iSenseV);
    Serial.print(" iCalc: ");
    Serial.print(iCalc); 

     
   telemetry();
  //Print loop time
    Serial.print(" Looptime: ");    
    Serial.println(millis()-prevLoop);
    prevLoop = millis();
  }

  else // PAUSE if pause signal is high
  {
     Serial.print("PAUSE");
     analogWrite(HI, 0);
     analogWrite(LI, 0);
     while (stateCheck() == PAUSE)
     {
      Serial.println("PAUSE");
      delay(100);
     }       
  }  
}

// FUNCTION DEFINITIONS
//************************************************************************


bool packetAvailable()
{
  while(BTSERIAL.available() > 0)
    {
      char incomingByte = BTSERIAL.read();

      if(incomingByte == MESSAGE_BEGIN)
      {
        //clear buffer for new incoming packet
        bufferPos = 0;
      }
      else if(incomingByte == MESSAGE_END)
      {
        //full packet received
        messageBuffer[bufferPos] = '\0';
        return true;
      }
      else
      {
        messageBuffer[bufferPos] = incomingByte;
        bufferPos++;
      }
         
    }

    return false;
}

void packetParse()
{  
  char packet_name[40];
  char packet_value[40] = {0};
  long int value = 0;
  
  //get divider position
  char *separator = strchr(messageBuffer, ':');
  *separator = '\0';

  //get command name
  strcpy(packet_name, messageBuffer);

  //skip white space
  *separator = ':';
  separator += 2;

  //get value
  for(int i = 0; *separator != '\0'; i++, separator++)
    packet_value[i] = *separator;

  exec_packet_cmd(packet_name, packet_value);

  BTSERIAL.write("\b");
  BTSERIAL.write(messageBuffer);
  BTSERIAL.write("\n");
}

void exec_packet_cmd(char *cmd_name, char* cmd_value)
{

  char chg_state[] = "change_state";
  char change_kpSpeed[] = "kpSpeed";
  char change_kiSpeed[] = "kiSpeed";

  if(strcmp(chg_state, cmd_name) == 0)
  {
      long int value = strtol(cmd_value, NULL, 10);

      if(value == 1)
        myState = PLAY;
      else
        myState = PAUSE;
  }
  else if(strcmp(change_kpSpeed, cmd_name) == 0)
  {
    double value = strtod(cmd_value, NULL);

    kpSpeed = value;
  }
  else if(strcmp(change_kiSpeed, cmd_name) == 0)
  {
    double value = strtod(cmd_value, NULL);

    kiSpeed = value;
  }
  
/*  
  Serial.write("name: ");
  Serial.println(cmd_name);

  Serial.write("value: ");
  Serial.println(cmd_value);
*/
}

void telemetry()
{
  /*
  Serial.print(" motor = ");
  Serial.print(motorValue); //corresponding value of the motor that runs at the value of PotValue
  Serial.print(" brake = ");
  Serial.print(brakeValue); 

  Serial.print("transmitter (1160 to 1830) = " );     
  Serial.print(throttleValue); //integer between 1160 and 1830

  Serial.print(" servoValueMicro: ");
  Serial.print(servoValueMicro);

  Serial.print(" steerValue: ");
  Serial.print(steerValue);

  */

  
  //String strdata = String("mtr:" + String(motorValue) + ";brk:" + String(brakeValue) + ";trstr:" + String(throttleValue) + ";srv:" + String(servoValueMicro) + ";spd:" + String(wheelSpeed_R_Copy));
  String strdata = String("vref: " + String(vRef) + " vMeas: " + vMeas + " vErr: " + vError + " kpSpeed: " + kpSpeed + " vErrorTotal: " + vErrorTotal + " kiSpeed: " + kiSpeed);

  //Serial.println("Telemetry data: ");
  //Serial.println(strdata.c_str());

  //char data[strdata.length() + 1];
  BTSERIAL.write("\b");
  BTSERIAL.write(strdata.c_str());
  BTSERIAL.write("\n");
  //BTSERIAL.write("\b");
  //BTSERIAL.write("A");
  //BTSERIAL.write("\n");  
}

state stateCheck()
{
  //Serial.println("checking state");
  // If pause switch is on
  if (digitalRead(SW1) == LOW) 
    {
      myState = PAUSE;
      Serial.print(digitalRead(SW1));
      Serial.println("pause switch");
      return myState;
    }
  
  //If Tx says to pause
  stateValue = pulseIn(REC_STATE, HIGH, 25000);
  if (stateValue > 1750 && stateValue < 2000 ) // channel is all the way high
    {myState = PAUSE;
    Serial.println(stateValue);
    return myState;}
    
  //Check for bluetooth message that might change state

  /*
  if(packetAvailable())
     packetParse();
  if (myState == PAUSE)
     {return myState;}   
  */
  // low Batt Warning
  
  if ( getBattVoltVal() < lowBattWarning )
  {
    if (millis() > 2000)
    {
      Serial.println("batt volts error");
      myState = PAUSE;
      return myState;
    }
  }
  //exceeding top speed 

  
  noInterrupts();
  wheelSpeed_R_Copy = wheelSpeed_R;
  interrupts();
    
  if (wheelSpeed_R_Copy > speedLimit )
    {myState = PAUSE;
    return myState;}
 
  myState = PLAY;
  return myState;
}

void getline(int lineBuffer[])
{ 
  //digitalWrite(triggerPin2, HIGH);
  digitalWrite(pinSI, HIGH);
  digitalWrite(pinCL, HIGH);
  lineBuffer[0] = analogRead(pinAO);
  digitalWrite(pinSI, LOW);
  digitalWrite(pinCL, LOW);
 int i;
  for (i=1;i<128;i++)
  {
    digitalWrite(pinCL, HIGH);
    lineBuffer[i] = analogRead(pinAO);
    digitalWrite(pinCL, LOW);
    //Serial.print(out[i]);
    //Serial.print(" ");
  }
  //digitalWrite(triggerPin2, LOW);
  prevCameraTime = millis();
}

void averageElements(int input[], int arraySize, int numsToAverage, double result[])
{
  double sum;
  int elementsUsed; //keep track of how many elements were used for sum
  double average;

  for(int i = 0; i < arraySize; i++)
  {
    sum = 0;
    elementsUsed = 0;
  
    for(int j = 1; j <= numsToAverage; j++)
    {
      //check for valid index going to left of array
      if((i-j) >= 0)
      {
        sum += input[i-j];
        elementsUsed++;  
      }

      //check for valid index going to right of array
      if((i+j) < arraySize)
      {
        sum += input[i+j];
        elementsUsed++;
      }
    }// end of inner loop

    //calculate average
    average = sum / elementsUsed;
    result[i] = average;
    
  } //end of outer loop
  
}

void diff(double input[], int arraySize, double result[])
{
  for(int i = 1; i < arraySize; i++)
    result[i-1] = input[i] - input[i-1];
}

double center(double input[], int arraySize)
{
  //Index of max and min
  int maxIndex = 0;
  int minIndex = 0;
  int maxValue = 0;
  int minValue = 1000.0;  

  //Find max and min
  for(int i = 0; i < arraySize; i++)
  {
    if(input[i] < minValue)
    {
      minValue = input[i];
      minIndex = i;
    }
    else if(input[i] > maxValue)
    {
      maxValue = input[i];
      maxIndex = i;
    }
  }

  return (minIndex + maxIndex) / 2.0;
}
/*
void getPot()
{
     potentioValue = analogRead(potentioPin); //value between 0 and 1023 
     motorValue = constrain(map(potentioValue, 512+buff, 1023, 0, 256),0,256);
     brakeValue = constrain(map(potentioValue, 511-buff, 0, 0, 256),0,256);
     Serial.print("potentiometer = " );     
     Serial.print(potentioValue); //integer between 0 and 1023 
}
*/
void getSpeedOL()
{
     throttleValue = pulseIn(REC_MOTOR, HIGH, 25000); //throttleValue is speed setpoint open loop
     if ( throttleValue < 1000 || throttleValue > 2000)
     {
      throttleValue = throttleMid;
     }

     motorValue = constrain(map(throttleValue, throttleMid+buffTx,1850, 0, topDutyCycleOL),0,topDutyCycleOL);
     brakeValue = constrain(map(throttleValue, throttleMid-buffTx,1150, 0, topDutyCycleOL),0,topDutyCycleOL);
     Serial.print("transmitter (1150 to 1850) = " );     
     Serial.print(throttleValue); //integer between 1150 and 1850
}

// needs a lot of work
void getSpeedCL()
{
  throttleValue = pulseIn(REC_MOTOR, HIGH, 25000); // throttleValue is a Speed setpoint used for closed loop
  if ( throttleValue < 1000 || throttleValue > 2000)
  {
    throttleValue = throttleMid;
  }
  
  vRef = constrain(mapdouble(throttleValue,1150,1850,-topSpeed, topSpeed),-topSpeed,topSpeed); //convert to ft per sec
  
  vMeas = wheelSpeed_R_Copy;
  vError = vRef-vMeas; // in ft/sec
  vErrorTotal += vError;
  Serial.print(" vRef: ");
  Serial.print(vRef);
  Serial.print(" vError: ");
  Serial.print(vError);

  throttleValue = throttleValue + kpSpeed*vError + kiSpeed*vErrorTotal; //kpSpeed must be in us /(ft/sec)

  //throttleValue = constrain(mapdouble(vError,-topSpeed,topSpeed,1000,2000),1000,2000); //convert back to microseconds
  
  motorValue = constrain(map(throttleValue, throttleMid+buffTx,1850, 0, topDutyCycleCL),0,topDutyCycleCL);
  brakeValue = constrain(map(throttleValue, throttleMid-buffTx,1150, 0, topDutyCycleCL),0,topDutyCycleCL);
  
  Serial.print(" throttleValue (1150 to 1850) = " );     
  Serial.print(throttleValue); //integer between 1160 and 1830
}

void steerTx() //needs checking
{
 //get data from Tx 
 servoValueMicro = pulseIn(REC_SERVO,HIGH, 25000);

  if ( servoValueMicro < 1000 || servoValueMicro > 2000)
  {
    servoValueMicro = servoMidMicro;
  }
  
 //servoValue = map(servoValue,1350,1730,1000,2000); was used for calibration
 //map to servo steering range
   // 0-180
      //servoValue = constrain( map( servoValue, 1830, 1160, servoMid - servoRange, servoMid + servoRange ), servoMid - servoRange, servoMid + servoRange );
      //myServo.write(servoValue); 
   //1000-2000
      //servoValue = constrain(map( servoValue,1830,1160,servoMidMicro - servoRangeMicro, servoMidMicro + servoRangeMicro), servoMidMicro - servoRangeMicro, servoMidMicro + servoRangeMicro );
 servoValueMicro = constrain(servoValueMicro,servoMidMicro-servoRangeMicro,servoMidMicro+servoRangeMicro);
 servoValueMicro = map(servoValueMicro, servoMidMicro-servoRangeMicro,servoMidMicro+servoRangeMicro,servoMidMicro+servoRangeMicro,servoMidMicro-servoRangeMicro);
 myServo.writeMicroseconds(servoValueMicro);
 Serial.print(" servoValueMicro: ");
 Serial.print(servoValueMicro);
}

void steerCamera(double xRef, double xMeasured)
{
  double xError;
  double steerValue;
  xError = xRef - xMeasured;
  //0-180
    //steerValue = servoMid + kSteering*xError; // for full range: 64 pixels --> 35 ms has kSteering = 35/64 = .546875
    //myServo.write(steerValue);
  //1000-2000
    steerValue = servoMidMicro + kSteeringMicro*xError;
    steerValue = constrain(steerValue,servoMidMicro-servoRangeMicro, servoMidMicro+servoRangeMicro);
    myServo.writeMicroseconds(steerValue);
  //does fullrange camera to fullrange servo
  //steerValue = constrain( map( xMeasured, 128, 0, servoMid - servoRange, servoMid + servoRange ), servoMid - servoRange, servoMid + servoRange );
   
  Serial.print(" steerValue: ");
  Serial.print(steerValue);
}

void magnet_detect_L()
{
  wheelSpeed_L = (wheelDiameter*PI/12/3)/((millis()-prevHallTime_L)/1000.0); // converts to ft/sec
  Serial.println("magnet_detect_L");
}

void magnet_detect_R()
{
  wheelSpeed_R = (wheelDiameter*PI/12/3)/((millis()-prevHallTime_R)/1000.0); // converts to ft/sec
  prevHallTime_R = millis();
}

double getBattVoltVal(){
      battVoltSenseVal = analogRead(BATT_VOLTAGE_SENSE);
      battVoltVal = battVoltSenseVal*battConst/1024.0*3.3;
      battPrevTime = millis();
      return battVoltVal;
} 

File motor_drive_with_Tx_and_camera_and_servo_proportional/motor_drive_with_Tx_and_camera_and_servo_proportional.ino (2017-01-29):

//control speed of DC motor with a potentiometer
//0-512 is braking, and 513-1023 is forward. There is an adjustable buffer;
//77 = .3 of 256. 180 = .7 of 256

#include <Servo.h>

// motor driver
int potentioPin = 14; //integer variable denoting the pin with the potentiometer, gets assigned a value from 0-1023 for 0-5
int motorPin = 3; //likewise with motor, arbitrary pin number 1
int brakePin = 4;
int triggerPin = 9; // help when looking at O-scope
int triggerPin2 = 10; // help when looking at O-scope
int potentioValue = 0; //will be an integer between 0 and 1023
int motorValue = 0;
int brakeValue = 0;
int buff = 100; // deadzone

// transmitter and motor driver
int pinTx = 15; // pin to read signals from reciever
int topSpeed = 256;
int buffTx = 100; // buffer for tx input . full range of tx input is 1160 to 1830

// camera
int SI = 5;
int CL = 6;
int AO = 17;
int out[130];
int filtered[128];
int threshhold = 350;
unsigned int integrationPeriod = 50;
unsigned int prevCameraTime = 0;
void getline(int lineBuffer[]);
int findcenter();

//Calculates average of numsToAverage points around all elements in input
// and stores each averaged point in result
// input and result should be the same size.
// input[]: Data to manipulate
// arraySize: Size of input array
// numsToAverage: Number of elements around point p to use to calculate the average
// result[]: Array to return the results
void averageElements(int input[], int arraySize, int numsToAverage, double result[]);

//Calcualtes difference between adjencents elements of input and stores in result
//result's size will be arraySize-1
void diff(double input[], int arraySize, int result);

//Finds max and min of input data, calculates center point bewtween max and min,
//and returns the index of the calculated center point
int center(double input[], int arraySize);

//servo
int servoPinIn = 18;
int servoPinOut = 20;
int servoValue; //0-180 for full range. less because of the physical stops 
int servoMid = 82;
int servoRange = 35;
Servo myServo;

//steering
int measuredMid = 0; 
void steer();

void setup() {
  Serial.begin(9600); //setting speed of communication in bits/second
    
  pinMode(potentioPin,INPUT); //turn on ADC at pin; ready to read voltages
  pinMode(motorPin,OUTPUT);
  pinMode(brakePin,OUTPUT);
  pinMode(triggerPin,OUTPUT);

  //indicator LED that program is running
  pinMode(13, OUTPUT);
  digitalWrite(13,HIGH);
  
  //for transmitter throttle
  pinMode(pinTx,INPUT);
  
  //camera stuff
  pinMode(SI,OUTPUT);
  pinMode(CL,OUTPUT);
  pinMode(AO, INPUT);
  
  //from transmitter to control the servo
  pinMode(servoPinIn,INPUT);
  myServo.attach(servoPinOut);
  //analogWriteFrequency(motorPin, 9800);
  //analogWriteFrequency(brakePin, 9800);
}

void loop() {
 /// pot  
 /*
     potentioValue = analogRead(potentioPin); //value between 0 and 1023 
     motorValue = constrain(map(potentioValue, 512+buff, 1023, 0, 256),0,256);
     brakeValue = constrain(map(potentioValue, 511-buff, 0, 0, 256),0,256);
     Serial.print("potentiometer = " );     
     Serial.print(potentioValue); //integer between 0 and 1023 
 */
 /// transmitter to set motor speed and brake speed
     potentioValue = pulseIn(pinTx, HIGH, 25000);
     motorValue = constrain(map(potentioValue, 1495+buffTx,1830, 0, topSpeed),0,topSpeed);
     brakeValue = constrain(map(potentioValue, 1495-buffTx,1160, 0, topSpeed),0,topSpeed);
     Serial.print("transmitter (1160 to 1830) = " );     
     Serial.print(potentioValue); //integer between 1160 and 1830

 analogWrite(motorPin, motorValue); //motorPin denotes the pin on which the motor is in; motorValue represents the duty cycle of the PWM
 analogWrite(brakePin, brakeValue);
 analogWrite(triggerPin, 10); //help with O-scope reading
 
 Serial.print(" motor = ");
 Serial.print(motorValue); //corresponding value of the motor that runs at the value of PotValue
 Serial.print(" brake = ");
 Serial.print(brakeValue); 

 while(millis()- prevCameraTime < integrationPeriod) {}
 getline(out);
 Serial.print("camera raw:");
 for(int i=0; i<128; i++)  {
    Serial.print(out[i]);
    Serial.print(',');
 }
 Serial.println('\n');
 measuredMid = findcenter();
 steer(); 

 Serial.println(" ");
}

void getline(int lineBuffer[])
{ 
  digitalWrite(triggerPin2, HIGH);
  digitalWrite(SI, HIGH);
  digitalWrite(CL, HIGH);
  lineBuffer[0] = analogRead(AO);
  digitalWrite(SI, LOW);
  digitalWrite(CL, LOW);
 int i;
  for (i=1;i<128;i++)
  {
    digitalWrite(CL, HIGH);
    lineBuffer[i] = analogRead(AO);
   digitalWrite(CL, LOW);
    //Serial.print(out[i]);
    //Serial.print(" ");
  }
  digitalWrite(triggerPin2, LOW);
  prevCameraTime = millis();
}


int findcenter()
{
  int leftEdge = 128, rightEdge = 0, center = 64;
  int i=0;
  while (out[i] < threshhold)
  {
    i++;
  }
  leftEdge = i;

  while(out[i] > threshhold)
  {
    i++;
  }
  
  rightEdge = i;
  center = (double) leftEdge / (double) rightEdge;
  Serial.print(" detected center: ");
  Serial.print(center);
  return center; 
}

void steer()
{
// this is for proportional feedback  
/*
  int steerValue;
  steerValue = constrain( map( measuredMid, 128, 0, servoMid - servoRange, servoMid + servoRange ), servoMid - servoRange, servoMid + servoRange );
  myServo.write(steerValue);
  Serial.print(" steerValue: ");
  Serial.print(steerValue);
*/
// without camera and proportional feedback, just use transmitter signal

 servoValue = pulseIn(servoPinIn,HIGH, 25000);
 servoValue = constrain( map( servoValue, 1830, 1160, servoMid - servoRange, servoMid + servoRange ), servoMid - servoRange, servoMid + servoRange );
 myServo.write(servoValue);
 Serial.print(" servoValue: ");
 Serial.print(servoValue);

}

void averageElements(int input[], int arraySize, int numsToAverage, double result[])
{
  double sum;
  int elementsUsed; //keep track of how many elements were used for sum
  double average;

  for(int i = 0; i < arraySize; i++)
  {
    sum = 0;
    elementsUsed = 0;
  
    for(int j = 1; j <= numsToAverage; j++)
    {
      //check for valid index going to left of array
      if((i-j) >= 0)
      {
        sum += input[i-j];
        elementsUsed++;  
      }

      //check for valid index going to right of array
      if((i+j) < arraySize)
      {
        sum += input[i+j];
        elementsUsed++;
      }
    }// end of inner loop

    //calculate average
    average = sum / elementsUsed;
    result[i] = average;
    
  } //end of outer loop
  
}


void diff(double input[], int arraySize, double result[])
{
  for(int i = 1; i < arraySize; i++)
    result[i-1] = input[i] - input[i-1];
}
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

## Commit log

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2017-02-04 made camera mount
    [camMount20170203.SLDPRT, camMount20170203.STL]
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2017-02-05 Added layout files
    Layout files are in GPLayout folder
    [MOTOR_DRIVER.sch]
2017-02-05 Added updated layout files
    [MOTOR_DRIVER.brd]
2017-02-05 Updated all schematic sheets
    [MOTOR_DRIVER.sch, MOTOR_DRIVER_old.brd]
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2017-02-11 Multilevel design
    [MOTOR_DRIVER.sch]
2017-02-12 component placement
    [MOTOR_DRIVER.brd, MOTOR_DRIVER.sch]
2017-02-12 adding HES mount and some old files
    [4 mil attempt 2-4 - mount 4 mil error-1.STL, 4 mil attempt 2-4 - pin 4 mill error-2.STL, 4 mil attempt 2-4 - stick 4 mill error-1.STL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]
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2017-02-12 2 level design - incomplete
    [MOTOR_DRIVER.sch]
2017-02-12 Changed to two schematic sheets
    [MOTOR_DRIVER.brd, MOTOR_DRIVER.sch]
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2017-02-12 Actual 4 schematic sheet update
    [MOTOR_DRIVER.brd, MOTOR_DRIVER.sch]
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2017-02-15 modified power schematic, added battery sense, named motor terminals
    [MOTOR_DRIVER.brd, MOTOR_DRIVER.sch]
2017-02-15 added some heatsink outlines
    [MOTOR_DRIVER.brd, MOTOR_DRIVER.sch]
2017-02-17 modified footprint for MOS to have name and indicate orientation
    [MOTOR_DRIVER.brd, MOTOR_DRIVER.sch]
2017-02-18 Changed battery sense resistances
    Input impedance might be too high for the Teensy ADC
    [MOTOR_DRIVER.brd, MOTOR_DRIVER.sch]
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2017-02-19 added motor inputs for full bridge
    [MOTOR_DRIVER.brd, MOTOR_DRIVER.sch]
2017-02-19 fixed LI2 and HI2 errors
    [MOTOR_DRIVER.brd, MOTOR_DRIVER.sch]
2017-02-19 added backup pins on Teensy for camera and HES
    [MOTOR_DRIVER.brd, MOTOR_DRIVER.sch]
2017-02-20 t :wq # Explicit paths specified without -i or -o; assuming --only paths...
    [MOTOR_DRIVER.brd, MOTOR_DRIVER.sch]
2017-02-20 messed up some git command, made new folder. major changes to connectors. may be missing lbr files for some parts. work in progress.
    [MOTOR_DRIVER.brd, MOTOR_DRIVER.sch]
2017-02-24 checking that its updated
    [MOTOR_DRIVER.brd, MOTOR_DRIVER.sch]
2017-02-25 added gpio, modified layout
    [MOTOR_DRIVER.brd, MOTOR_DRIVER.sch]
2017-02-25 ISCP connectors
    [MOTOR_DRIVER.brd, MOTOR_DRIVER.sch]
2017-02-26 added led driver, indicator leds, etc
    [MOTOR_DRIVER.brd, MOTOR_DRIVER.sch]
2017-02-26 double check
    [MOTOR_DRIVER.brd]
2017-02-26 batt voltage connection fixed
    [MOTOR_DRIVER.brd, MOTOR_DRIVER.sch]
2017-02-26 moved dip switch
    [MOTOR_DRIVER.brd]
2017-02-26 added actual LEDs
    [MOTOR_DRIVER.brd, MOTOR_DRIVER.sch]
2017-02-26 added some resistors
    [MOTOR_DRIVER.brd, MOTOR_DRIVER.sch]
2017-02-26 added some resistors, atmega gpio, placed them
    [MOTOR_DRIVER.brd, MOTOR_DRIVER.sch]
2017-02-26 modified placement
    [MOTOR_DRIVER.brd, MOTOR_DRIVER.sch]
2017-02-26 modified placement of header pins
    [MOTOR_DRIVER.brd]
2017-02-27 new folder with same schematic and board as last version of GP Layout 2. This folder contains all libraries used in that design as of 2/26. Use this folder from now on
    [MOTOR_DRIVER.brd, MOTOR_DRIVER.sch]
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2017-03-05 Added component attributes
    Added manufacturer, part number, and price to part attributes.
    [MOTOR_DRIVER.brd]
2017-03-05 Fixed a couple top wires on gate driver chip and gnd
    [MOTOR_DRIVER.brd, MOTOR_DRIVER.sch]
2017-03-05 Added more wires to top board
    [MOTOR_DRIVER.brd, MOTOR_DRIVER.sch]
2017-03-05 Fixed silkscreen for bottom layer
    [MOTOR_DRIVER.brd, MOTOR_DRIVER.sch]
2017-03-06 Added current sense, needed to change a few pins on upper left. Check routing again. Changed rec header to female
    [MOTOR_DRIVER.brd, MOTOR_DRIVER.sch]
2017-03-06 changed voltage regulator cap
    [MOTOR_DRIVER.brd, MOTOR_DRIVER.sch]
2017-03-07 Updated top routing to include current sense resistor at 135 degree angle.
    4pcb should be checked to see if they can make the pads for the angled
    component
    [MOTOR_DRIVER.brd, MOTOR_DRIVER.sch]
2017-03-07 Fixed errors on top board and moved current sense amp to top
    [MOTOR_DRIVER.brd, MOTOR_DRIVER.sch]
2017-03-08 Fixed missing wire
    [MOTOR_DRIVER.brd]
2017-03-08 Fixed missing motor_high_top pin, now I_SENSE_LOW_TOP
    [MOTOR_DRIVER.brd, MOTOR_DRIVER.sch]
2017-03-08 Routed lower board and combined all boards
    typical_4pcb.dru lists design errors for the width of the traces, but
    the file is outdated and trace widths correspond with 4pcb's website
    [MOTOR_DRIVER.brd, MOTOR_DRIVER.sch]
2017-03-08 added several resistor values
    [MOTOR_DRIVER.brd, MOTOR_DRIVER.sch]
2017-03-08 made overall dimensions smaller, moved I_SENSE and added back a GPIO. made an attempt at a gerber file
    [MOTOR_DRIVER.brd, MOTOR_DRIVER.sch]
2017-03-09 Added silkscreen for most headers
    [MOTOR_DRIVER.brd, MOTOR_DRIVER.sch]
2017-03-09 Added more silkscreen
    [MOTOR_DRIVER.brd, MOTOR_DRIVER.sch]
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2017-03-12 gathered sample camera data; initial MATLAB visualization code
    [cam_sample.csv, cam_sample02.csv]
2017-03-12 added thermal things for LEDs
    [MOTOR_DRIVER.brd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]
2017-03-12 fixed thermals
    [MOTOR_DRIVER.brd]
2017-03-12 Changed drill hole sizes
    [MOTOR_DRIVER.brd, MOTOR_DRIVER.sch]
2017-03-13 changed some drill sizes to .8 instead of .6. fixed some clearance issues with LED
    [MOTOR_DRIVER.brd, MOTOR_DRIVER.sch]
2017-03-13 larger pad for LEDs
    [MOTOR_DRIVER.brd]
2017-03-14 added folder with version with less holes
    [MOTOR_DRIVER.brd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]
2017-03-16 reduced GPIOs on teensy and started on atmega
    [MOTOR_DRIVER.brd, MOTOR_DRIVER.sch]
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2017-03-17 more edits. will try rerouting top after this one
    [MOTOR_DRIVER.brd]
2017-03-17 new caps rerouted a lot, thinner wires, wider clearances
    [MOTOR_DRIVER.brd, MOTOR_DRIVER.sch]
2017-03-17 re did tstop and bstop
    [MOTOR_DRIVER.brd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]
2017-03-17 several duplicated versions. duplic_everything is the one to use
    [MOTOR_DRIVER_dupl.brd, MOTOR_DRIVER_dupl.sch, MOTOR_DRIVER_dupl_everything.brd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]
2017-03-18 added version with mounting holes
    [MOTOR_DRIVER_dupl_everything_mount_holes.brd, MOTOR_DRIVER_dupl_everything_mount_holes.sch]
2017-03-20 added more mounting holes and headers, renamed switches. ordered this 3/20
    [MOTOR_DRIVER_dupl_everything_mount_holes.brd, MOTOR_DRIVER_dupl_everything_mount_holes.sch]
2017-04-11 some modified board and new driving code for single thread and half or full bridge
    [MOTOR_DRIVER.GBL, MOTOR_DRIVER.GBO, MOTOR_DRIVER.GBS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]
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2017-04-13 fixed pin numbers for driving and steering. Increased buffer size, shrank max speed. changed led status lights
2017-04-13 old camera mount parts
    [base.SLDPRT, base.STL, part 2.SLDPRT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]
2017-04-16 new HES mounts 20 mill error
    [assem 2 mill.SLDASM, mount 2 mill.SLDPRT, mount 2 mill.STL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]
2017-04-16 also a 3 mill error version
    [assem 2 mill (1).SLDASM, mount shorter 3 mill.SLDPRT, mount shorter 3 mill.STL]
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2017-04-16 added speed sensing, more state flow. pauses when battery low or going too fast
    [GP_teensy.ino]
2017-04-22 Fixed conflict in stateCheck()
    [GP_teensy.ino]
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2017-04-26 changed state flow and drive modes. some unknown issue with Tx pausing
    [GP_teensy.ino]
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2017-04-30 modified for matlab telemetry. current issues are still with reading negative speed.
    [GP_teensy.ino]
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2017-05-05 fixed Tx state flow a little
    [GP_teensy.ino, bluetoothFUNC.ino, cameraFUNC.ino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]
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2017-05-07 added mode for slowing down based on curvature. one thats a linear function, and one that drops a certain number if curvature is too high
    [GP_AVR.ino, motors.h, motorsFUNC.ino]
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2017-05-07 good soft start and reverse half
    [GP_teensy.ino, motorsFUNC.ino]
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2017-05-07 Revert "Modified kSteering as a function of speed."
    This reverts commit 778f44da520788cfeae3ac430b496e4d0573a8e8.
    [GP_teensy.ino, cameraFUNC.ino, motors.h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]
2017-05-07 median filtered, modified battery warnings. changed line fault conditions, no longer working
    [GP_teensy.ino, camera.h, cameraFUNC.ino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]
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

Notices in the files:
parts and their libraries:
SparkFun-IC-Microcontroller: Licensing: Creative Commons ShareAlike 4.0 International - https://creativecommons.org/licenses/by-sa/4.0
